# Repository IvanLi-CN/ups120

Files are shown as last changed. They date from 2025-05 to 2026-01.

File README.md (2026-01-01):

# UPS120 Firmware (Split Architecture)

This repository now hosts two firmware targets under a unified workspace:

- Smart Battery Controller: `STM32L051C8T6` (battery BMS + charger orchestration)
- UPS Main Controller: `ESP32S3FH4R2` (system coordination; active development)

Refer to [WORKFLOW.md](WORKFLOW.md) and [DESIGN_MEMORANDUM.md](DESIGN_MEMORANDUM.md) for project context.

Flashing/reset/log capture is routed through `mcu-agentd` (see `docs/mcu-agentd.md`).

## Repository Layout

- `firmware/smart-battery/`: Rust + Embassy firmware for `STM32L051C8T6`
- `firmware/ups-main/`: Rust firmware for `ESP32S3FH4R2` UPS main controller (active development)
- `embassy/`, `bq76920/`, `sc8815/`: Local dependencies and submodules

## Smart Battery (STM32L051C8T6)

- MCU: `STM32L051C8T6` (Cortex‑M0+)
- BMS: `BQ76920`
- Charger: `SC8815`
- Embassy setup: async I2C shared-bus; no USB on L0

I2C pins (per CubeMX .ioc):
- `I2C2` (INNER bus): `PB10` = SCL, `PB11` = SDA
- `I2C1` (SMBus alert mode enabled): `PB6` = SCL, `PB7` = SDA, `PB5` = SMBA

GPIO mapping (netlist‑accurate; the `.ioc` file is slightly stale):
- `PA9`: `PSTOP` (GPIO Output) — HIGH = power stage gated, LOW = enable
- `PA10`: `CE` (GPIO Output) — LOW = charger enabled
- `PA5`: `LEDK` (TIM2_CH1 alternate, open‑drain LED in firmware)
- `PA2`: `PCHG_EN` (GPIO Output)  *(per .ioc; see PCB netlist for the exact pad)*
- `PA0..PA3`: `ADC_IN0..3` for the 4× NTC network (`TS45`/`TS34`/`TS23`/`TS12` → pack temperatures)
- `PH0`: `EXIT_SHIPMODE` (GPIO Output) — routed via D3 clamp onto BQ76920 `TS1`, used to wake from SHIP mode
- `PB1`: `ALERT` (EXTI1)
- `PB2`: `INNER_INT` (EXTI2)

### Build & Run

From the repository root:

1) Ensure targets are installed: `rustup target add thumbv6m-none-eabi`
2) Build: `just sb-build`
3) Flash: `just sb-flash`
4) Monitor: `just sb-monitor`

Notes:
- The on-target workflow is mediated by `mcu-agentd` (do not call `probe-rs` directly).
- If you use a custom `CARGO_TARGET_DIR`, update `mcu-agentd.toml` accordingly.

### Notes on Port

- Migrated from `STM32G431` to `STM32L051C8T6` feature flags in `embassy-stm32`.
- Removed USB stack/tasks; L051 parts do not provide USB FS.
- I2C runs at 100 kHz async; DMA channel placeholders may be adjusted per board.

## UPS Main (ESP32S3FH4R2)

`firmware/ups-main` is an actively developed Rust firmware using `esp-hal` on ESP32-S3. System coordination, fan control, and I2C integrations (e.g., smart‑battery telemetry) are incrementally landing here.

### Build & Run

From the repository root:

1) Build: `just ups-build`
2) Flash: `just ups-flash`
3) Monitor: `just ups-monitor`

## License

MIT — see [LICENSE](LICENSE).

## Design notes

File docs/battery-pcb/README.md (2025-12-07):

# Smart Battery Module

## Overview

The smart battery board manages a 5-series stack of 26650 cells for the UPS120 platform. A TI **BQ7692003** analog front end measures every cell tap, while the PCB routes each tap through 100 ohm / 1 uF RC filters to keep the monitor within its input slew limits. The stack exports `BAT` as the pack positive node and `BGND` as the pack negative reference.

## Cell and Pack Specifications

- **Cell**: Planned 26650-format LiFePO₄ cell rated 3.2 V nominal, ~4.0 Ah capacity, ≤25 mΩ internal resistance, and up to 5C discharge capability (per supplied datasheet).
- **Environmental limits**: Charge temperature 0 °C to 45 °C per the cell spec; project discharge temperature currently constrained to 0 °C to 50 °C to preserve lifespan.
- **Physical**: Cylindrical can ~26 mm × 65 mm, mass approximately 85 g ± 2 g.
- **Pack topology**: 5-series, 1-parallel (5S1P) stack managed by the board’s cell monitor.
- **Pack ratings**: Nominal voltage about 16 V (5 × 3.2 V) with planned operating window 12.5 V (discharge cutoff) to 18.0 V (charge cutoff). Total energy around 64 Wh at nominal capacity.
- **Charge cutoff**: System charger terminates near 18.0 V pack, equivalent to ~3.6 V per cell, consistent with the cell datasheet limit.
- **Discharge cutoff**: Smart-battery firmware configures the BQ7692003 undervoltage trip at 2.50 V per cell (`firmware/smart-battery/src/main.rs:201`), producing the 12.5 V pack cutoff target above.
- **Charging architecture**: On-board charger regulates pack current at approximately 1 A with constant-current/constant-voltage behavior coordinated by the MCU.
- **Continuous current**: Power-stage sizing currently aligns with the cell’s 5C guidance (~20 A) while considering MOSFET thermal headroom and shunt limits; adjust fuse/shunt if future validation dictates tighter limits.

## Functional Blocks

- **Protection and switching** - A TI **BQ76200** high-side driver coordinates the charge, discharge, and pre-charge MOSFET banks. The low-value current-sense shunt between `BGND` and `GND` captures pack current, while a resettable fuse protects the housekeeping supply input.
- **Temperature sensing** - The PCB includes an optional 10 kΩ NTC footprint on the BQ7692003 TS1 pin, but **current production hardware does not populate this device**. BQ7692003 is configured to use its internal temperature sensor only; pack temperatures come from the 4× external NTC network into the STM32 ADC plus the TMP75 near the charger.
- **Housekeeping power** - A **TPS62933** buck converter drops the pack voltage to the `3V3_OUT` rail through a shielded inductor and bulk storage capacitor. An **LM66100** ideal diode isolates the regulated `3V3` rail, allowing external 3.3 V injection via the VBUS header without back-feeding the buck. Distributed 1 uF and 100 nF capacitors decouple the MCU and analog front ends.
- **System controller** - An **STM32L051C8** MCU supervises the AFE through an internal I2C bus and bridges to the host-facing bus. A resistor network provides 3.3 V pull-ups, and dedicated alert and interrupt lines land on the MCU for fault handling.
- **External interfaces** -
  - 1.0 mm 5-pin harness reserved for internal signal acquisition, carrying the monitored I2C pair plus the alert line, 3.3 V reference, and return.
  - 1.0 mm 4-pin SWD header dedicated to MCU debug access (`SWDIO`, `SWCLK`, supply, return).
  - 2.54 mm 4-pin power inlet routed to the on-board charger, intended for the external charger supply input (VBUS and ground pairs).
  - Dual 6-pin high-current terminals exporting the battery stack positive and negative nodes for pack integration.
- **User interaction** - A top-side reset switch reaches the MCU reset pin, while dedicated LED driver outputs fan out for front-panel indicators.

## Reference Netlist

The schematic netlist exported from EasyEDA lives in `netlist_battery.enet`. Each component entry includes manufacturing metadata (LCSC code, footprint ID, datasheet URL) to keep fabrication and BOM exports aligned with the PCB project.

## Directory Layout

- [`README.md`](README.md) - High-level description of the smart battery PCB (this file).
- [`netlist_battery.enet`](netlist_battery.enet) - EasyEDA JSON netlist for the smart battery design.
- [`tps62933_enable_control.md`](tps62933_enable_control.md) - Notes about the TPS62933 enable and power-sequencing logic.
- [`vbats_cutoff_calibration.md`](vbats_cutoff_calibration.md) - SC8815 VBATS divider hardware plus 18 V charge-cutoff calibration procedure.
- [`hardware_protection_tps3823_tmp75.md`](hardware_protection_tps3823_tmp75.md) - Consolidated hardware fault-chain design notes (final build uses scheme D: TMP75 + MCU AND gating).
- [`battery_temp_sensing.md`](battery_temp_sensing.md) - Analog temperature sensing topology for the pack.
- [`component-candidates/`](component-candidates) - Sourcing digests and option tables ([`schmitt_trigger_nand_options.md`](component-candidates/schmitt_trigger_nand_options.md), [`nand_gate_options_youxin.md`](component-candidates/nand_gate_options_youxin.md), [`or_gate_options_youxin.md`](component-candidates/or_gate_options_youxin.md), [`single_inverter_options.md`](component-candidates/single_inverter_options.md), [`three_input_and_gate_options_youxin.md`](component-candidates/three_input_and_gate_options_youxin.md), [`temperature_protection_tmp.md`](component-candidates/temperature_protection_tmp.md), [`watchdog_pricing_taobao.md`](component-candidates/watchdog_pricing_taobao.md), [`youxin_schmitt_single_nand.md`](component-candidates/youxin_schmitt_single_nand.md)).

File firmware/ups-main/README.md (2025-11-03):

# UPS Main Controller (ESP32-S3)

This directory contains the UPS main controller firmware targeting `ESP32‑S3` (Rust + esp-hal for MVP; versions aligned with the reference project).

- Toolchain: Rust + esp-hal (Xtensa). Requires `espflash`, Xtensa toolchain, and `xtensa-esp32s3-none-elf` target.
- Hardware docs:
  - `docs/mcu_hardware.md` (schematic transcription + verified GPIO mapping)
  - `docs/fan_control_spec.md` (2-wire fan control specification)
  - `docs/fan_control_requirements.md` (current fan-control requirements & acceptance checklist)
  - `docs/archive/pwm_fan_control_circuit_design.md` (legacy 3-wire fan design for reference)
  - `docs/datasheets/HUSB305-01.md` + `.pdf` (Type‑C source controller STAT/PG behavior)
- Build:
  - `make -C firmware/ups-main build` (or `ups-build` at repo root)
  - Flash + monitor: `make -C firmware/ups-main run PORT=/dev/tty...` (or `ups-run` at repo root)
- Status: MVP bring‑up scaffolded (GPIO/I2C/SPI/LEDC init; beep + fan smoke test).

Pin mapping in code follows `docs/mcu_hardware.md` exactly:
- Buttons (pull‑up): GPIO0/1/2/4/5
- RESET#(TCA6408A): GPIO6 (output-high)
- INTn (open-drain, low‑active): GPIO7 (input pull‑up)
- I2C0: SDA=GPIO8 SCL=GPIO9 @400kHz
- SPI LCD: DC10 MOSI11 SCLK12 CS13 RST14
- USB2_PG: GPIO21 (input pull‑up)
- FAN: EN=GPIO39, PWM=GPIO40@25kHz
- BUZZER: GPIO38@2kHz

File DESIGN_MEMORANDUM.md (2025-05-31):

# Design Memorandum - UPS Project

This document records key design decisions, observations, and debugging notes for the UPS project firmware.

## BQ25730 Configuration and ADC Readings

### Initial `cell_count` Configuration for BQ25730

* **Decision (User Input)**: The `cell_count` parameter passed to `Bq25730::new()` in the firmware is intentionally set to `4`.
* **Rationale**:
  * The BQ25730 is primarily designed for 3.7V/4.2V Li-ion cells. Configuring the `CELL_BATPRESZ` pin for a 5-cell LiFePO4 pack might lead to a default overvoltage protection (OVP) setting around 21V if interpreted as 5S Li-ion.
  * To ensure a safer default OVP level (e.g., around 16.8V for 4S Li-ion) upon initial power-up or in case of I2C communication failure before full configuration, a 4-cell equivalent hardware/default configuration is preferred.
  * The intention is to then use I2C commands to fine-tune all necessary parameters (charge voltage, current, protection thresholds) to precisely match the 5S LiFePO4 battery pack (e.g., ~18V charge voltage).
* **Implication**: This means the firmware must correctly adjust all relevant settings via I2C to override any 4-cell defaults and properly manage the 5S LiFePO4 pack. The `cell_count` parameter passed to `Bq25730::new()` directly influences the `offset_mv` used in `VBAT` and `VSYS` ADC conversions within the `bq25730_async_rs` driver. If the hardware `CELL_BATPRESZ` configuration implies a different cell count than what's passed to `new()`, this can lead to ADC reading inaccuracies.

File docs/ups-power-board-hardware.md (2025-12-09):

# UPS 电源板硬件概览

## 总览

- 电源板通过多条控制与监测线缆连接至 ESP32 主控，承担 UPS 外部输入调节、放电路径控制与状态监测职责。
- 板上核心器件包括电源转换、热管理、输入保护以及电流电压测量等子系统。

## 关键器件清单

| 器件 | 主要作用 | 关键接口 / 配置 |
| --- | --- | --- |
| SC8815 | UPS 放电升/降压，稳定输出电压 | `CE`、`PSTOP`、`ADIN` |
| TCA6408A | 通过 I²C 扩展数字 IO，驱动/侦测 UPS 状态 | `P0`–`P7`、`RESET#`、I²C 地址 `0x20` |
| TPS2490 | 受控热插拔控制器，管理外部输入使能 | `EN`、`PG` |
| INA226 | I²C 功率监测，测量 UPS 外部输入功率 | `SDA`、`SCL`、`Alert` |
| FNTC0402X103F3380FB | 与 SC8815 形成热感测电路的 NTC 热敏电阻 | `ADIN` |
| 43 kΩ 上拉电阻 | 为 SC8815 `ADIN` 提供 3.3 V 基准 | `ADIN`、`3V3` |

## 互连关系

- **SC8815**
  - `ADIN` 同时连接 FNTC0402X103F3380FB NTC 和 43 kΩ 上拉电阻，组成温度分压网络。
  - `CE`（芯片使能）与 `P1`（TCA6408A 口线）相连，ESP32 可经 I²C 控制启停转换。
  - `PSTOP` 与 `P2`（TCA6408A）连接，用于控制放电停止逻辑。

- **TCA6408A I/O 扩展器**
  - 经 I²C 总线 (`SCL`/`SDA`) 连至 ESP32 主控。
  - I²C 地址配置为 `0x20`（A0–A2 接地）。
  - `P0` 读取/驱动 `IN_PG` 网络，实现输入电源良好状态反馈。
  - `P1` 输出控制 SC8815 `CE`。
  - `P2` 输出控制 SC8815 `PSTOP`。
  - `P3` 连接智能电池 `ALERT`（透传到 BQ76920），用于异常报警。
  - `P4`–`P7` 当前悬空未使用。
  - `RESET#` 由 ESP32 直接驱动，确保 I/O 扩展器复位同步。

- **TPS2490 热插拔控制器**
  - `EN` 接 `IN_EN` 网络；低电平时切断 UPS 外部输入。
  - `PG` 为开漏 Power Good 指示脚，由 TPS2490 根据外部功率 MOSFET 的 `VDS` / 启动状态机 / 保护状态综合判定；导通良好时释放为高（上拉后读到高电平），启动中、UVLO、限流或保护时拉低。
  - `PG` 直接并入 `IN_PG` 网络，送至 TCA6408A `P0` 与 ESP32，仅表达“输入功率路径是否被判定为良好”，并不等同于“适配器电压存在”。

- **INA226 功率监测**
  - 与 ESP32 共享 I²C 总线，实时报告 UPS 外部输入电压、电流与功率。
  - `Alert`（若使用）可与 TCA6408A 或 ESP32 中断输入共享，辅助告警逻辑。

- **ESP32 主控**
  - 通过 I²C 控制 TCA6408A 与 INA226，间接管理 SC8815 放电和输入监测。
  - 直接线控 TCA6408A `RESET#` 以及 `IN_EN` 网络（若由 ESP32 驱动 TPS2490 EN）。

## 信号网络简述

- `IN_EN`：由 ESP32 控制，使 TPS2490 允许或切断外部输入。
- `IN_PG`：TPS2490 `PG` 开漏指示，馈入 TCA6408A `P0` 与 ESP32，表示“功率 MOSFET 路径良好/未处于保护”，不直接代表外部母线电压是否超过某阈值。
- `ALERT`：智能电池（BQ76920）故障或保护触发时输出高电平，通过 TCA6408A `P3` 传回 ESP32。
- `ADIN`：SC8815 热补偿输入，结合 NTC 与 43 kΩ 上拉监控温度。

## AC GOOD 信号路径概览

- **PG 原始层**：TPS2490 `PG`（开漏，良好时被上拉为高）→ `IN_PG` 网络 → TCA6408A `P0` → `in_pg_raw`（固件中读取的布尔，保留原始电平含义）。
- **电压在线层**：INA226 通过同一 I²C 总线测量输入母线电压，固件字段 `vin_meas_mv`；布尔 `vin_online`（推荐命名）= `vin_meas_mv > UPS_VBUS_AC_ONLINE_MV = 11.5 V`。
- **综合 AC GOOD 层**：`power::power_task` 将 `PG` 语义化布尔（建议名 `pg_asserted`）与 `vin_online` 组合得到 `ac_present`，并施加 10 s 稳定窗口得到 `ac_stable`。UI、充电/放电策略均消费 `ac_present` / `ac_stable`，不直接使用 `IN_PG`。

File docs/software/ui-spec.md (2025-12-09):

# UPS120 屏幕显示规范（v1）

适用硬件：160×50 像素、16 位 RGB565 屏。

本规范定义：坐标系、色彩与文本规范、公共组件、启动屏行为、仪表盘布局与数据格式、故障显示规则与更新频率。目的是在受限像素与带宽下保证一致、清晰、可靠的显示。喵～

## 1. 屏幕与坐标

- 分辨率：`160(w) × 50(h)` 像素，坐标原点在左上角。
- 颜色：RGB565（`rrrrr gggggg bbbbb`）。推荐调色板见下。
- 安全边距：左右各 `4px`，上下各 `1px`；在 `1 + 4×12 = 49` 的排版中仍保留 1px 余量用于呼吸空间。
- 建议基准网格：`8×12` 像素字符格（宽度 8px、行高 12px，包括 7×10 字形与 2px 行距），全屏可视为约 `20 列 × 4 行` 的等宽布局。

## 2. 调色板与语义颜色（含元素色常量）

为减少抖动与提升可读性，限定小而稳定的色表：

- `BLACK`  0x0000 背景、遮罩
- `WHITE`  0xFFFF 主要文字
- `GRAY`   0x8410 次要文字/分隔线
- `GREEN`  0x07E0 正常/进度条填充、功率（Power）
- `YELLOW` 0xFFE0 警告（高温、接近阈值）
- `ORANGE` 0xFD20 电压（Voltage）
- `RED`    0xF800 故障/禁止、电流（Current）
- `CYAN`   0x07FF 数据标题与单位点缀

色彩使用规则：

- 背景始终为黑色（启动屏、仪表盘一致）。
- 标题/标签使用 `CYAN`；单位默认 `WHITE`。
- 进度条填充 `GREEN`，异常改为 `RED`。
- 警戒区间（如温度接近上限）可将数值着色为 `YELLOW`。
- 元素专色（仪表盘）：
  - 电压（V）→ `ORANGE`
  - 电流（A）→ `RED`
  - 功率（W）→ `GREEN`

## 3. 字体与排版

- 字体：等宽 `7×10` 点阵，字符格宽 `8px`、行高 `12px`（其中 2px 作为行间距/前导）；示意图与固件渲染均使用同一套位图字形，禁用抗锯齿。
- “℃”绘制：在 `C` 前方 3px 位置放置一个 `2×2` 的度数点（顶边位于基线之上 1px），再绘制 `C` 字形，确保像素对齐。
- 数值与单位必须紧邻：如 `48.0V`、`120W`、`32C`、`45%`。
- 对齐：
  - 标签左对齐，数值列右对齐/定宽；
  - 四行均使用 `y = 1 + n×12` 的基线，保证跨模式切换时不抖动。
- 省略或无数据统一显示为 `--`，与标签留一个字符格间距。
- 单元宽度：所有文字均落在 `8px` 宽度的字符单元上，默认列宽如下（括号内为示例）：
  - 标签列：`4` 单元（`IN␠␠`，两格空白确保对齐）。
  - 电压列：`5` 单元（`12.3V` / `9.87V` / `>99V`）。
  - 电流列：`4` 单元（`2.5A` / `12A` / `>99A`）。
  - 功率列：`4` 单元（`120W`，>999W 时显示 `999W`）。
  - `SoC`：`4` 单元右对齐（`85%` / `100%`）。
  - 温度：`4` 单元（`-9C` / `105C`，附带 2×2 度数点）。
  - 风扇：`4` 单元（`45%` / `100%`）。

### 3.1 字段字符宽度约束

| 项目 | 字符宽度 | 说明 |
|---|---|---|
| `MODE:` 标签  | 6 | 固定文案，冒号后带一个空格。 |
| `IN` 标签 | 4 | 文案后补足 2 个空格（`"IN  "`），用于对齐行内数值。 |
| `OUT`/`CHG` 标签 | 4 | 文案后保留 1 个空格即可（`"OUT "`、`"CHG "`）；无需额外对齐。 |
| `SoC` 电量 | 4 | 右对齐显示 `85%`；`100%` 时占 4 字符。 |
| 电压 | 5 | 常规 `12.3V` ~ `21.0V`，格式 `xx.xV`；`≥100V` 时退化为 `>99V`。 |
| 电流 | 4 | `<10A` 用 `x.xA`；`10A~99A` 用整数（`12A`）；`≥100A` 显示 `>99A`。 |
| 功率 | 4 | `xxxW`；`≥1000W` 时夹止为 `999W`。 |
| 温度 | 4 | `32C` / `-5C` / `105C`，取值范围 `-99`～`199`；度点独立 2×2。 |
| 风扇转速 | 4 | `45%` / `100%`，右对齐；无数据时显示 `--%`。 |

所有行内间隔默认 1 个字符单元（8px），仅在需要强调分隔时再留出额外空白，但严禁与数值列重叠。

## 4. 公共组件

### 4.1 分隔线（可选）

- 颜色 `GRAY`，`1px` 水平线，用于分区但不喧宾夺主。

### 4.2 进度条（启动屏使用）

- 外框：宽 `152px`、高 `8px`，居中放置，左右/上下各留安全边距。
- 填充：`GREEN` 自左向右增长；错误态保持在当前进度并改为 `RED`。
- 百分比文本（可选）：在进度条上方居中显示，如 `INIT 72%`。

## 5. 启动屏（Boot）

用途：硬件上电后硬件自检与外设初始化阶段的显示。背景黑色。

示意图（像素网格放大显示；已调整避免文本与进度条重叠）：

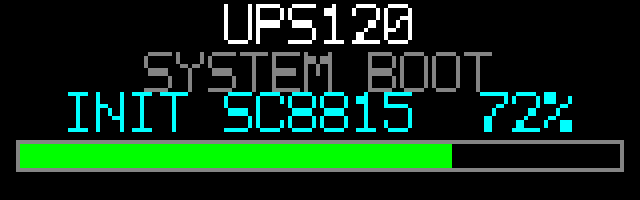
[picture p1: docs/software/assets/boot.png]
Boot Screen Mockup


显示元素：

- 标题（第一行居中）：`UPS120` 或项目名（白色）。
- 子标题（可选，次要信息）：`System Boot` 或版本号（灰色）。
- 进度条：见 4.2。
- 状态行（底部或进度条上方一行）：显示当前步骤名称（如 `Probe INA226`、`Init SC8815` 等）。

行为流程：

1. 上电进入启动屏，进度自 `0%` 增长至 `100%`。
2. 每完成一个外设/模块自检或初始化步骤，进度递增并更新状态行。
3. 若所有步骤成功（100%）：
   - 进度条填满后停留 `300–600ms`，自动切换至仪表盘。
4. 若任一步骤失败（设备故障）：
   - 停留在启动屏，不跳转。
   - 进度条颜色切换为 `RED`；
   - 状态区域列出具体故障硬件（见下“故障显示”）。

故障显示规范：

- 标题：`Hardware Fault`（红色）。
- 列表逐条显示（白色标签 + 红色状态）：
  - `Battery MCU (STM32L051): FAIL`
  - `SC8815: FAIL`
  - `TCA6408A@0x20: FAIL`
  - `INA226: FAIL`
- 多故障时按优先级排序（上至下）：`Battery MCU > SC8815 > INA226 > TCA6408A > 其他`。
- 若存在可恢复性建议（例如松脱/重插），可在底部灰色小字提示；不做交互决策（按键处理由上层定义）。

数据对接（建议）：启动阶段各子系统上报 `step_id`、`step_name`、`ok/err`，UI 侧映射进度百分比；错误时附 `fault_list`。

## 6. 仪表盘（Dashboard）

作为主屏幕常驻界面，显示系统状态与关键电参。采用“四行”布局，提升在 160×50 下的可读性与留白。第一行右上角“电池电量区域”轮播显示：

- 电量百分比（`SoC %`）
- 电池包电压（格式 `xx.xV`，示例 `16.1V`）

轮播节奏默认每 2 秒切换一次；当任一数据不可用时显示 `--` 并继续轮播。

示意图（像素网格放大显示；四行布局，元素着色且控宽不越界）：

- 放电（第三行显示 SC8815 测得的 OUT 三元组）：
  
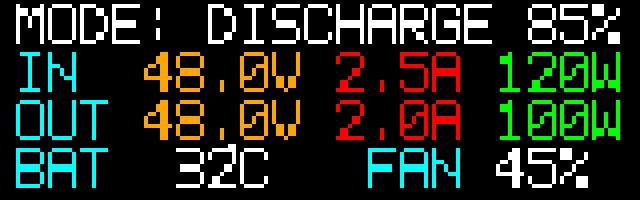
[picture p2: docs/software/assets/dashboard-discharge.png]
Dashboard Discharge
  

- 充电（第三行显示 CHG 功率）：
  
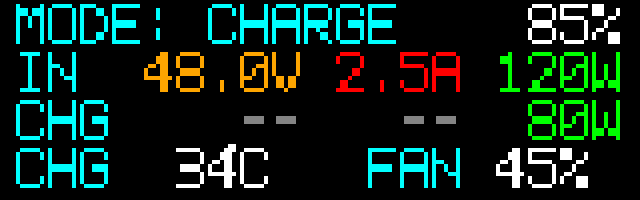
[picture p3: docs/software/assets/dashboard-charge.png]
Dashboard Charge
  

- 就绪（第三行显示自上次放电结束的时长）：
  
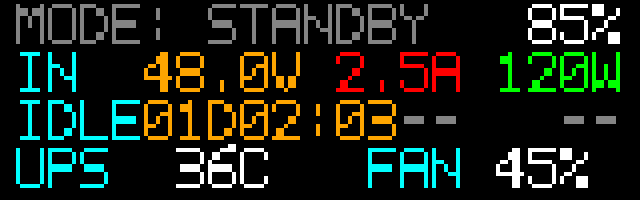
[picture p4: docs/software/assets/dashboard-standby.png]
Dashboard Ready
  

- 智能电池故障（第四行切换为故障视图，显示 `FAULT: <code>`）：
  
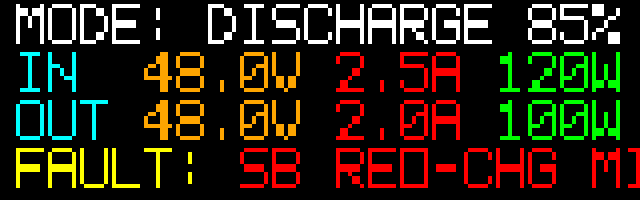
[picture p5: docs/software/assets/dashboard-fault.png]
Dashboard Fault
  

### 6.1 显示内容（必选）

- 工作模式（文本）：`Charge` / `Ready` / `Discharge` / `LowBatt`。
- 输入电压（V）。
- 输入电流（A）。
- 输入功率（W）。
- 充电功率（W，非充电则 `--`）。
- 输出电压（V）。
- 输出电流（A）。
- 输出功率（W）。
- 电池温度（℃，显示为 `BAT xx℃`）。
- UPS 温度（℃，来自 SC8815 的 ADIN，显示为 `UPS xx℃`）。
- 风扇转速（%，按逻辑占空比换算）。

#### 模式语义与判定规则

- 所有 `MODE` 状态均由 UPS 主控 ESP32 决策；STM32 智能电池板只提供测量数据（分节电压/电流/温度、`STATE_FLAGS`、`CHG_PAUSE_CAUSE` 等）和一致性校验，不直接驱动 UI 模式切换。
- AC 状态来源固定为 `PowerState.ac_present / ac_stable / vin_meas_mv`（由 TPS2490 PG + INA226 组合，见 `charging_policy.md`），UI 不使用 STM32 `STATE_FLAGS.AC_PRESENT`。
- ESP32 在电源任务中基于自身维护的 `PowerState`（AC/OUT 状态、单体/包电压、温度等）以及内部 `out_enabled`、充放电策略状态裁决 `mode` 字段，并将该字段作为唯一权威的仪表盘模式喂给 UI。

- 四种工作模式语义：
  - `Charge`：检测到 AC 存在且充电策略允许时（`vin_ok_for_charge=true` 且电池/温度安全），进入充电模式；第三行采用 `CHG <功率>` 布局。
  - `Discharge`：`out_enabled=true` 且功率实际流向负载时（由 UPS 侧 SC8815 的 OUT 测量确认），进入放电模式；第三行采用 `OUT <V/A/W>` 布局。
  - `Ready`：不充不放（既未处于 Charge 也未处于 Discharge），OUT 功率级可随时开启，电池与系统健康且未触发 LowBatt；第三行采用 `IDLE <时长>` 布局，时长统计自上次放电结束起。
  - `LowBatt`：在基础模式为 Ready 的前提下，仅用于表示“电量偏低但当前没有 AC 可用”的状态；第三行继续沿用 Ready 或 Discharge 的布局，仅通过第一行 `MODE: LOWBATT` 与 SoC 颜色强调电量低。

- `LowBatt` 触发规则：
  1. 先按上述规则判定基础模式为 `Ready`；
  2. 若此时任意一节电芯电压 `< 3.2V`，进入“电量低流程”；
  3. 在电量低流程中（`ac_present` 由 TPS2490 PG + INA226 VIN 判定，详见 `charging_policy.md`）：
     - 若 `ac_present = true`：ESP32 不进入 `LowBatt`，而是直接切换到 `Charge` 并按充电策略尝试启动充电；
     - 若 `ac_present = false`：ESP32 才将 MODE 切换为 `LowBatt`，表示“电池很想充但没有 AC 可用”，UI 以 `MODE: LOWBATT` + SoC 变红提示。

### 6.2 四行布局（示意）

```
┌──────────────────────────────────────────────────────────────┐
│ MODE: DISCHARGE                                  85%        │  ← 行1（状态+右上角电量区，右对齐；轮播 % 与 V）
├──────────────────────────────────────────────────────────────┤
│ IN  48.0V 2.5A 120W                                        │  ← 行2（输入三元组：标签 4 单元 + 5/4/4 列）
│ OUT 48.0V 2.0A 100W                                        │  ← 行3（放电：输出三元组同列宽）
│ BAT    32C   FAN  45%                                      │  ← 行4（温度槽位轮播 + FAN，列宽 4/4/3/4；无故障时）
└──────────────────────────────────────────────────────────────┘
```

说明：

- 行1：左侧 `MODE: <Charge|Ready|Discharge|LowBatt>`；右上角电量区轮播显示 `SoC %` 与电池电压 `xx.xV`。`SoC` 按阈值变色（≤30% `YELLOW`，≤15% `RED`）；显示电压时使用电压专色 `ORANGE`。
- 行2：输入三元组（V/A/W，专色显示，见 6.4）。
- 行3：按模式动态显示（**由 ESP32 主控单向裁决**；STM32 智能电池仅作为测量与一致性校验来源，不参与模式判定）：
  - 充电（`Charge`）时：显示 `CHG <功率W>`（功率数字用 `GREEN`），其余两列以 `--` 灰显。
  - 就绪（`Ready`）时：显示 `IDLE <时长>`，时长格式 `DDdHH:MM`（例如 `01d02:03`），未使用列显示 `--`。
  - 放电（`Discharge`）时：显示 `OUT <V/A/W>`，数值来自 SC8815 的测量。
  - 电量低（`LowBatt`）时：第三行布局**不因电量低而改变**：
    - 若当前仍在放电（`out_enabled=true` 且有实际功率输出），第三行继续使用 `OUT <V/A/W>`；
    - 若当前处于就绪（未放电），第三行继续使用 `IDLE <时长>`。
    `LowBatt` 仅通过第一行 `MODE: LOWBATT` 和 SoC 变红提示电量低，避免第三行再引入额外文案变化。
- 行4：温度/风扇信息：`BAT`（电池）、`UPS`（UPS/SC8815 ADIN）、`FAN`（百分比）。当检测到智能电池或充电链路故障时，行4整体切换为“故障视图”，不再显示温度/FAN。
- 各行基线为 `y = 1 + 行号×12`（0-index），字符上边缘对齐，行间保持 2px 呼吸空间。
- 行4温度轮播：每帧在 `BAT` 与 `UPS` 之间切换，仅展示一个温度槽位，右侧固定 `FAN` 列；示例固件以 2 秒刷新一次，可按需求缩短至 1 秒；当任一温度不可用时显示 `--` 并继续轮播。

两列对齐与等宽：

- 标签列（`MODE/IN/OUT/CHG/IDLE/BAT/UPS/FAN`）左对齐，数值列右对齐；单位紧贴数值。
- 固定列宽：标签 `4` 单元 → 电压 `5` 单元 → 电流 `4` 单元 → 功率 `4` 单元，列间默认 `1` 单元间隔；右上角电量区：
  - 展示 `SoC %` 时占 `4` 单元（例如 `85%`）。
  - 展示电压时占 `5` 单元（例如 `16.1V`）。
  - 布局需保证右上角 5 单元不与左侧 `MODE` 文本发生重叠；当空间不足时应截断 `MODE` 文本末尾字符以避免覆盖（优先保证电量区完整显示）。
- `IN` 等标签不足 4 字符，通过尾部空白补齐，确保电压列起始对齐；数值在列内右对齐，空白自然留在左侧。
- 行4 使用 `4/4/3/4` 单元布局（温标签/温值/FAN 标签/FAN 数值），与上方三行保持同一字符网格。
- 占位符统一为 `--`，渲染时使用 `GRAY`；`FAN` 无可用数据时显示 `--%`。

### 6.3 数值格式与单位

- 电压（V）：
  - `<10V`：`x.xxV`，保留两位小数（如 `9.87V`）。
  - `10V–99.9V`：`xx.xV`，保留一位小数（如 `48.0V`）。
  - `≥100V`：显示 `>99V`，提示超出量程。
- 电流（A）：
  - `<10A`：`x.xA`，保留一位小数（如 `2.5A`）。
  - `10A–99A`：整数右对齐（`12A`），不带小数。
  - `≥100A`：显示 `>99A`。
- 功率（W）：四舍五入到整数，右对齐显示 `xxxW`；超过 `999W` 时夹止为 `999W`。
- 温度（℃）：整数（`32C` / `-5C` / `105C`），附带 2×2 度数点；数据范围限制在 `-99`～`199`℃。
- 风扇（%）：整数右对齐（`45%` / `100%`）。
- 未知/无效：统一输出 `--`（温度 `--C`，风扇 `--%`，其他列 `--`）。

### 6.4 着色规则（含元素专色）

- `MODE`：`Charge` 用 `CYAN`，`Discharge` 用 `WHITE`，`Ready` 用 `GRAY`，`LowBatt` 用 `RED`。
- 元素专色：电压 `ORANGE`、电流 `RED`、功率 `GREEN`（数字部分用专色，单位可留 `WHITE`）。
- `SoC` 电量：默认 `WHITE`；`≤30%` 用 `YELLOW`，`≤15%` 用 `RED`。
- 温度：
  - `≥ 45C` 着 `YELLOW`；
  - `≥ 55C` 着 `RED`。
- 风扇：`≥ 90%` 用 `YELLOW` 提醒高负载。
- 故障行：前导警告图标与 `FAULT:` 标签使用 `YELLOW`，严重故障（例如 BQ/SC 硬故障或通信错误）对应的故障代码文本使用 `RED`。

### 6.5 更新频率与去抖

### 6.6 智能电池故障视图（Dashboard 第 4 行）

当存在智能电池相关故障时，仪表盘第 4 行从常规温度/FAN 行切换为“故障视图”，整体布局调整为：

```text
┌──────────────────────────────────────────────────────────────┐
│ MODE: DISCHARGE                                  85%        │
├──────────────────────────────────────────────────────────────┤
│ IN  48.0V 2.5A 120W                                        │
│ OUT 48.0V 2.0A 100W                                        │
│ FAULT: REQ-CHG MISM                                        │  ← 行4 故障视图（故障标签 + 故障代码）
└──────────────────────────────────────────────────────────────┘
```

#### 6.6.1 警告图标示意

- 为简化字库要求与实现，故障行前不额外绘制独立图标；
- 第 4 行从第 0 列直接输出 `FAULT:` 标签和故障代码，通过颜色区分严重程度。

渲染示意（字符级）：

```text
│ FAULT: COMM ERR                                            │
   ↑
   └─ 固定标签
```

#### 6.6.2 故障代码取值与含义

`FAULT:` 之后显示一个短代码（最长约 12 字符），用来归一化各种智能电池/充电异常。建议集合如下（为避免越界，不再加 `SB ` 前缀，所有代码均默认为“智能电池相关”）：

- 通信 / 状态基础故障
  - `COMM ERR`：连续读取 `STATE_FLAGS` / `CHG_PAUSE_CAUSE` / 温度或电压窗口失败，或 STM32 不响应。
  - `STATE N/A`：能通信但始终读不到有效 `STATE_FLAGS`，视为状态快照不可用。
- 请求 / 实际不匹配（视为智能电池故障）
  - `REQ-CHG MISM`：ESP32 将 `MANUAL_ENABLE` 置 1（启用“由主机控制的充电通道”，UPS120 中表示主机当前允许充电），STM32 却长期报告 `CHARGING=0` 且既非 `FULL`、也无暂停/故障原因可解释。
  - `REQ-STOP MISM`：ESP32 将 `MANUAL_ENABLE` 清 0（禁止主机侧充电通道开启），STM32 仍报告 `CHARGING=1`。
- 温度相关故障（来自 `TEMP_STATUS` 与 CHG_PAUSE_CAUSE）
  - `TEMP LOW`：电池温度过低，`TEMP_STATUS.temp_low = 1`。
  - `TEMP HOT CHG`：充电路径过热，`TEMP_STATUS.temp_high_chg = 1`。
  - `TEMP HOT DSG`：放电路径过热，`TEMP_STATUS.temp_high_dsg = 1`。
- 电压/电流 / 适配器 / 失衡相关故障（来自 `CHG_PAUSE_CAUSE`）
  - `IMBALANCE`：`CHG_PAUSE_CAUSE.IMBALANCE = 1`，单体压差超过阈值，进入“短充+长均衡”策略。
  - `OV/UV/OC`：`CHG_PAUSE_CAUSE.OVUV_OC = 1`，存在过压/欠压/过流保护。
  - `ADAPTER MISS`：`CHG_PAUSE_CAUSE.ADAPTER_MISS = 1`，尤其在主控请求充电时应优先显示。
  - `HOLD-OFF`：`CHG_PAUSE_CAUSE.HOLD_OFF = 1`，当前处于重试冷却窗口。
- 芯片级故障（来自 `STATE_FLAGS` FAULT 位）
  - `FAULT BQ`：`STATE_FLAGS.FAULT_BQ = 1`，BQ76920 报告致命保护故障。
  - `FAULT SC`：`STATE_FLAGS.FAULT_SC = 1`，SC8815 报告致命故障或被 STM32 标记为不可用。

#### 6.6.3 故障优先级与回退

- 同一时刻可能存在多个故障源；仪表盘第 4 行只显示优先级最高的一条：
  1. 通信/状态故障：`COMM ERR`、`STATE N/A`
  2. 请求/实际不匹配：`REQ-CHG MISM`、`REQ-STOP MISM`
  3. 芯片级故障：`FAULT BQ`、`FAULT SC`
  4. 温度故障：`TEMP LOW / HOT CHG / HOT DSG`
  5. 电压/电流/适配器/失衡：`OV/UV/OC`、`ADAPTER MISS`、`IMBALANCE`、`HOLD-OFF`
- 故障行的出现与第一行 `MODE` 独立：无论当前处于 `Charge` / `Ready` / `Discharge` / `LowBatt` 中的哪一种，只要存在智能电池/充电相关故障，第四行就切换为 `FAULT: <code>`；MODE 始终由 ESP32 按前文规则裁决。
- 未检测到任何故障时：
  - 第 4 行恢复为常规温度/FAN 行：`BAT …C  UPS …C  FAN …%`；
  - 警告图标和 `FAULT:` 标签不渲染。

- 刷新周期：`5–10 Hz` UI 帧（避免 1 像素闪烁）。
- 数值更新：
  - 电压/功率使用 2–4 样本滑动平均；
  - 温度/风扇可直接刷新；
  - 当模式切换发生时，立即生效且清零相关缓存，避免“阴影值”。
- `CHG` 的判定：仅在 MODE=`Charge` 时显示充电功率；在 `Ready` / `Discharge` / `LowBatt` 模式下，第三行不使用 `CHG` 三元组，该字段可以为 `null` / `0` 或在 UI 层统一显示为 `--`。

## 7. 智能电池详情页（方向键向下）

用途：在仪表盘下按一次“方向键 ↓”进入，查看智能电池充/放状态、分节电压与分节温度，并在最后一行为电池相关告警预留空间。背景、字体与调色板沿用前述规范。

布局（摘要，完整细节见 `docs/software/batt-detail-design.md` 与第 11 节）：
- 行1：`BAT <CHG|DSG|IDLE> <VV.VV>V <II.I>A`，与仪表盘风格一致；
- 行2–3：电芯区，以 2 秒节奏在“电压帧 / 温度帧”之间轮播：
  - 电压帧：显示 1–5 号电芯电压，均衡中的电芯以 `YELLOW` 高亮（仅在电压帧中高亮，不再闪烁），其他为 `ORANGE`；
  - 温度帧：在相同几何位置显示 1–5 号电芯表面温度（由 4 NTC 推算），使用统一的度点 + `C` 字形，颜色始终为 `WHITE`；
- 行4：`WARN <code>` 告警行，仅显示 1 条优先级最高的短告警代码（如 `DSG HI` / `CHG HI` / `TEMP LO` 等），无告警时为 `WARN --`。

示例像素稿（160×50 点阵，放大 4× 展示）由 `docs/software/assets/gen_mockups.py` 生成：

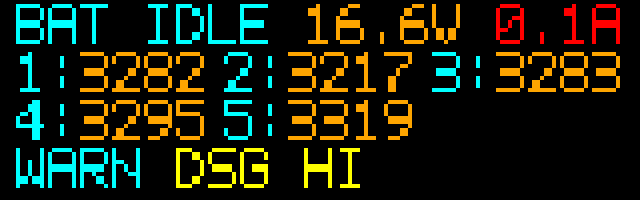
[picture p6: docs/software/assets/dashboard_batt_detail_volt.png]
Battery detail – voltage frame

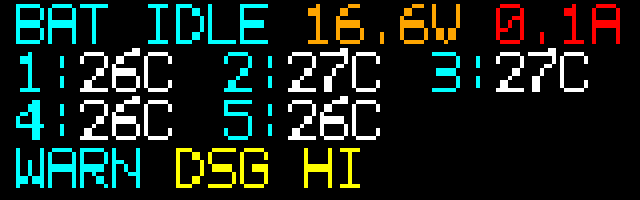
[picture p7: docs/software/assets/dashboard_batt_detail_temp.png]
Battery detail – temperature frame


交互：再按“方向键 ↑”返回仪表盘；其他按键行为遵循主界面定义。

## 8. 故障与降级显示（运行中）

运行中若检测到故障（与启动阶段同类）：

- 在行1右侧以红色短标签提示：例如 `FAULT: INA226`。
- 若影响主数据可信度（如输入计量丢失），对应数值显示 `--` 且置灰（`GRAY`）。
- 严重故障（如控制器失联）可切回启动屏风格的“错误覆盖层”（半屏/全屏），由上层策略决定是否冻结 UI。

## 9. 数据来源与字段（接口建议）

为便于上位逻辑与 UI 解耦，建议以结构化数据喂给 UI：

```json
{
  "mode": "Charge|Ready|Discharge|LowBatt",   // 仪表盘模式，由 ESP32 按本节规则裁决
  "soc_pct": 85,                          // 电池电量 0–100
  "input_voltage_mv": 48000,
  "input_current_ma": 2500,
  "input_power_mw": 120000,
  "charge_power_mw": 80000,               // 充电时用于第三行，非充电可为 null 或 0
  "output_voltage_mv": 48000,              // 放电时第三行 OUT 三元组（SC8815 测得/估算）
  "output_current_ma": 2000,
  "output_power_mw": 100000,
  "battery_temp_c": 32,
  "charger_temp_c": 34,                    // 智能电池充电器模块温度
  "ups_temp_c": 36,                        // SC8815 ADIN 转换后的摄氏度
  "fan_duty_pct": 45,
  "idle_since_last_discharge_s": 93780,    // 就绪（Ready）模式下用于格式化为 01d02:03
  "faults": ["SC8815", "INA226"],
  "boot": {                                // 仅启动阶段
    "step_id": 3,
    "step_name": "Init SC8815",
    "progress_pct": 72
  }
}
```

字段到显示的映射：

- `*_mv` → `V`（见 6.3 的小数位规则）。
- `*_mw` → `W`（整瓦）。
- `*_ma` → `A`（见 6.3 的小数位规则）。
- `fan_duty_pct` 直接百分比显示（0–100）。
- `soc_pct` 显示在第一行右上角（阈值着色见 6.4）。
- `idle_since_last_discharge_s` → `DDdHH:MM`（舍去秒）。
- `faults` 非空触发运行中故障提示；启动阶段非空即卡在启动屏。

## 10. 性能与带宽建议

- 全屏重绘上限：建议 ≤ 10 fps；优先“脏矩形”局部重绘（如数值区域）。
- 文本绘制缓存：常用标签（`IN/OUT/CHG/BTEMP/UTEMP/FAN/MODE`）预渲染到位图，减少合成开销。
- 进度条与数值采用整数像素运算；避免亚像素计算成本。

## 11. 质量基线与可测试性

- 文本与数字在极值下不重叠、不截断：
  - 电压最大 `999.9V`，功率最大 `9999W`，温度最大 `999C`，均应在列宽内展示。
- 当值非法（NaN、溢出、CRC 错误），显示 `--` 并在 6.4 的规则下可染色提示。
- 启动屏多故障列表在 160×50 下至少显示 3 条；溢出时滚动或分页（二选一，由实现决定）。

## 11. 智能电池详情页（方向键向下）

用途：从仪表盘按一次“方向键 ↓”进入，快速查看智能电池充/放状态、分节电压、分节温度与告警。背景、字体、调色板沿用前述规范。

布局（4 行，基线 `y = 1 + n×12`）：
- 行1：`BAT <CHG|DSG|IDLE> <VV.VV>V <II.I>A`（`BAT`/状态 `CYAN`，电压 `ORANGE`，电流 `RED`）。
- 行2–3：电芯区，2 秒轮播“电压帧 / 温度帧”，列宽固定不越界：
  - 列布局：列起点为字符格 `0 / 6 / 12`，每个电芯占 `6` 格：`<n>:`（2 格）+ 数值（最多 4 格）。
  - 电压帧：
    - 行2：电芯 1–3，示例：`1:3240 2:3217 3:3283`；
    - 行3：电芯 4–5，示例：`4:3295 5:3319`（第 3 槽留空）；
    - 数值存在时着色为 `ORANGE`，缺失时显示 `--`/`GRAY`；
    - 均衡中的电芯（`balancing_index` 命中）数值固定着色为 `YELLOW`，不再闪烁。
  - 温度帧：
    - 行2、3 的几何布局与电压帧完全一致，对应电芯仍为 1–3、4–5；
    - 数值格式：`<n>:<TT>C`，例如 `1:26C 2:27C 3:27C`；
    - 温度取值范围 `-99`～`199`，使用统一的 2×2 度点 + `C` 字形；缺失时显示 `--`/`GRAY`；
    - 温度来源：上层根据 4 个 NTC（每两个电芯间布置）推算出 5 节电芯表面温度后传入 UI。
  - 帧切换：UI 每 `2 s` 在“电压帧 / 温度帧”之间切换一次，仅替换数字与颜色，不改变起始列，避免水平抖动。
- 行4：告警行 `WARN <code>`：
  - 左侧标签 `WARN` 使用 `CYAN`，占 4 格（含冒号可选）；自第 5 格起显示 1 个短告警代码；
  - 当前建议代码：`TEMP LO` / `CHG HI` / `DSG HI` / `OVP` / `UVP` 等，由实现按优先级选择 1 个显示（例如 `DSG HI > CHG HI > TEMP LO`）；
  - 预警类告警使用 `YELLOW`，严重故障使用 `RED`；无告警时显示 `--`（`GRAY`）。

均衡显示：
- 电芯均衡时不再闪烁：仅在电压帧中将命中的电芯电压数值着色为 `YELLOW`，温度帧保持 `WHITE` 不变；
- 当 `balancing_index` 为 `None` 或对应电芯读数缺失时，不额外高亮。

示例资源（160×50 实际点阵）：
- 电压帧：`docs/software/assets/dashboard_batt_detail_volt.png`
- 温度帧：`docs/software/assets/dashboard_batt_detail_temp.png`

交互：再按“方向键 ↑”返回仪表盘；其他按键行为遵循主界面定义。

---

附：标签与缩写清单（等宽英字母，避免中日韩字库负担）：

- `MODE`、`IN`、`OUT`、`CHG`、`BTEMP`、`UTEMP`、`FAN`

这份规范已经将显示尺寸、颜色、排版、状态机与数据接口一并约束好啦。若主人有品牌标题或更具体的配色喜好，告诉心羽我就替你微调到位喵。

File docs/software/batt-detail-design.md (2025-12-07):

# 智能电池详情页功能设计（方向键向下）

本设计描述从仪表盘按一次“方向键 ↓”进入的智能电池详情页（BattDetail）的目标、数据来源、像素级布局与接口建议。本版方案取代旧的“温度占用第 4 行 + 电芯闪烁”设计，解决最后一行内容溢出问题，并增加分节温度与告警显示。

## 目标与范围

- 目标：
  - 在 160×50 像素屏幕内清晰展示电池充/放状态、分节电压、分节温度及关键告警；
  - 在不增加信息密度的前提下，避免任何一行文字溢出屏幕；
  - 去除电芯电压闪烁，仅通过颜色高亮均衡电芯。
- 范围：仅 UI 与输入流转设计；不改动硬件驱动与充放电控制策略。

## 数据与来源

- 模式 / 包电压 / 包电流：
  - 来源：现有主控字段（`BQ76920 → STM32 → ESP32`），`IBAT` 为 BQ76920 分流电流；
  - UI 侧按 `Option` 处理：读数缺失时显示 `--`。
- 分节电压：
  - 来源：BQ76920 逐节 mV，逻辑上支持 5 节；
  - UI 接口：`cells_mv: [Option<u16>; 5]`。
- 分节温度：
  - 物理：4 个 NTC，分布在相邻两节之间，可推测 5 节电芯表面温度；
  - 推荐在 STM32/ESP32 上游侧完成 NTC → 电芯温度的插值/映射；UI 只消费结果；
  - UI 接口：`cells_temp_c: [Option<i16>; 5]`（单位 ℃，-99～199，缺失为 `None`）；
  - 实际实现可复用 `smart-battery-ntc-temp-notes.md` 中的温度通路与哨兵值约定。
- 均衡节号：
  - 来源：智能电池 `STATE_FLAGS` 中的 “Balancing active” 标志 + 最高电压单节索引；
  - UI 接口：`balancing_index: Option<u8>`（1 基索引，无均衡时为 `None`）。
- 温度告警：
  - 来源：STM32 暴露的 `TEMP_STATUS`（参见 `TempFaultFlags` 结构）；
  - UI 侧从 `TempFaultFlags` 归一化为 1 个短告警代码，用于第 4 行。

刷新节奏与仪表盘一致：UI 任务约 2 Hz 更新一次 BattDetail 数据与重绘一帧。

## UI 布局（160×50，7×10 点阵，基线 y = 1 + n×12）

整体沿用 `ui-spec.md` 的 8×12 字符网格与安全边距（左右 4px、上下 1px），视为约 19 列 × 4 行的等宽布局。

### 行 1：包状态与总电参

文本形态：

```text
BAT <CHG|DSG|IDLE> <VV.VV>V <II.I>A
```

- `BAT` 与状态文本使用 `CYAN`；
- 包电压使用 `fmt_voltage`（专色 `ORANGE`）；
- 包电流使用 `fmt_current`（专色 `RED`）；
- 任一数值缺失时显示 `--` 并降为 `GRAY`；
- 该行与旧版一致，无需改动。

### 行 2–3：电芯区（电压 / 温度轮播）

电芯区采用固定的 3 列布局，每列宽度为 `6` 个字符格，并在列与列之间插入「半格」（4px）空隙：

- 第一列起点在字符格 0；
- 第二列起点 = 第一列起点 + 6 格宽度 + 0.5 格空隙；
- 第三列起点 = 第二列起点 + 6 格宽度 + 0.5 格空隙；

这样在 160px 宽度内仍能满足左右 4px 安全边距，不会触碰边框。

- 标签：`<n>:` 占 2 格，颜色 `CYAN`；
- 数值：占最多 4 格，右对齐；
- 每两列之间额外留出的半格空白用于视觉分隔，对应你实机截图里的“红色小三角”标的间距。

行号与电芯映射：

- 行 2：电芯 1–3；
- 行 3：电芯 4–5（第 3 槽留空）。

电芯区有两种“帧”，按 2 秒节奏轮播。

#### 1. 电压帧（CellsFrame::Voltage）

示例：

```text
1:3240 2:3217 3:3283
4:3295 5:3319
```

规则：

- 数值格式：`<mV>`，例 `3283` 表示 `3283 mV`；
- 颜色：
  - 有效读数 → `ORANGE`；
  - 缺失 → 显示 `--`，颜色 `GRAY`；
  - `balancing_index` 命中的电芯 → 数值改为 `YELLOW`（仅颜色变化，不闪烁）。

#### 2. 温度帧（CellsFrame::Temp）

示例：

```text
1:26C 2:27C 3:27C
4:26C 5:26C
```

规则：

- 几何布局与电压帧完全相同（起始列与列宽不变），保证轮播时无水平抖动；
- 数值格式：`<n>:<TT>C`，`TT` 为整度，范围 `-99`～`199`：
  - 显示上复用通用温度格式：数字 + 2×2 度点 + `C` 字形；
  - 有效温度 → 数字与 `C` 使用 `WHITE`；
  - 缺失 → 显示 `--`，颜色 `GRAY`，不绘制度点；
- 温度数据由 `cells_temp_c` 提供（上游负责 4 NTC → 5 电芯的映射），UI 不参与插值算法；
- 若某一电芯温度缺失，但相邻 NTC 仍有数据，上游可选择回退为邻近电芯温度，UI 不区分来源。

#### 3. 轮播节奏

- UI 任务每约 500 ms 更新一次 BattDetail 数据；
- `CellsFrame` 状态每累计 2 秒翻转一次（4 个 UI 周期）：
  - `Voltage → Temp → Voltage → …`；
  - 即在 2 秒内至少渲染 2 帧相同内容，避免抖动。
- 轮播状态应属于 UI 内部状态机，不通过 `BattDetailData` 结构对外暴露。

### 行 4：告警行（WARN）

文本形态：

```text
WARN <code>
```

规则：

- 标签 `WARN` 占 4 个字符格，颜色 `CYAN`；
- 第 5 格起显示 1 个短告警代码，最大长度约 10 字符，保证不越界；
- 建议告警代码与优先级：
  - `DSG HI`（放电高温）；
  - `CHG HI`（充电高温）；
  - `TEMP LO`（温度过低）；
  - `OVP`（过压）；
  - `UVP`（欠压）；
- 当多种告警同时存在时，只显示优先级最高的一项，例如：
  - `DSG HI > CHG HI > TEMP LO > OVP > UVP`；
- 告警着色：
  - 预警（接近阈值）→ `YELLOW`；
  - 严重故障（已触发保护或降额）→ `RED`；
  - 无告警 → 显示 `--`，颜色 `GRAY`。

示例像素稿（放大 4× 展示）：

Battery detail – voltage frame
Battery detail – temperature frame

## 均衡显示策略

- 仅使用颜色高亮表示均衡，无闪烁：
  - 电压帧：`balancing_index` 命中电芯的电压数值颜色为 `YELLOW`，其他正常电芯保持 `ORANGE`；
  - 温度帧：所有有效温度始终使用 `WHITE`，即使处于均衡中也不改变颜色；
  - 缺失数据仍使用 `GRAY` 显示占位符 `--`。
- 这样一来，电芯区完全静态，无 on/off 闪烁；眼睛只需在电压帧中捕捉黄色数字即可判断当前均衡节。

## 交互与状态机

- 屏幕状态：`Dashboard ↔ BattDetail`：
  - `Down`：Dashboard → BattDetail；
  - `Up`：BattDetail → Dashboard；
  - 其他按键行为与仪表盘一致，由上层按键状态机决定。
- BattDetail 内部状态：
  - `cells_frame: Voltage | Temp`，按 2 秒节奏轮播；
  - `balancing_index` 与 `cells_mv`、`cells_temp_c` 一起随 UI 刷新更新。

## 渲染接口（建议目标）

UI 与上层逻辑之间建议以以下数据结构交互（与实际实现的小差异可在代码侧适配）：

- `CellsFrame`（仅在 UI 内部使用，可选是否对外暴露）：

```rust
enum CellsFrame {
    Voltage,
    Temp,
}
```

- `BattDetailData`：

```rust
pub struct BattDetailData {
    pub mode: Mode,
    pub pack_v_mv: Option<u32>,
    /// Pack current magnitude in mA (direction由 `mode` 推断)。
    pub pack_i_ma: Option<u32>,
    /// 1 基电芯 1–5 的电压（mV）。
    pub cells_mv: [Option<u16>; 5],
    /// 1 基电芯 1–5 的表面温度（℃，由 4 NTC 推算）。
    pub cells_temp_c: [Option<i16>; 5],
    /// 当前被均衡电芯编号（1–5），无均衡时为 None。
    pub balancing_index: Option<u8>,
    /// TEMP_STATUS 解码结果，用于行 4 告警文案。
    pub temp_fault: Option<TempFaultFlags>,
}
```

渲染入口保持单帧纯函数风格：

```rust
fn render_batt_detail_once<SPI, CS, DC>(
    spi: &mut SPI,
    cs: &mut CS,
    dc: &mut DC,
    model: &BattDetailData,
) -> Result<(), SPI::Error>
where
    SPI: SpiBus<u8>,
    CS: OutputPin,
    DC: OutputPin,
{ /* ... */ }
```

其中：

- `CellsFrame` 的电压/温度轮播由 UI 任务内部状态机控制；`BattDetailData` 不负责存储该状态；
- 告警代码可由 `temp_fault` 与其他 pack 状态位共同推导，在渲染函数中本地格式化为短字符串。

## 容错、性能与验收要点

- 容错：
  - 任意电压/温度缺失时显示 `--` 且使用 `GRAY`；
  - `balancing_index` 为无效值或超出 1–5 时，UI 视为无均衡（不高亮）；
  - 告警行在数据完全缺失或异常时显示 `WARN --`。
- 性能：
  - 保持全屏重绘 ≤ 10 fps；优先采用按行脏矩形刷新；
  - 不新增字形，复用现有 7×10 点阵与颜色常量。
- 验收：
  - 任意合法输入下，四行文本均在 `≤160×50` 范围内，无截断或重叠；
  - 电压帧与温度帧在同一电芯位置的起始列完全一致，轮播时画面不“抖”；
  - 均衡电芯以稳定的 `YELLOW` 强调，无闪烁；
  - 告警行在存在高温/欠温/过压/欠压之一时能够给出清晰、唯一的短码提示。

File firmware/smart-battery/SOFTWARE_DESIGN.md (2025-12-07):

# Smart Battery Software Design (LED/State Machine/Low Power)

This document is the single source of truth for the smart‑battery firmware design, consolidating charger control inversion (CE/PSTOP), 4‑LED signaling, dropout handling, sampling cadence, event‑driven global state machine, and the low‑power Sleep mode. It supersedes earlier LED drafts and scattered notes.

## 1) Pin Map (from `smart-battery.ioc`)

- Charger control
  - `PA10` = `CE_CTL` (GPIO Output)
  - `PA9`  = `PSTOP_CTL` (GPIO Output)
- Alert/INT lines
  - `PB1`  = `ALERT` (EXTI1)
  - `PB2`  = `INNER_INT` (EXTI2)
- I²C
  - I2C2 (INNER): `PB10=SCL`, `PB11=SDA` (BQ76920 @0x08, SC8815 @0x11, TMP75A @0x48)
  - I2C1 (OUTER, slave): `PB6=SCL`, `PB7=SDA`, `PB5=SMBA`
- LED (4 pcs, 1→4 = Red, Yellow, Green, Blue) — all as plain GPIO outputs (no timers)
  - LED1 (Red)   → `PA5`  (`LEDK1`, GPIO Out)  ← change `.ioc` from `S_TIM2_CH1` to `GPIO Output`
  - LED2 (Yellow)→ `PA6`  (`LEDK2`, GPIO Out)
  - LED3 (Green) → `PA7`  (`LEDK3`, GPIO Out)
  - LED4 (Blue)  → `PB0`  (`LEDK4`, GPIO Out)

## 2) SC8815 CE/PSTOP Control Inversion

- Hardware: MCU drives SC8815 `CE` and `PSTOP` through N‑MOSFET isolation; the MCU pin level is inverted relative to the IC’s active level.
- Unified control semantics on the MCU side:
  - `CE_CTL` (MCU pin): High → chip `/CE` Low (enable charger); Low → chip `/CE` High (disable charger).
  - `PSTOP_MCU` (MCU pin on `PA9`, labelled `PSTOP_CTL` in CubeMX): High = MCU 允许功率级；Low = MCU 主动停机请求。
- SC8815 pin-level semantics (non-inverted, for absolute clarity):
  - `PSTOP = High` → power stage stopped.
  - `PSTOP = Low`  → power stage allowed.
- Hardware protection docs以及当前网表会区分 `PSTOP_MCU`（MCU GPIO）和 `PSTOP_CTL`（经 U22 逻辑后的网）：
  - `PSTOP_CTL = TEMP_FAULT_N · PSTOP_MCU`（U22 = SN74AUP1G08DCKR）。
  - 板载 Q10（BSS138PS）+ RN1 组成反相/电平转换：`PSTOP = !PSTOP_CTL`。
  - 固件只能驱动 `PSTOP_MCU`（PA9）；只要 `TEMP_FAULT_N = 0` 或 `PSTOP_MCU = 0`，最终芯片脚 `PSTOP = High` 强制停机。
- Truth table (MCU / TEMP_FAULT_N → chip pins):

  | TEMP_FAULT_N | PSTOP_MCU | CE_CTL | Derived nets (`PSTOP_CTL`, `PSTOP`) | Chip pins (`/CE`, `PSTOP`) |
  |--------------|-----------|--------|-------------------------------------|----------------------------|
  | 1 (正常)     | 1         | 1      | `PSTOP_CTL` = 1, `PSTOP` = Low      | `/CE` = Low, PSTOP = Low   |
  | 1 (正常)     | 0         | 1      | `PSTOP_CTL` = 0, `PSTOP` = High     | `/CE` = Low, PSTOP = High  |
  | 0 (过温)     | 1         | 1      | `PSTOP_CTL` = 0, `PSTOP` = High     | `/CE` = Low, PSTOP = High  |
  | 0 (过温)     | 0         | 1      | `PSTOP_CTL` = 0, `PSTOP` = High     | `/CE` = Low, PSTOP = High  |

- Safety rule: any stop/pause/fault/dropout path在固件层都必须落到 `PSTOP_MCU = 0`（从而 `PSTOP_CTL = 0`, 芯片 `PSTOP = High`）。

## 3) 4‑LED Signaling Rules (3 s base cycle)

- Cycle: Unless stated otherwise, each LED uses a 3‑second indication cycle.
- Base/Background: When there are no pulses, the LED shows its base on/off. Pulses at the start of each cycle convey details.
- Pulse definition: width 120 ms, gap 120 ms; pulses are “inverted flash” relative to the base.
- Severity: Higher severity → more pulses (except explicitly defined 1‑pulse cases).
- Per‑LED priority (within a single LED, high→low):
  1) 1 Hz dropout blink (500 ms on / 500 ms off) — overrides everything on that LED.
  2) Fault 50% blink + pulse code.
  3) Base on/off + pulse code.
  4) Asynchronous one‑shot pulse (only Green for I2C1 traffic).

Notes: LED tasks do not synchronize phases across colors; each keeps its own 3 s epoch.

### 3.1 Green (Communication + Low Power)

- Base: normal run = ON; Sleep = OFF.
- Async pulse: whenever I2C1 (slave) is accessed, emit 1 immediate pulse (does not wait for the 3 s boundary).
- During Sleep: keep the same 3 s rhythm policy (no slow period change), i.e., still eligible for base/pulse behavior; however base is OFF in Sleep per spec.

### 3.2 Yellow (SC8815 Charging/Fault)

- Dropout: if SC8815达到连续 I²C 失败阈值，则进入 1 Hz 掉线闪烁（覆盖黄灯上其他显示），不受“是否使用过”之类前置条件限制。
- Base: not charging = OFF; charging = ON.
- Fault blink: strictly 50% over the 3‑second cycle: 1.5 s ON + 1.5 s OFF.
- Pulse codes (applied at cycle start):
  - 1 pulse: Charging conditions met but AC absent (still “not charging”, thus 1 pulse every 3 s).
  - 2 pulses: VBUS OVP / adapter abnormal.
  - 3 pulses: BAT OVP / end‑of‑charge abnormal.
  - 4 pulses: OTP / NTC abnormal temperature.
  - 5 pulses: IBUS/charge over‑current/short‑related protection.

### 3.3 Red (BQ76920 FET/Protection/Balancing)

- Dropout: if BQ76920 hits the consecutive I²C failure threshold it enters a 1 Hz dropout blink (overrides others on Red). This includes communication hangs which are converted to failures by the timeout policy below.
- Base: both CHG & DSG FETs ON → OFF; any side disabled → ON.
- Pulse codes (at cycle start):
  - 1 pulse: Balancing active.
  - 2 pulses: UV/OV protection latched (FETs disabled).
  - 3 pulses: SCD (short‑circuit discharge).
  - 4 pulses: OCD (over‑current discharge).
  - 5 pulses: AFE internal temp/reference abnormal or other major unclassified fault.
  - 6 pulses: Battery temperature out of band (temp pause by BQ76920).

### 3.5 Dropout Semantics, Timeouts and Online Flags

- Both BQ and SC paths maintain “online” flags that reflect recent successful communications. LED dropout blinking is driven by these flags.
- To avoid silent hangs (e.g., I²C awaits that never resolve), the firmware wraps critical reads with a timeout and classifies timeouts as failures:
  - BQ measurement read: 2 s timeout. On success, online=true and a heartbeat timestamp is updated; on error/timeout, `fail_streak += 1`.
  - SC device status read: 2 s timeout. On success, online=true and a heartbeat timestamp is updated; on error/timeout, `fail_streak += 1`.
- 当 `fail_streak >= 3` 时，将对应 online 标志设为 false，从而强制进入掉线闪烁（红灯=BQ，黄灯=SC）。SC 掉线闪烁不再受任何“使用过”之类门槛限制。
- Successful subsequent reads immediately reset `fail_streak` and restore the online flag.

### 3.4 Blue (Global State)

- Constraint: Blue must never be pulse‑less; if no pulse applies, Blue shows OFF.
- Sleep: keep the standard 3 s cycle (no slow cycle during development phase).
- Suggested codebook (can be aligned to HW naming later):
  - 1 pulse: Idle / Standby.
  - 2 pulses: Charging Active.
  - 3 pulses: Charging Paused (session kept, power stage stopped).
  - 4 pulses: Balancing.
  - 5 pulses: Charge Done.
  - 6 pulses: Global Fault.
  - 7 pulses: Safe Shutdown / Shipping.

## 4) Arbitration & Timing Composition

- Per‑LED priority: Dropout 1 Hz > Fault 50% (1.5 s/1.5 s) + pulses > Base + pulses.
  - Green’s I2C pulse is asynchronous and can briefly override for ~30–240 ms without changing the 3 s phase.
  - Driver layer composes modes; semantic layer only decides “base + pulses / 50% blink / 1 Hz blink”.

## 5) Sampling Cadence, Balancing, Pause‑Charge

- Outside balancing: do not sample cell metrics every second anymore.
- During charging: sample cell voltages every 30 s to decide entering balancing and whether to pause charging.
- During balancing: allow ~1 s cadence to control balancing switches and termination.
- Pause‑charge semantics: keep the charging session/regs, but set `PSTOP_CTL = Low` (chip `PSTOP = High`) to stop the power stage. Resume based on state‑machine policy (temp, delta‑V, EOC, timers, etc.).

### 5.1 Imbalance recovery (low‑V, high ΔV)

- 触发条件：`ΔV>=150 mV` 或 `ΔV_pct>5%`，且 `Vpack<16.2 V`，`Vmin>=2.70 V`；硬停条件保持不变（`Vmin<2.50 V`、过温、通信掉线）。
- 固定循环（总长 150 s）：
  - 充电段 30 s：`IBAT=300 mA`（ratio=6x, RS=10 mΩ）、`Vfloat=17.9 V`，允许平衡；目的是抬升最低单体。
  - 停充均衡段 120 s：`PSTOP_CTL=Low` 停功率级，CE 保持高，被动均衡持续；时间占比 80% 让均衡电流主导，压差得以收敛。
- 退出与降级：
  - 连续 3 个循环（≈7.5 min）`ΔV` 总降 <15 mV 或 `Vmin` 总升 <60 mV → 停充并告警“不收敛”。
  - 达成 `ΔV<60 mV` 或 `ΔV_pct<1.5%` 且 `Vmin>3.0 V` → 退出恢复循环，恢复正常充电/速度表设置。
- 高压夹层：若 `Vmax>3.55 V` 且 `ΔV>80 mV`，先执行一次 120 s 停充均衡窗口再继续按当前状态；BQ OV 仍兜底。
- 简化实现：仅调用 `set_ibat_limit(300 mA)` 与 `set_vfloat(17.9 V)`，不触碰 IBUS 或 `ChargeSpeedSetting`；PSTOP 定时切换实现占空；记录循环号、`ΔV/ΔV_pct/Vmin/Vmax` 以便调参。

## 6) Dropouts & Safety

- Accept dropouts: SC8815/BQ76920 I²C failures and absent I2C1 host.
- Threshold: 3 consecutive I²C transaction failures for a device → dropout.
- Mandatory action: if BQ76920 hits the threshold, ensure `PSTOP_CTL = Low` (chip `PSTOP = High`, power stage stopped).
- Indication: corresponding LED enters 1 Hz blink; state machine falls back to a conservative branch.

## 7) Event‑Driven Global State Machine

- Event sources
  - BQ76920: OV/UV/OCD/SCD/temperature protection interrupts, balancing status, FET states.
  - SC8815: EOC, VBUS/BAT OVP, OTP, over‑current/short, adapter plug/unplug.
  - I2C1 (slave): host accesses (wake + Green pulse only; not a safety event).
- States (mapped to Blue codes): Idle → Charging Active → Charging Paused → Balancing → Charge Done → Idle. Can enter Global Fault or Safe Shutdown anytime. Sleep overlays as an energy mode.
- Transitions (examples)
  - Adapter present + conditions OK → Charging Active.
  - Large cell delta‑V → Balancing; pause‑charge if needed (stop power stage).
  - SC8815 EOC or BQ OVP → end/pause charging and update state.
  - BQ/SC dropout → stop power stage and enter dropout indication + conservative branch.

## 8) Low‑Power Mode (Sleep)

- Implement Sleep (not STOP) for now. Keep I2C1 Sleep‑clock gate (`APB1SMENR.I2C1SMEN=1`).
- Wake on I2C1 events/errors; process transaction; fall back to Sleep after idle timeout.
- LED policy in Sleep: Green base OFF, async pulse on traffic; Yellow/Red/Blue keep the standard 3‑second cycle.

## 9) Implementation Notes

- Provide a semantic API for charger control (e.g., `enable_power_stage(bool)`, `pause_power_stage()`) to hide inverted GPIO levels.
- Separate semantic vs. driver layers for LED logic; add a common helper to arbitrate dropout/fault/base across all LEDs.
- Align Yellow/Red fault codebooks with SC8815/BQ76920 register names and priorities when integrating the drivers.
- LEDs are plain GPIO outputs; implement all flashes/pulses in software (no TIM/PWM dependency). Ensure `PA5` (`LEDK1`) is configured as GPIO Output in the `.ioc`.

## 10) Document Status

This document replaces prior LED drafts and the earlier bring‑up write‑up as the authoritative design. Legacy files remain only as historical context and should link here for current behavior.

> 中文要点（外设通信/I2C 对外协议）
>
> - 对外通信总线：I2C1 从机，地址 0x35（7‑bit），引脚 PB6=SCL、PB7=SDA（见 smart-battery.ioc），SMBA 暂不实现。
> - 速率：兼容 100 kHz 与 400 kHz；允许短暂 SCL 拉伸（≤150 µs）。
> - CRC/PEC：遵循 TI/SMBus 习惯。
>   - 写操作：主机每写 1 个数据字节，紧跟 1 个 CRC8（poly 0x07，初值 0x00），校验 [ADDR_W, REG, DATA]，CRC 错误在 CRC 字节处 NACK，整帧丢弃。
>   - 读操作：设备按 [DATA, CRC] 交错返回；首字节 CRC 计算 [ADDR_R, DATA0]，后续仅对各自 DATAi 计算。
> - 寄存器：1 字节地址，自增；多字节 LE；提供电压/电流/温度/故障与充电软控制（详见下文 Register Map）。
> - 选择 I2C1 的原因：支持 STOP 唤醒，满足低功耗场景对外主机唤醒的需求。

## Scope

This document captures the software architecture that now boots the STM32L051C8
smart-battery firmware into a safe operating state. The firmware sequence
initializes the TI **BQ76920** protection IC (CRC variant @ 0x08) ahead of the
**SC8815** charger so that the pack’s safety envelope is validated before any
power stage is enabled. It also describes the shared I2C bus topology, gating
controls, and telemetry loops that underpin bring-up.

## Hardware Interfaces

- **I2C2 – INNER bus (PB10/PB11)**: Operated at 100 kHz with DMA1_CH4/CH5 and
  serviced through the shared I2C2 interrupts. A global `StaticCell` stores the
  bus so multiple async drivers can borrow it via `embassy-embedded-hal`
  shared-bus mutexes. The BQ76920 (fixed `0x08`), SC8815 (`0x11`) and TMP75A
  (`0x48`) all ride this bus.
- **I2C1 – OUTER bus (external host interface)**: Configured as 7‑bit I²C slave
  to allow a system host (MCU/SoC) to query pack telemetry and command limited
  charging control. I²C1 is used because it supports wake‑from‑STOP on address
  match (WUPEN), enabling ultra‑low‑power idle while remaining responsive.
  Pins per `.ioc`: PB6 = I2C1_SCL, PB7 = I2C1_SDA, PB5 = I2C1_SMBA (alert).
  The slave address is `0x35` (7‑bit). Supported bus rates: 100 kHz and 400 kHz.
  Clock stretching is permitted (≤ 150 µs) while copying a fresh telemetry
  snapshot into the I²C TX buffer. General‑call is disabled.
- **SMBus Alert (PB5) & Alert GPIOs**: PB5/I2C1_SMBA is used for pack
  temperature alerts. When `TEMP_STATUS.TEMP_HIGH_CHG` 或
  `TEMP_STATUS.TEMP_HIGH_DSG` 置位时，固件通过 PB5 拉低向主机发出过温通知；
  当这两位清零（仅可能在温度恢复到安全窗口后）时，PB5 释放为高电平。  
  其他告警线：`PB1`（BQ alert）和 `PB2`（inner bus INT）仍用于 EXTI 唤醒。
- **CE (PA10)**: Active-low charger enable. Held high during safety bring-up
  and whenever no SC8815 activity is required. The firmware asserts it low only
  when the charger must be configured, telemetry must be sampled from the
  SC8815, or charging is actively commanded.
- **PSTOP_MCU (PA9, firmware label `PSTOP_CTL`)**: MCU-side “stop request” for the SC8815 power stage. When `PSTOP_MCU = 1` and `TEMP_FAULT_N = 1`, hardware derives `PSTOP_CTL = 1` and, after board inversion, chip `PSTOP = Low` (power allowed). If either `PSTOP_MCU = 0` or `TEMP_FAULT_N = 0`, then `PSTOP_CTL = 0` and chip `PSTOP = High` (forced stop).
  until charger programming succeeds and stays an emergency kill path for any
  detected charger fault.
- **EXIT_SHIPMODE (PH0)**: Push-pull GPIO (MCU pin PH0, net `$1N118667`) routed
  via D3 clamp onto the BQ76920 `TS1` pin. Used to wake the BQ76920 from ship
  mode with a high pulse before configuration retries. Note: the legacy
  `smart-battery.ioc` file still labels `PA1` as EXIT_SHIPMODE; the PCB netlist
  (`docs/battery-pcb/netlist_battery.enet`) is the authoritative mapping.

## Initialization Sequence

1. Configure MCU clocks (LSE on) and instantiate CE/PSTOP outputs high to keep
   the charger path disabled. Prepare the `PH0` wake GPIO (EXIT_SHIPMODE → TS1)
   so the BQ76920 can be nudged out of ship mode if it fails to respond on the
   first attempt.
2. Bring up I2C2 with DMA and register it inside a `StaticCell<Mutex<…>>`. This
   shared handle feeds lightweight `I2cDevice` wrappers for each peripheral at
   the moment they need bus access.
3. Initialize the global pub/sub channels; capture the BQ-specific publishers so
   alerts and measurement frames can be streamed once the protection loop runs.
4. Enter a blocking loop that repeatedly attempts to configure the BQ76920 via
   `Bq769x0` with CRC enabled:
   - First boot attempt performs an immediate configuration using per-cell
     thresholds (OV 3.65 V, UV 2.50 V), 15 A short-circuit, 10 A discharge
     overcurrent, and `rsense = 3 mΩ` to match the hardware shunt.
   - If this initial communication fails, pulse `EXIT_SHIPMODE` high, hold the
     line asserted for a full 500 ms to exit ship mode, then drop it low before
     retrying configuration.
   - Subsequent failures fall back to a 1 s retry cadence without repeating the
     ship-mode pulse. MOSFETs and the charger stay disabled until configuration
     succeeds.
   - On success, spawn the asynchronous `bq76920_task`, which keeps verifying the
     pack, manages FET states, and publishes telemetry.

## 11) Temperature Sensing (Legacy SC8815 ADIN) & Protection Policy

Note: on current production boards the NTC/ADIN network is **not populated** and
the firmware build sets `DISABLE_ADIN_TEMP = true` to bypass all ADIN‑based
gating. This section documents the original NTC/ADIN‑based policy and remains
as a reference for potential future board spins that re‑enable ADIN. For the
active temperature sensor and over‑temperature window on current hardware, see
section 12 (TMP75AIDGKR).

Goal (legacy design): provide a temperature‑based power‑stage protection using
the SC8815 ADC input `ADIN` and the on‑board NTC network shown in the schematic
(R23=43 kΩ to `VCC_SC`, NTC=10 kΩ 3380 K to GND, C32=100 nF to GND at the
divider mid‑node → `ADIN`).

Design facts and constraints (updated)

- SC8815 exposes a 10‑bit ADC channel on `ADIN` with 2 mV/LSB and a full‑scale
  of 2.048 V. The result is split as MSB 8‑bit and LSB 2‑bit registers. There is
  no readable internal die‑temperature register; only an OTP (over‑temperature
  protection) fault bit exists in STATUS. We therefore derive temperature solely
  from the external NTC divider.
- Board mapping used by this firmware:
  - Run mode (power stage enabled): use 5.0 V codes for ADIN policy (board-level VCC_SC≈5 V while power stage runs).
  - Stop mode (power stage stopped): evaluate with 3.0 V codes, but only after a
    fixed 10‑second settle window to allow VCC_SC to drop.
- Required behavior (aligned with current test plan)
  - Over‑temperature stop at 50 °C (Yellow 4‑pulse on detection).
  - Cool‑down resume at 40 °C (hot path only).
  - Low‑temperature inhibit below 0 °C; after the 10‑second settle window,
    resume once temperature is ≥ 0 °C (no extra time hysteresis, the 10 s window
    is the only timing hysteresis).
  - While power stage is running, target ≈1 °C effective accuracy. While
    stopped, accuracy is not critical; we only need a reliable resume threshold.

NTC model and conversion

- Parts: R23 = 43 kΩ (±?), NTC = 10 kΩ @ 25 °C, β = 3380 K
  (`FNTC0402X103F3380FB`).
- Divider equation: `V_adin = Vcc * R_ntc / (R23 + R_ntc)`.
- Recover `R_ntc` from a measurement: `R_ntc = R23 * V_adin / (Vcc - V_adin)`.
- Convert to temperature (Kelvin) with the β model: `T = 1 / (1/T25 + (1/β)
  * ln(R_ntc/R25))`; `T25 = 298.15 K`, `R25 = 10 kΩ`. Celsius = `T − 273.15`.
- ADC code to voltage: with the SC8815 formula, `V_adin ≈ (code + 1) * 2 mV`
  where `code ∈ [0..1023]` is formed by `(MSB<<2)|LSB`.

Reference thresholds (β=3380 K, R23=43 kΩ, NTC=10 kΩ)

- Run 5.0 V: 50 °C → code ≈ 220.
- Stop 3.0 V: 40 °C → code ≈ 178；0 °C → code ≈ 593。

Operational policy

- Sampling
  - Enable SC8815 ADC (`AD_START=1`) whenever charger telemetry is needed.
  - While running, compare against 5.0 V codes (no full temperature solve).
  - After stopping, wait a 10‑second settle window, then compare against 3.0 V
    codes for resume/cold policy.
- Decisions (hysteresis and low‑temp behavior)
  - Over‑temp stop (Run/5V): `ADIN_code ≤ 220`（默认去抖 2 次，±2 码裕量）→ 立即停功率级并打 Yellow 4 脉冲。
- Settle window: 停机后先等待 10 s，让 VCC_SC 下沉到 3 V；窗口内不执行 3 V 判定。
  - 窗口触发条件：仅在运行→停机边沿或运行态 HOT 触发后开始计时；上电不触发窗口。窗口不叠加、不续期。
  - Cool‑down resume (Stop/3V)：窗口结束后，`ADIN_code ≥ 178`（去抖 2 次）才恢复。
  - Low‑temp inhibit (Stop/3V)：`ADIN_code ≥ 593` 进入低温保护；窗口结束后，一旦 `ADIN_code < 593` 立即恢复（无额外时间迟滞）。
- Margins & filtering
  - Apply a ±5‑code margin to the fixed thresholds to absorb ADC quantization,
    resistor/β tolerance and noise (C32=100 nF provides analog filtering).
  - Debounce by requiring any threshold condition for ≥100 ms or 3 consecutive
    samples, whichever is longer.

Driver/API hooks (to be implemented in code after approval)

- `sc8815::SC8815::set_adc_conversion(true)` to start conversions.
- `read_adin_raw()` → `(msb, lsb)`; helper `adin_code_10bit(msb, lsb)`.
- `temp_c_from_adin(code, vcc_mv)` implementing the divider inversion and β
  solve for run‑mode (vcc=3000 mV).
- `should_stop_from_hot(code_3v)` and `should_resume_from_cool(code_5v)` to
  evaluate thresholds with margins and debounce.

- LED linkage

- Yellow 4‑pulse on ADIN over‑temperature detection（独立于是否已执行停机）；OTP 仍然 4 脉冲；掉线 1 Hz 优先级最高。

Testing notes

- Bench can validate by heating the NTC with hot air and observing code
  crossings near the listed references. Because β and resistor tolerances vary,
  plan for a single‑point calibration offset in software when hardware data is
  available; the algorithm supports an additive temperature offset applied in
  run‑mode only.
5. Once the protection stage is alive, wait 10 ms, drive CE low, and delay
   another 100 ms to satisfy the SC8815 wake timing.
6. Reassert `PSTOP` high immediately before configuring the SC8815. Create an
   `I2cDevice` for SC8815 over the same mutex-protected bus, call `init()`, push
   the charger configuration (10 mΩ sensing, 800 mA limits, Charging mode,
   450 kHz switching, 60 ns dead time, VINREG 11.5 V, VBAT ratio forced, with
   trickle/termination enabled), disable OTG, and start ADC conversions. Any
   error forces CE/PSTOP high and exits early.
7. Hold PSTOP high for an additional 100 ms, then drive it low to energize the
   power stage. Runtime monitoring continues to guard against faults.

## Runtime Behaviour

- **Protection loop**: The spawned `bq76920_task` reuses the shared bus to fetch
  measurements, confirm register integrity, and assert FET control. Configuration
  verification failures keep both FETs disabled and log detailed diagnostics. The
  task acquires a fresh measurement frame once per second and republishes pack
  voltage, pack current, per-cell voltages, temperatures, MOS status, and alert
  bits via the `BQ76920_MEASUREMENTS` pub/sub queue so downstream tasks (such as
  the charger controller and USB bridge) always have up-to-date data.
- **Pack-voltage supervision**: When the BQ76920 reports healthy status, the
  firmware holds the discharge FET enabled whenever protection flags are clear so
  the SC8815 VBAT sense always tracks the pack. Only undervoltage, short, or
  overcurrent faults—and the 12.5 V cutoff—force the discharge FET open. If
  charging is permitted by the BQ76920, the firmware consults the reported pack
  voltage to decide SC8815 gating: below 17.0 V, drive the CE/PSTOP sequence to
  begin charging; at 18.5 V, halt charging even if other conditions remain true;
  at 12.5 V or lower, immediately disable output FETs and charger gates to
  prevent deep discharge. A
  hardware erratum leaves
  the ALERT pin permanently asserted, so software now forces the charge FET on
  whenever voltage and protection limits are satisfied, even if the
  `OVRD_ALERT` flag latches back in. The alert bit is still logged, but it no
  longer vetoes the charge path.
- **Charger loop**: The SC8815 owner task wakes every second, consumes the most
  recent BQ76920 measurement frame,并按以下规范管理“会话创建/功率级放行/暂停”：
  - 会话创建（仅两条，必须同时满足）：
    1) `Vpack < 17.0 V`；2) BQ76920 无故障（OV/UV/OCD/SCD 均为假）。”spread“不是故障，不参与会话创建判定。
  - 功率级放行（PSTOP 低）与暂停（PSTOP 高）：
    - 正常充电：无暂停条件时，放行功率级（PSTOP 低）。
    - 过压（OV，电池故障）：立即暂停，仅拉高 PSTOP，保持会话不结束；进入 180 s 冷却计时，计时结束且仍满足“会话创建两条”时再放行。

    - 严重不均衡（Δcell ≥ 100 mV，非故障）：立即暂停，仅拉高 PSTOP，保持会话不结束；当 `Δcell < 50 mV` 立刻解除暂停并放行（无时间迟滞）。
    - 其它电池或充电故障（如 UV/OCD/SCD、OTP、VBUS/VBAT 短路等）：立即暂停并结束会话（CE/PSTOP 置高），待故障消除后按会话创建规则重来。
  - 进入充电时序：会话创建成功后，先断开功率级（PSTOP 高）、拉低 CE、延时 100 ms、再释放 PSTOP 以放行功率级。

  Charging is considered active when the SC8815 is enabled and battery charge
  current `IBAT` exceeds 100 mA for three consecutive samples; it is considered
  inactive after three consecutive samples ≤ 80 mA. These thresholds are used
  solely for control and indication logic and do not introduce additional UI
  states.
- **Telemetry plumbing**: Measurement publishers returned by `shared::init_pubsubs`
  keep per-device channels decoupled. The BQ76920 producer updates its queue at
  1 Hz, the SC8815 task pushes charger telemetry on the same cadence, and any
  consumer (USB bridge, logging task, etc.) can subscribe to combine them into an
  `AllMeasurements` snapshot without every task polling individual peripherals.
**Balancing and Charging Coupling (Normative)**

- Evaluation cadence: Balancing SHALL be evaluated once per second (1 Hz).
- Charging/Paused gating: Balancing MAY run only while the system is either
  charging (`expected_charging || charging_confirmed`) or in a charging pause
  (OV cooldown or severe-imbalance pause).
- Start condition: Pack cell spread (max − min) ≥ 10 mV.
- Single-cell only: At any time, at most one cell may be actively balanced. When changing the target cell, firmware shall first disable all balancing FETs, wait a deadtime ≥ 40 ms, then enable the new cell.
- Selection rule: Choose one globally highest-voltage cell that exceeds at least one immediate neighbor by > 1 mV (for end cells, compare the single neighbor; for middle cells, either left or right neighbor suffices).
- Stop condition: Stop balancing when all adjacent cell-to-cell differences are ≤ 1 mV across the pack.
- Charger coupling: While balancing is required or active, the charger SHOULD maintain CV (as
  implemented by the charger task’s policy).
- Adapter loss: If the adapter is lost and the system is not in a charging-pause context, balancing
  shall stop but continue to be evaluated at 1 Hz; if the system is in a charging-pause context
  (OV cooldown or severe-imbalance pause), balancing MAY continue.

**LED Status – Single LED (Normative)**

Only one monochrome LED is available. Patterns below are mandatory and mutually prioritized.

- Priority order (high → low): Fault > Charging (with balancing overlay) > Full (with hysteresis) > Idle.
- Fault (only when a real chip fault bit is set):
  - Battery faults: BQ76920 OV/UV/OCD/SCD = true.
  - Charger faults: SC8815 OTP or VBUS/VBAT short = true.
  - Pattern: 4 Hz flashing (125 ms on / 125 ms off).
- Charging baseline: 1 Hz flashing (500/500).
- Overlay (drawn only during the Charging on-window, and only to indicate “hardware balancing is running”):
  - If and only if bal_cell≠0, insert two 40 ms off notches at 100–140 ms and 300–340 ms.
  - Severe imbalance (Δ≥100 mV, non-fault; including paused state) does not add any overlay; it remains at the Charging baseline unless a chip fault makes it Fault.
- Full (with hysteresis): solid on. If the adapter is present during maintenance/float, briefly turn off for 40 ms every 8 s.
- Idle/Standby: off.

Full detection (parameters):

- Enter full when `VBAT ≥ PACK_CHARGE_STOP_THRESHOLD_MV` and `IBAT ≤ I_term` continuously for 45–90 s.
- Exit full when `VBAT` leaves the float band, or `IBAT ≥ 1.2 × I_term` continuously for ≥ 10 s, or any fault occurs.
- Debounce: 800 ms on all state edges.

## Future Enhancements

- Integrate SC8815 telemetry into the pub/sub fabric so higher-level logic can
  arbitrate charging without relying on logs.
- Implement SMBus alert servicing on PB1/PB5 to react more quickly to protection
  trips rather than polling.
- Add explicit recovery routines (e.g., staggered retries or manual clear hooks)
  once the protection IC reports a cleared fault, keeping the safety-first
  posture that now gates charger bring-up.

---

## Temperature Sensing & Protection (BQ76920 Internal Sensor)

Goal: 使用 BQ76920 内部温度作为统一温度保护中的一个输入通道；在 BQ 激活/非激活两种采样节拍下分别进行平滑/抗毛刺；再将平滑后的 `T_BAL` 纳入系统级温度决策（详见“Multi‑Sensor Pack Temperature Architecture”节）。

- 传感器来源：BQ76920 内部温度（TEMP_SEL=Internal），驱动返回 `temperatures.ts1`，单位 0.01°C。
- 采样/滤波与节拍：
  - 节拍：当“实际均衡活跃（硬件位/active_cell）”或“处于充电相位（含暂停态）”时使用 1 s；其他情况下按 30 s / 60 s（充电相位=30 s，非充电=60 s）。仅“需要均衡（Δcell≥阈值）”但未处于充电相位时不再使用 1 s，避免 AC 不在时的高频打点。
  - 激活态（采样周期 < 60s）：EMA 平滑，α=0.20（整数域）。
  - 非激活态（≥60s）：快速连续三次求中位数；该中位数也用于重置 EMA。
  - 启动快速首样：初始化完成后强制一次“立即采样”，便于尽快暴露故障与温度异常。
- 日志：每次决策打印一行 `bq:t= <used> (ema|med3) raw=<raw> (0.01C)`。
- 保护与动作（与统一策略对齐）：
  - BQ 任务不再单独维护一套独立的 50/60/70 °C 阈值，而是：
    - 将滤波后的内部温度作为 `T_BAL` 提交给统一温度策略；
    - 在统一策略判定需要禁止充电/放电或切断输入输出时，按系统级决策执行 CHG/DSG FET 控制。
  - 在 NTC/TMP75/MCU 传感器异常或缺失时，允许将 `T_BAL` 作为兜底的温度来源参与系统级比较（即 `T_MAX/T_MIN` 计算仍然有效）。
- 灯语：本次改动不直接影响黄灯；黄灯仍由 SC8815 自身告警/会话状态决定。红灯会因 FET 组合状态变化（非两侧同时 ON）表现为更高脉冲码；蓝灯是否显示“暂停”仍取决于现有 CHG_PAUSED 标志（由 SC 侧暂停行为产生）。

Notes:
- Temperature based CHG/DSG FET control is executed by the BQ task for fastest reaction and does not depend on charger session state.
- SC8815 charging logic remains authoritative for session creation/termination; CHG FET gating at BQ level prevents current flow during temperature pauses.

## Control-Flow Diagrams

Policy note: Balancing now strictly requires AC presence. When the adapter is absent, any active balancing is immediately cleared, and CV-hold requests are withdrawn.

### Tasks, PubSub, and Data Flow

```mermaid
flowchart LR
  MAIN[main]
  BQ[bq76920_task]
  SC[sc8815_task]
  GS[global_state_task]
  LED[led_status_task]

  SCA[Sc8815Alerts]
  SCM[Sc8815Measurements]
  BQA[Bq76920Alerts]
  BQM[Bq76920Measurements]
  BAL[BalancingCvRequest]
  GSTATE[BatteryGlobalState]

  MAIN --> BQ
  MAIN --> SC
  MAIN --> GS
  MAIN --> LED

  SC --> SCA
  SC --> SCM
  BQ --> BQA
  BQ --> BQM
  BQ --> BAL
  GS --> GSTATE

  GS --- SCA
  GS --- SCM
  GS --- BQA
  GS --- BAL
  LED --- GSTATE
  BQ --- SCA
  SC --- BQM
```

---

## External Communications (I2C1 Slave)

This section specifies the on‑board I²C1 slave protocol used by the pack to
communicate with an external host. Summary (Chinese): 智能电池通过 I2C 从机模式与外部通信；
我们使用 I2C1 对外通信，因为其支持从 STOP 状态唤醒；本文定义查询电压/电流/温度/故障及读写充电状态的一组命令与寄存器。

### Link & Electrical

- Address: 7‑bit `0x35` (write: 0x6A, read: 0x6B).
- Modes: Standard‑mode (100 kHz), Fast‑mode (400 kHz).
- Wake: STOP‑mode wake on address match enabled (I2C1.CR1.WUPEN = 1).
- Stretching: The device may stretch SCL up to 150 µs while staging a
  consistent snapshot for multi‑byte reads.
- Filtering: Analog filter enabled, digital filter disabled; no general‑call;
  no 10‑bit addressing.

### Access Model

- Memory‑mapped register bank with auto‑increment.
- Transactions use a 1‑byte register pointer written by the master, followed by
  an optional repeated‑start read of N data bytes (each data byte followed by a
  CRC byte，见下节 CRC Policy)。
- Byte order: Little‑endian for all multi‑byte quantities（仅对电压、电流等 u16/i16 生效）。
- Units:
  - Voltage: millivolts (mV, u16)；
  - Current: milliamps (mA, i16；放电为负)；
  - Temperature over I2C: **whole degrees Celsius (°C, int8)**，每个传感器 1 字节；
  - Temperature inside firmware: centi‑degrees Celsius (0.01 °C, i16)，仅作为内部计算单位，不直接暴露在 I2C 协议上。
- Coherency: Telemetry is snapshotted into a TX buffer at 1 Hz; multi‑byte
  reads are internally consistent. 读取侧返回 CRC（与 TI 一致，主机可选择校验，但推荐校验）。

### CRC Policy – TI‑Style (Read & Write)

- CRC: CRC‑8 polynomial 0x07 (x^8+x^2+x+1), initial value 0x00.
- Writes (mandatory, interleaved per byte): For each data byte written, the
  master must append one CRC byte computed over `[SLAVE_ADDR(W), REG_ADDR, DATA]`.
  For block writes with auto‑increment, `REG_ADDR` is the specific address of
  that data byte (i.e., it increments per byte). On CRC mismatch, the device
  NACKs the CRC byte and discards the transaction.
- Reads (device returns CRC interleaved per byte): After the master issues a
  repeated‑start and the read address, the device returns each data byte
  followed by one CRC byte. The first CRC is computed over `[SLAVE_ADDR(R), DATA0]`;
  subsequent CRCs are computed over only the corresponding data byte
  (`[DATAi]`). The master ACKs every data and CRC byte pair, and NACKs the last
  CRC byte to end the transfer.

Examples:

- Write `CHG_CONFIG` (0x31) = `AUTO=1, MANUAL=1, SPEED=0x1`:
  `START → 0x6A(W) → 0x31 → 0x07 → CRC(0x6A,0x31,0x07) → STOP`.
- Read `VBAT_MV` (0x10..0x11, 2 bytes):
  - Master: `START → 0x6A(W) → 0x10 → REPEATED START → 0x6B(R)`
  - Device returns: `D0_L, CRC0(0x6B,D0_L), D0_H, CRC1(D0_H)`; master NACKs the
    last CRC and STOPs.
- Read a burst (e.g., 8 data bytes starting at 0x10): device returns 16 bytes
  interleaved as `[D0, CRC(D0 with 0x6B), D1, CRC(D1), …, D7, CRC(D7)]`.

### Register Map

Base system info and sequencing (read‑only unless noted):

- 0x00 `SIG0` = 0x53 ('S')
- 0x01 `SIG1` = 0x42 ('B')
- 0x02 `PROTO_VER` = 0x01
- 0x03 `FW_VER_MAJOR`
- 0x04 `FW_VER_MINOR`
- 0x05 `FW_VER_PATCH`
- 0x06 `DEVICE_CAPS` bitfield (RW reserved for future, default 0)
- 0x07 `SYS_STATUS` bitfield (RO): bit0=awake, bit1=stop_capable, bit2=i2c1_ok,
  bit3=bq_ok, bit4=charger_ok, others reserved
- 0x0E RESERVED
- 0x0F RESERVED

Pack measurements (read‑only):

- 0x10 `VBAT_MV_LO`; 0x11 `VBAT_MV_HI` (u16)
- 0x12 `IBAT_MA_LO`; 0x13 `IBAT_MA_HI` (i16; discharge negative)
- 0x14 RESERVED
- 0x15 RESERVED
- 0x16 RESERVED
- 0x17 RESERVED
- 0x18 `V_CELL_MAX_MV_LO`; 0x19 `V_CELL_MAX_MV_HI` (u16)
- 0x1A `V_CELL_MIN_MV_LO`; 0x1B `V_CELL_MIN_MV_HI` (u16)
- 0x1C `DELTA_CELL_MV_LO`; 0x1D `DELTA_CELL_MV_HI` (u16)
- 0x1E `ADAPTER_PRESENT` (RO, 0/1)
- 0x1F `CELLS_PRESENT` (RO, e.g., 4 or 5)

Faults & status (read‑only unless noted):

- 0x20 `BQ_FAULTS` bitfield: bit0=UV, bit1=OV, bit2=OCD, bit3=SCD, bit4=ALERT,
  bit5=OT/UT, bit6=COMM_ERR, bit7=RESERVED
- 0x21 `CHARGER_FAULTS` bitfield: bit0=OTP, bit1=VIN_UV, bit2=VIN_OV,
  bit3=VBAT_OV, bit4=SHORT, bit5=THERM, bit6=COMM_ERR, bit7=RESERVED
- 0x22 `SYSTEM_FAULTS` bitfield: internal safety interlocks; 0 means OK
- 0x23 `TEMP_STATUS` bitfield (RO): bit0=TEMP_LOW, bit1=TEMP_HIGH_CHG, bit2=TEMP_HIGH_DSG, others reserved

Charging control and status:

- 0x30 `CHG_STATUS` (RO) bitfield: bit0=charging_active, bit1=precharge,
  bit2=CC, bit3=CV, bit4=full, bit5=balancing, bit6=adapter_present,
  bit7=blocked_by_fault
- 0x31 `CHG_CONFIG` (RW): bit0=`AUTO`, bit1=`MANUAL_ENABLE`（仅当 `AUTO=0` 时可写），bit[3:2] 选择速率档（0=slow，1≈0.8 A，2≈1.2 A，3≈1.6 A）。
- 0x32 `CHG_PAUSE_CAUSE` (RO): 暂停原因位，bit0=IMBALANCE(Δ>=100 mV)，bit1=PACK_TEMP，bit2=CHG_TEMP（SC8815 ADIN），bit3=OV/UV/OCD/SCD 冷却，bit4=HOLD_OFF 重试冷却，bit5=ADAPTER_MISS（仅自动策略硬拦），bit6=EOC_FULL。

Per‑cell voltages (length depends on `CELLS_PRESENT`, RO):

- 0x50/0x51 `CELL1_MV` (u16)
- 0x52/0x53 `CELL2_MV` (u16)
- 0x54/0x55 `CELL3_MV` (u16)
- 0x56/0x57 `CELL4_MV` (u16)
- 0x58/0x59 `CELL5_MV` (u16; present only on 5S)

Extended temperature telemetry（read‑only, all int8 in °C，地址连续便于一次性读取）:

- 0x40 `T_PACK_C`（pack temperature, °C；由内部逻辑聚合自 4×NTC/BQ/TMP75/MCU）
- 0x41 `T_CHG_C`（charger/board temperature, °C；TMP75）
- 0x42 `T_NTC0_C`（NTC0 temperature, °C）
- 0x43 `T_NTC1_C`
- 0x44 `T_NTC2_C`
- 0x45 `T_NTC3_C`
- 0x46 `T_BQ_INT_C`（BQ76920 internal temperature, °C）
- 0x47 `T_MCU_C`（MCU on‑die temperature, °C）
- 0x48–0x4F RESERVED

Diagnostics & reserved:

- 0x7C `UPTIME_S_LO`; 0x7D `_HI` (RO u16 seconds since boot)
- 0x7E `FRAME_FLAGS` (RO; bit0=snapshot_fresh)
- 0x7F RESERVED

### Semantics & Rules

- `CHG_CONFIG.AUTO` 切换自主策略。置 1 时固件依照封装阈值自行启停；置 0 时主机可通过
  `MANUAL_ENABLE` 控制功率级（仍受安全互锁约束，**不以“适配器检测为假”作为停机条件**；仅在 OV/UV/OCD/SCD/温度/严重失衡等安全场景下强制暂停）。
- `CHG_CONFIG` 的速率位提供四档限流。固件可能在故障/过温情境下降档或拒绝超限值。
- Multi‑byte writes must send the low byte first. Multi‑byte reads are
  contiguous and auto‑increment the pointer; coherency is guaranteed by the
  snapshot mechanism。读侧提供 CRC 供主机可选校验。

### Example Transactions

- Read pack voltage/current/temperature in one burst（当前固件使用“纯寄存器窗口”，未来如启用 CRC 将按相同模式在每个数据字节后插入 CRC 字节）：
  - Master: `START → 0x6A(W) → 0x10 → REPEATED START → 0x6B(R)`
  - Device returns 4 字节电压/电流快照（`VBAT_L/H`, `IBAT_L/H`），以及在单独一次读取中返回 8 字节温度窗口 `0x40..0x47`（`T_PACK_C`, `T_CHG_C`, 4×`T_NTC*_C`, `T_BQ_INT_C`, `T_MCU_C`）。  
    > 说明：早期设计中曾计划在 `0x14/0x16` 暴露 `TPACK_L/TMOS_L`（i16、0.01 °C）并对 `0x10..0x17` 做带 CRC 的长 burst；该路径已废弃，当前分支下 `0x14..0x17` 为保留位，唯一的温度入口是 `0x40..0x47` 的 int8 温度窗口。
- Enable charging (with CRC per‑byte):
  - Master: `START → 0x6A(W) → 0x31 → 0x03 → CRC(0x6A,0x31,0x03) → STOP` (`AUTO=1, MANUAL=1, SPEED=0`).
- Set current limit tier to ≈1.2 A (tier 2):
  - Master: `START → 0x6A(W) → 0x31 → 0x0B → CRC(0x6A,0x31,0x0B) → STOP` (`AUTO=1, MANUAL=1, SPEED=2`).

### Implementation Notes

- The I²C1 ISR wakes the MCU from STOP on address match, stages a copy of the
  most recent telemetry snapshot into a TX buffer, and services RX writes to the
  small control register set. The telemetry producer task updates the snapshot
  at 1 Hz to minimize bus jitter and stretching.
- Fault sources are aggregated from the BQ76920 protection loop and the SC8815
  charger loop, preserving the project’s safety‑first posture: any critical
  fault suppresses charging regardless of host requests.

### BQ76920 Task – Balancing (Strict AC Gating)

```mermaid
flowchart TD
  A0([Start]) --> A1[Read SC alerts]
  A1 --> A2{Adapter present}
  A2 -- No --> A2N[Stop balancing if any] --> A2P[Publish require cv false and overlay false] --> A99([End])
  A2 -- Yes --> A3{Evaluation due}
  A3 -- No --> A7[Prepare publish fields]
  A3 -- Yes --> A4{Charging phase}
  A4 -- No --> A7
  A4 -- Yes --> A5[Read BQ data and compute delta]
  A5 --> A6{Delta large and local peak}
  A6 -- Yes --> A6Y[Set cell balancing] --> A7
  A6 -- No --> A6N[Clear cell balancing] --> A7
  A7 --> A8[Publish balancing request] --> A99
```

### SC8815 Task – Charger Session Lifecycle (Session Begin to Session End)

```mermaid
flowchart TD
  S0([Session begin]) --> S1[Init SC8815 and start ADC]
  S1 --> IF{Init ok}
  IF -- No  --> END_INIT([Session end init fail])
  IF -- Yes --> A[Active]

  A --> PF[Fault pause]
  PF --> A
  A --> PI[Imbalance pause]
  PI --> A

  A --> END_CUT([Session end cutoff])
  A --> END_SCF([Session end sc fault])
  A --> END_STOP([Session end stop])

```

### SC8815 Task – Tick Loop

```mermaid
flowchart TD
  TEND([Tick end])
  T0([Tick start]) --> IN[Read inputs]
  IN --> ADP{Adapter present}
  ADP -- No --> END_REQ([Request session end])
  ADP -- Yes --> SCF{SC fault}
  SCF -- Yes --> END_REQ
  SCF -- No  --> CUT{Pack cutoff le 12.5V}
  CUT -- Yes --> END_REQ
  CUT -- No  --> BQF{BQ critical fault}
  BQF -- Yes --> GATE[Gate PSTOP]
  BQF -- No  --> IMB{Spread ge 100 mV}
  IMB -- Yes --> GATE
  IMB -- No  --> RES{Timer zero and faults cleared}
  RES -- Yes --> UNG[Un gate PSTOP] --> TEND
  RES -- No  --> CHK{Stop candidate Vpack ge 18.5V}
  CHK -- Yes --> BAL{Balancing not complete}
  BAL -- Yes --> CVH[Continue charging CV hold] --> TEND
  BAL -- No  --> END_REQ
  CHK -- No --> KEEP[Maintain PSTOP state] --> TEND

  GATE --> TEND
```

## Operating Thresholds & Timers

- Voltage thresholds
  - Charge start candidate: Vpack < 17.0 V
  - Stop candidate: Vpack ≥ 18.5 V
  - Pack cutoff: Vpack ≤ 12.5 V

- Balancing thresholds
  - Balancing start (by spread): Δ ≥ 10 mV
  - Severe imbalance enter: Δ ≥ 100 mV
  - Severe imbalance release: Δ < 50 mV

- Pauses / holds
  - Critical fault pause (OV/UV/OCD/SCD): 180 s
  - Imbalance pause: no timer; released by Δ < 50 mV
  - CV hold at stop candidate: continue charging while “Balancing not complete”

- Full-state hysteresis (for global state/LED)
  - Enter full: VBAT ≥ 18.5 V and IBAT ≤ 100 mA for 60 s
  - Exit full: IBAT ≥ 120 mA or VBAT < 17.0 V or not charging for 10 s

- Retry / cadence
  - SC session init failure backoff: 5 s
  - Control loop cadence: 1 s

### Global State Aggregation

```mermaid
flowchart TD
  G0([Start]) --> G1[Read inputs]
  G1 --> G2[Compute ac present and charger fault]
  G2 --> G3[Compute charging active and charging paused]
  G3 --> G4{AC present}
  G4 -- Yes --> G4Y[Update full latch timers]
  G4 -- No --> G4N[Clear full latch]
  G4Y --> G5[Compute preparing flag]
  G4N --> G5
  G5 --> G6[balancing active from overlay]
  G6 --> G7{State changed}
  G7 -- Yes --> G8[Publish global state] --> GE([End])
  G7 -- No --> G9[No publish] --> GE
```

### LED State Machine

```mermaid
flowchart TD
  L0([Start]) --> L1{Fault}
  L1 -- Yes --> Lf[Blink 4Hz] --> Lend([End])
  L1 -- No --> L2{Charging}
  L2 -- Yes --> Lc[Blink 1Hz add notches when balancing] --> Lend
  L2 -- No --> L3{Preparing}
  L3 -- Yes --> Lp[Two pulses per second] --> Lend
  L3 -- No --> L4{Full}
  L4 -- Yes --> Lfull[Solid on] --> Lend
  L4 -- No --> Lidle[Off] --> Lend
```

## 12) TMP75AIDGKR Hardware Over‑Temperature Window (55 °C / 45 °C)

Design intent

- Provide a **purely hardware** over‑temperature cut‑off for the SC8815 power stage using the on‑board TMP75AIDGKR (`U12`), independent of firmware logic.
- Hard‑stop the charger whenever the local board temperature exceeds **55 °C**, and only allow hardware to release this stop once the temperature falls below **45 °C**.
- Replace the legacy SC8815‑ADIN (NTC) based temperature policy on current boards
  and implement a two‑stage protection scheme using TMP75:
  - Hardware window: 55 °C trip / 45 °C release (TEMP_FAULT_N → PSTOP hard stop).
  - Software window: 50 °C / 40 °C / 0 °C thresholds for soft gating of `PSTOP_MCU`
    (see “Software temperature policy (TMP75‑based)” below).

Relevant hardware connections (netlist summary)

- TMP75AIDGKR (`U12`) pins:
  - `1` → `INNER_SDA`
  - `2` → `INNER_SCL`
  - `3` → `TEMP_FAULT_N` (open‑drain alert output, external pull‑up via `R58` to 3.3 V)
  - `4..7` → `BGND` (A2/A1/A0 all tied low)
  - `8` → `3V3`
- I²C parameters:
  - Bus: `I2C2` (INNER, shared with BQ76920 @ `0x08` and SC8815 @ `0x11`).
  - TMP75A 7‑bit address: `0x48` (`1001_000`, with A2=A1=A0=0).
- Alert → charger gating chain (from hardware docs):
  - `TEMP_FAULT_N` high = temperature within window; low = over‑temperature.
  - `PSTOP_CTL = TEMP_FAULT_N · PSTOP_MCU` (U22 = SN74AUP1G08DCKR).
  - Board‑level inversion (`BOARD_INV`) drives SC8815: `PSTOP = ¬PSTOP_CTL`.
  - Result: if `TEMP_FAULT_N = 0` **or** `PSTOP_MCU = 0`, then SC8815 `PSTOP = High` (power stage forced stop).

TMP75 configuration (firmware obligations)

- Configure once during smart‑battery initialization on the INNER I²C bus:
  - Mode: **comparator / window mode** (`TM = 0`), not interrupt/latch mode.
  - Alert polarity: **active‑low** (`POL = 0`), open‑drain (matches `TEMP_FAULT_N` semantics).
  - Conversion: 12‑bit resolution, continuous conversion.
  - Fault queue: use a small queue (e.g. 4 consecutive faults) to suppress single‑sample glitches.
- Program the window registers:
  - `THIGH = 55 °C` (over‑temperature trip point).
  - `TLOW = 45 °C` (hardware release point, providing 10 °C hysteresis).
  - Use the TMP75 temperature format (0.0625 °C/LSB, signed) when encoding values; exact bit‑level mapping lives in the driver.
- Optional but recommended:
  - Provide a `read_temperature()` helper to read the TMP75 temperature register for diagnostics and logging.
  - Log the configured window (THIGH/TLOW in °C and raw register values) once at boot for bench verification.

Resulting behavior (normative)

- Over‑temperature (>55 °C region):
  - TMP75 detects temperature above `THIGH` and drives `TEMP_FAULT_N` **low**.
  - Hardware derives `PSTOP_CTL = 0` regardless of `PSTOP_MCU`.
  - After board inversion, SC8815 sees `PSTOP = High` and the power stage is **forced off**.
  - Firmware **cannot** override this; any attempt to re‑enable the power stage while `TEMP_FAULT_N = 0` is vetoed by hardware.
- Cool‑down (<45 °C region):
  - TMP75 keeps `TEMP_FAULT_N` low until temperature drops below `TLOW = 45 °C`.
  - Once `TEMP_FAULT_N` returns high, hardware allows `PSTOP_CTL = PSTOP_MCU` again.
  - The SC8815 power stage only resumes if firmware explicitly sets `PSTOP_MCU = 1` and all other safety conditions are satisfied.
- In‑between region (45–55 °C):
  - TMP75 behavior is determined by its internal comparator hysteresis; with the programmed window, this becomes the gray zone between trip and release.
  - Firmware uses TMP75 temperature readings (not ADIN) to implement additional
    **soft** over‑temperature and low‑temperature gating thresholds.

Software temperature policy (TMP75‑based, replaces ADIN logic)

- Temperature source: TMP75 local board temperature (°C), sampled in the
  SC8815 charger task.
- High‑temperature soft stop:
  - While the charger power stage is running, if `T ≥ 50 °C` for at least two
    consecutive samples, firmware immediately stops the power stage via
    `PSTOP_MCU = 0`, marks `sc_temp_pause_active = true`, and records a “HOT”
    cause with a time stamp.
  - This is strictly below the hardware 55 °C trip, so soft logic should engage
    first under normal conditions.
- Cool‑down resume (HOT path):
  - After a HOT stop, once `T ≤ 40 °C` for at least two consecutive samples and
    a 10‑second dwell window (`TMP_RESUME_DELAY_MS`) has elapsed, firmware
    clears `sc_temp_pause_active` and allows the charger to resume (subject to
    other pause conditions).
- Low‑temperature inhibit:
  - If `T ≤ 0 °C` for at least two consecutive samples, firmware latches a
    “cold pause” (`cold_latch_active = true`) that prevents charging until the
    pack warms back above 0 °C.
  - Resume from cold: once `T > 0 °C` for at least two consecutive samples,
    firmware clears the cold latch and allows charging to resume.
- Dwell window:
  - A one‑shot 10‑second dwell window is applied after any run→stop edge so
    that temperature‑driven resumes are not evaluated immediately after the
    power stage stops (mirrors the legacy ADIN settle window, but now applied
    purely in time, not via 3 V/5 V ADC mappings).

Scope and non‑goals

- On current production hardware, TMP75 is the **only** board‑level temperature
  sensor used by the charger logic; the SC8815 ADIN+NTC network is not
  populated and the corresponding code path is considered legacy (see §11).
- The charger control logic and LED codes remain as defined elsewhere in this
  document; TMP75 only influences the “temperature pause” dimension (soft) and
  the hard 55 °C/45 °C window.
- Future work (if needed) may:
  - Allow the host (via I2C1) to adjust THIGH/TLOW within a constrained range.
  - Incorporate TMP75 readings into higher‑level derating policies (e.g. pre‑emptive pause before 55 °C).

## Multi‑Sensor Pack Temperature Architecture (BQ + TMP75 + 4×NTC)

> 本节在系统层面定义“电池温度”的来源与保护策略，覆盖 BQ76920 内部温度、板载 TMP75 以及 4 路贴在电芯之间的 NTC。实现落地后，本节描述将取代“仅依赖 BQ 内部温度”的旧策略；旧节保留作为回退方案说明。

### Sensors & Placement

- **BQ76920 internal temperature (`T_BQ_INT`)**
  - 来源：BQ76920 TEMP 寄存器，当前驱动暴露为 `temperatures.ts1`（单位 0.01 °C）。
  - 语义：靠近 AFE 本体的“IC/板边环境温度”，偏向电路板热点监控，而非严格意义上的电芯壳温。
  - 硬件说明：PCB 上虽然在 TS1 附近保留了外部 NTC 焊盘，但当前量产版本 **不焊接该 NTC**，TS1 仅用于芯片内部温度模式，**不再作为外部电芯温度输入**。

- **TMP75A local board sensor (`T_TMP75`)**
  - 位置：靠近 SC8815 / 功率区，用于反映充电路径附近的板温。
  - 语义：充电硬件温度，主要服务于“充电路径过温保护”（见上一节 55 °C/45 °C 硬件窗口及 50 °C/40 °C 软窗口）。

- **4× 外置 NTC between cells (`T_NTC[0..3]`)**
  - 器件：NTC 10 kΩ β3380（R46/R48/R50/R52），每个 NTC 粘在两节电池中间区域，总共覆盖 5 节电芯的 4 个间隙。
  - 网络：每路 NTC 一端接 `BGND`，一端接 `TS12/TS23/TS34/TS45`；对应节点通过 43 kΩ 上拉电阻（R47/R49/R51/R53）接至 `NTC_3V3`，并由 100 nF（C62..C65）到 `BGND` 滤波。
  - MCU 连接：
    - `TS45` → STM32 `PA0/ADC_IN0`
    - `TS34` → STM32 `PA1/ADC_IN1`
    - `TS23` → STM32 `PA2/ADC_IN2`
    - `TS12` → STM32 `PA3/ADC_IN3`
    - `NTC_3V3` → STM32 `PB12`（GPIO，作为可控上拉电源）
  - 语义：**电芯表面/中间温度**，是“电池包过温保护”的主数据源。

- **MCU on‑die temperature (`T_MCU`)**
  - 来源：STM32L051 内部温度传感器通道，经 ADC 读取并换算到 0.01 °C。
  - 语义：MCU 结温，用于检测控制器自身是否进入高温区域，也是“任何一点 >60 °C 必须切断输入/输出”的参与者之一。

### Sampling & In‑Memory Representation

目标：周期性（典型 1 Hz，在活动状态下）刷新以下温度到内存，统一挂入测量结构并对外暴露：

- `T_BQ_INT`：由 BQ 任务按“Temperature Sensing & Protection (BQ76920 Internal Sensor)”节所述节拍采样并滤波。
- `T_TMP75`：由 TMP75 驱动在 INNER 总线上周期性读取；单位统一为 0.01 °C（内部采用 Q4 映射）。
- `T_NTC[i]`（i=0..3）：由 MCU ADC 周期性采样 4 路通道并换算温度：
  - 采样过程（单次周期）：
    1. 将 `PB12/NTC_3V3` 置为推挽高，给 4 路 43 k 上拉供电。
    2. 延时 ≥ 温度网络稳态时间（设计上参考 `battery_temp_sensing.md` 中给出的 RC 常数，约 18 ms 量级）。
    3. 依次触发 ADC1 `IN0..3` 单次转换，并可选做简单平均/中值滤波。
    4. 关闭 `PB12`（输出低或高阻），避免长期静态电流消耗。
  - 换算：采用与 `battery_temp_sensing.md`、`firmware/ups-main/src/adin_temp.rs` 一致的 10 k/B3380 + 43 k 上拉模型，将电压/码值转换为温度（°C），内部存储为 0.01 °C。

聚合结构（逻辑概念，实际字段名由实现决定）：

- `t_bq_int_0_01c` – BQ 内部温度。
- `t_tmp75_0_01c` – TMP75 板温。
- `t_ntc_0_01c[4]` – 4 路 NTC 温度。
- `t_ntc_max_0_01c` / `t_ntc_min_0_01c` – NTC hottest/coldest。
- `t_mcu_0_01c` – MCU 内部温度。
- `t_pack_safety_0_01c` – 用于对外和保护决策的“单一代表值”，默认为 `max(T_BQ_INT, T_TMP75, t_ntc_max, T_MCU)`。

这些字段将：

- 汇入内部 `AllMeasurements` / `AllMeasurementsUsbPayload` 等测量结构；
- 由 I2C1 从机任务在快照时复制到寄存器窗口（参见“External Communications (I2C1 Slave)”节）。

### NTC‑Based Over‑Temperature Policy

> 这部分策略以 4 路 NTC 为中心，TMP75 负责“充电路径保护”，BQ 内部温度负责 IC 自身保护。NTC 视为“电池包温度”的主裁判。

记 `T_NTC_MAX = t_ntc_max_0_01c / 100`（°C，取 4 路 NTC 中最高值）。

分三级：

1. **预警级（Pack OT Warn）– 55 °C**

   - 条件：`T_NTC_MAX ≥ 55 °C`，持续若干个采样周期（例如 2–3 次），避免单点毛刺。
   - 动作：
     - 在内部状态字中置位 `PACK_OT_WARN` 标志。
     - 在 I2C1 从机寄存器中更新对应状态位（例如 `SYSTEM_FAULTS` 或新增温度状态寄存器中的 bit）。
     - 触发对主机的**过温中断通知**：
       - 首选：通过 I2C1 的 SMBus Alert 线（PB5/I2C1_SMBA）拉动，实现硬件级“attention”；
       - 若 SMBus Alert 尚未实现，则在协议层约定主机周期轮询对应状态位。
   - 不做强制断电，仅作为“即将达到硬保护”的预警。

2. **硬切断级（Pack OT Trip） – 60 °C**

   - 条件：`T_NTC_MAX ≥ 60 °C`（同样可带少量采样去抖）。
   - 动作：
     - 立刻通过 BQ 任务请求 **切断放电路径**：
       - 关闭 BQ76920 `DSG` FET（必要时也关闭 `CHG`，形成双向断开），等价于“切断电池输出”。
     - 在内部状态中置位 `PACK_OT_TRIP`，并保持**锁存**，直至温度回到安全窗口。
     - 在 I2C1 状态寄存器中暴露该硬切断原因，便于主机区分“电压类故障 vs 温度类故障”。
     - 可选：在 LED 状态机中映射到故障优先级（例如复用现有 Fault 模式，不新增花样）。

3. **恢复级（Pack OT Recover） – 40 °C**

   - 条件：上一周期处于 `PACK_OT_TRIP`，且 `T_NTC_MAX ≤ 40 °C` 持续若干采样周期（建议 ≥2 次）。
   - 动作：
     - 清除 `PACK_OT_TRIP` 锁存，允许 BQ 任务按常规规则重新打开 `DSG` / `CHG` FET（仍受 OV/UV/OCD/SCD 等保护限制）。
     - 可保留 `PACK_OT_WARN` 位，直到温度继续下降到 <50 °C 以外（具体阈值可根据后续测试微调）。

> 以上 55/60/40 °C 阈值可以视为默认项目策略：55 °C 启动主机预警，60 °C 强制断电保护，40 °C 明确回到安全区后恢复。与既有 BQ 内部温度/TMP75 50/40 °C 软窗口、55/45 °C 硬窗口保持大致一致但角色分工不同：  
> - TMP75 负责“板级/充电路径”保护；  
> - NTC 负责“电池包/电芯”保护；  
> - BQ 内部温度作为 IC 自保护与兜底阈值（例如极端 70 °C/−10 °C 切断）。

### I2C Register Exposure (Summary)

本项目阶段性的共识如下：

- **内部温度表示**：固件内部统一使用 `i16`、单位 0.01 °C（centi‑degree）存放 BQ/TMP75/NTC/MCU 温度，用于比较阈值（40/50/55/60 °C）、做滤波和滞环。
- **I2C 温度表示**：对外通过 I2C 寄存器暴露的温度，一律使用 **`int8`、单位 1 °C**，每个传感器占用 1 字节。内部 centi‑degree 会在快照阶段通过 `round(T_internal/100)` 压缩成 1 °C 步进。

温度相关寄存器（与上文 Register Map 保持一致，0x40–0x47 为唯一温度入口，0x14..0x17 不再承载温度数据）：

- 温度窗口（均为 `int8`、单位 1 °C）：
  - `0x40 T_PACK_C`：电池温度（°C，NTC hottest / 多源聚合后的 pack 温度）。
  - `0x41 T_CHG_C`：充电器/板级温度（°C，来自 TMP75）。
  - `0x42..0x45 T_NTC0_C..T_NTC3_C`：4 路 NTC 分别对应的温度（°C，按固定顺序映射 TS12/TS23/TS34/TS45）。
  - `0x46 T_BQ_INT_C`：BQ76920 内部温度（°C）。
  - `0x47 T_MCU_C`：MCU 内部温度（°C）。

- 温度保护状态：
  - `0x23 TEMP_STATUS`：
    - bit0 `TEMP_LOW`：温度过低（导致充放电都不允许）。
    - bit1 `TEMP_HIGH_CHG`：充电温度过高（不允许充电）。
    - bit2 `TEMP_HIGH_DSG`：放电温度过高（不允许放电，通常已切断输入输出）。
  - `CHG_PAUSE_CAUSE.PACK_TEMP`：仅表示“因温度暂停充电”，具体是哪一类温度保护由 `TEMP_STATUS` 三个位来细分。

主机侧推荐策略：

- 常规轮询时优先读取 `0x40..0x47`（温度窗口）和 `TEMP_STATUS`：
  - `TEMP_LOW`=1 → 温度过低；
  - `TEMP_HIGH_CHG`=1 → 当前禁止充电；
  - `TEMP_HIGH_DSG`=1 → 当前禁止放电（以及可能已经切断 pack 输出）。
- 由于 `0x40..0x47` 连续，主机可以通过一次 burst 读取拿到所有温度，再结合 `TEMP_STATUS` 做判定；必要时也可以只读取 `T_PACK_C` 作为 pack 温度概要。

### Interaction With Existing Policies

- BQ 内部温度节（“Temperature Sensing & Protection (BQ76920 Internal Sensor)”）继续生效，用于：
  - 在 NTC 或 TMP75 故障情况下提供兜底保护；
  - 在极端温度（例如 >70 °C 或 <−10 °C）下强制切断 FET。
- TMP75 节继续负责：
  - 对 SC8815 充电路径提供 55 °C/45 °C 硬件窗口；
  - 在 50 °C/40 °C 附近对充电进行软暂停。
- 新的 NTC 策略专注于“电芯温度”，其 60 °C/40 °C 窗口优先用于决定是否允许电池对外供电；当多个策略同时触发时，系统遵循“更保守（更安全）”的组合结果。

实现时应确保：

- 单一温度事件只在一个地方做**决策**，其结果通过已有 pub/sub 结构（如 `BalancingCvRequest`、`state_bits` 等）传播；
- I2C 寄存器与内部状态位保持一一对应关系，便于主机调试和现场问题追踪。

### Unified Thermal Protection Policy (System‑Level)

> 本小节是**系统级规范**，覆盖四路温度：电池温度（4×NTC hottest）、充电器温度（TMP75）、均衡温度（BQ 内部）、MCU 温度。上文各小节的单独阈值说明在实现时都应服从这里的统一规则。

记：

- `T_PACK`：电池温度 = 4 路 NTC 中最高值；
- `T_CHG`：充电器温度 = TMP75；
- `T_BAL`：均衡温度 = BQ 内部；
- `T_MCU`：MCU 结温；
- `T_MAX = max(T_PACK, T_CHG, T_BAL, T_MCU)`；
- `T_MIN = min(T_PACK, T_CHG, T_BAL, T_MCU)`。

统一规则：

- **放电允许温度窗口**：`-10 °C ≤ 所有传感器 ≤ 60 °C`  
  - 任意一个温度 < −10 °C 或 > 60 °C → 禁止放电（`DSG` FET 关闭，视为断开电池输出）。

- **充电允许温度窗口**：`-10 °C ≤ 所有传感器 ≤ 55 °C`  
  - 任意一个温度 < −10 °C 或 > 55 °C → 禁止充电（`CHG` FET 关闭 / 充电器暂停）。

- **充电期间的电池高温暂停**：
  - 当处于“充电中”状态且 `T_PACK ≥ 55 °C`、`T_MAX < 60 °C` 时：
    - 立即暂停充电（通过 `PSTOP_MCU` / `CHG` FET），但**保持放电路径导通**；
    - 置位“充电温度过高”状态（见下节 I2C 状态位）。

- **60 °C 硬切断**：
  - 当 `T_MAX ≥ 60 °C`（任意一条温度 ≥60 °C）时：
    - 立即切断电池组输入和输出：关闭 `CHG` 和 `DSG` FET，禁止 SC8815 再次拉电流；
    - 置位“放电温度过高”状态并锁存，直到降温满足恢复条件。

- **低温保护**：
  - 当 `T_MIN < −10 °C` 时：
    - 禁止充放电（`CHG`/`DSG` 关闭），记为“温度过低”状态；
  - 当所有温度回到 `T_MIN ≥ −10 °C` 且满足下述 50 °C/40 °C 恢复条件后，才允许重新放电/充电。

- **恢复阈值（全局）**：
  - 放电恢复：只有当所有传感器满足 `T_MAX ≤ 50 °C` 且 `T_MIN ≥ −10 °C` 时，才允许重新打开放电路径；
  - 充电恢复：只有当所有传感器满足 `T_MAX ≤ 40 °C` 且 `T_MIN ≥ −10 °C` 时，才允许再次进入充电状态。

- **均衡约束**：
  - 温度不在“充电允许窗口”（即任意传感器 < −10 °C 或 > 55 °C），或者任一温度保护状态（低温 / 高温充电 / 高温放电）为真时：
    - 必须立即停止任何均衡行为，不得在温度保护期间继续均衡。

### I2C Temperature Protection Status Bits

I2C 从机温度保护状态对外暴露三类信息，用于主机快速判定当前温度限制类型（寄存器具体地址由实现时在“Register Map”节中补充或更新）：

- `TEMP_LOW` – 温度过低（包含充电和放电）：
  - 语义：任一温度 < −10 °C，或者因为低温导致当前充放电被禁止；
  - 满足放电/充电恢复条件后自动清零。

- `TEMP_HIGH_CHG` – 充电温度过高：
  - 语义：当前不允许充电，但放电路径**有可能**仍允许：
    - 电池温度 `T_PACK ≥ 55 °C` 触发的充电暂停；或
    - `T_MAX ≥ 60 °C` 的硬切断场景（此时通常 `TEMP_HIGH_DSG` 也为 1）。

- `TEMP_HIGH_DSG` – 放电温度过高：
  - 语义：当前不允许放电，通常意味着 `T_MAX ≥ 60 °C` 导致已经切断电池输出；
  - 与 `TEMP_HIGH_CHG` 并存时，表示“高温下输入输出均已被切断”。

实现建议：

- 这三个状态可以统一打包在一个系统级温度状态寄存器中（例如复用或扩展 `SYSTEM_FAULTS`），并在 `CHG_PAUSE_CAUSE.PACK_TEMP` 中仅表征“因温度暂停充电”的原因，而不再携带全部细节；  
- 上层主机若需要细粒度诊断，应结合多源温度读数（`T_PACK/T_CHG/T_BAL/T_MCU`）与上述三个位进行推断。

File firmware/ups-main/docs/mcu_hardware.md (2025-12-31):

# UPS 主控 MCU 引脚一览

| Pad | 名称 | GPIO | Net | 说明 |
| --- | ---- | ---- | --- | ---- |
| 1 | LNA_IN | — | — | 射频输入（天线匹配） |
| 2 | VDD3P3 | — | — | 数字 3V3 电源 |
| 3 | VDD3P3 | — | — | 数字 3V3 电源 |
| 4 | CHIP_PU | — | CHIP_EN | 芯片使能（高有效） |
| 5 | GPIO0 | 0 | BTN_CENTER | 五向中键（内部上拉） |
| 6 | GPIO1 | 1 | BTN_UP | 五向上（内部上拉） |
| 7 | GPIO2 | 2 | BTN_RIGHT | 五向右（内部上拉） |
| 8 | GPIO3 | 3 | — | 启动绑带：JTAG 信号源选择（usb_to_jtag/pad_to_jtag），复位采样；不建议占用 |
| 9 | GPIO4 | 4 | BTN_DOWN | 五向下（内部上拉） |
| 10 | GPIO5 | 5 | BTN_LEFT | 五向左（内部上拉） |
| 11 | GPIO6 | 6 | RESET# | 外设复位（TCA6408A RESET#，外部上拉；建议内部上拉） |
| 12 | GPIO7 | 7 | INT | I2C 从设备中断（开漏，低有效） |
| 13 | GPIO8 | 8 | SDA | I2C 主机 SDA |
| 14 | GPIO9 | 9 | SCL | I2C 主机 SCL |
| 15 | GPIO10 | 10 | DC | SPI 屏 DC（GC9D01） |
| 16 | GPIO11 | 11 | MOSI | SPI 屏 MOSI |
| 17 | GPIO12 | 12 | SCLK | SPI 屏 SCLK |
| 18 | GPIO13 | 13 | CS | SPI 屏 CS |
| 19 | GPIO14 | 14 | RES | SPI 屏复位 |
| 20 | VDD3P3_RTC | — | — | RTC 3V3 电源 |
| 21 | XTAL_32K_P | — | — | 32.768 kHz 晶振 P（本板未用） |
| 22 | XTAL_32K_N | — | — | 32.768 kHz 晶振 N（本板未用） |
| 23 | GPIO17 | 17 | — | 未连接 |
| 24 | GPIO18 | 18 | — | 未连接 |
| 25 | GPIO19 | 19 | ESP_DM | USB D−（原生 USB，经 R2 串联；使用 USB 时不建议复用） |
| 26 | GPIO20 | 20 | ESP_DP | USB D+（原生 USB，经 R3 串联；使用 USB 时不建议复用） |
| 27 | GPIO21 | 21 | USB2_PG | 来自 HUSB305‑01 STAT，开漏，低有效 |
| 28 | SPICS1 | — | — | 内置 Flash/PSRAM 通道（保留，不建议使用） |
| 29 | VDD_SPI | — | — | 内部 SPI 供电 |
| 30 | SPIHD | — | — | 内置 Flash/PSRAM 专用（保留，不建议使用） |
| 31 | SPIWP | — | — | 内置 Flash/PSRAM 专用（保留，不建议使用） |
| 32 | SPICS0 | — | — | 内置 Flash/PSRAM 专用（保留，不建议使用） |
| 33 | SPICLK | — | — | 内置 Flash/PSRAM 专用（保留，不建议使用） |
| 34 | SPIQ | — | — | 内置 Flash/PSRAM 专用（保留，不建议使用） |
| 35 | SPID | — | — | 内置 Flash/PSRAM 专用（保留，不建议使用） |
| 36 | SPICLK_N | — | — | Octal 外设差分时钟 N（本板未用） |
| 37 | SPICLK_P | — | — | Octal 外设差分时钟 P（本板未用） |
| 38 | GPIO33 | 33 | — | 未连接 |
| 39 | GPIO34 | 34 | — | 未连接 |
| 40 | GPIO35 | 35 | — | 未连接 |
| 41 | GPIO36 | 36 | — | 未连接 |
| 42 | GPIO37 | 37 | — | 未连接 |
| 43 | GPIO38 | 38 | BUZZER | 蜂鸣器（无源，2.7 kHz PWM） |
| 44 | MTCK | 39 | FAN_EN | 风扇使能（由 MTCK 改作 GPIO39 输出；默认 JTAG 脚位） |
| 45 | MTDO | 40 | FAN_PWM | 风扇 PWM（由 MTDO 改作 GPIO40 PWM 输出；默认 JTAG 脚位） |
| 46 | VDD3P3_CPU | — | — | CPU 3V3 电源 |
| 47 | MTDI | 41 | — | JTAG TDI（未连接，量产不建议占用；JTAG 默认引脚） |
| 48 | MTMS | 42 | — | JTAG TMS（未连接，量产不建议占用；JTAG 默认引脚） |
| 49 | U0TXD | — | TX1 | UART0 TX（默认日志/下载口，建议保留；测试点） |
| 50 | U0RXD | — | RX1 | UART0 RX（默认日志/下载口，建议保留；测试点） |
| 51 | GPIO45 | 45 | — | 启动绑带：VDD_SPI 电压配置相关；不建议使用（复位采样） |
| 52 | GPIO46 | 46 | — | 启动绑带/日志：UART Boot 打印控制；不建议使用（复位采样） |
| 53 | XTAL_N | — | — | 40 MHz 晶振 N |
| 54 | XTAL_P | — | — | 40 MHz 晶振 P |
| 55 | VDDA | — | — | 模拟电源 |
| 56 | VDDA | — | — | 模拟电源 |
| 57 | GND(EP) | — | — | 裸焊盘接地 |

注：USB2_PG 为 HUSB305‑01 的 STAT 输出逻辑，详见 `docs/datasheets/HUSB305-01.md`。

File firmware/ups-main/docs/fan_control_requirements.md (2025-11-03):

# UPS 主控风扇调速需求与任务规划

> 版本：2025-10-19  
> 适用分支：`feature/fan-control`  
> 目标硬件：ESP32‑S3 主控 + 两线直流风扇（`FAN_EN`=GPIO39，`FAN_PWM`=GPIO40，经 RC 滤波调制 LDO）

## 1. 背景与现状

- 硬件链路采用两线风扇，无转速反馈，PWM→电压通过 LDO 反馈网络实现。
- 现有固件仅提供 GPIO/LEDC 初始化与占空比示例，不含温度闭环或安全保护。
- TSENS 读取存在显著偏差：在环境约 32 °C 情况下测得 ≈7 °C（`raw≈35`），说明当前采样/换算流程未正确应用 eFuse 校准或量程配置。

## 2. 功能需求

| 编号 | 类型 | 描述 |
| --- | --- | --- |
| FR-1 | 功能 | 解析 ESP32‑S3 TSENS 传感器，按官方 HAL/IDF 流程完成初始化、量程选择、eFuse 校准补偿，获得合理芯温。 |
| FR-2 | 功能 | 构建温度→占空比（GPIO40 实际 PWM%）的控制策略，按 VIN 状态分支：<br>• VIN 存在（当前默认）：`<35 °C` 关风扇；`35–45 °C` 固定 96%；`>45 °C` 时以 45 °C 为目标在 96%~0% 范围内压制温度；温度降回 `<35 °C` 再次停转。<br>• VIN 缺失：`<40 °C` 关风扇；`≥40 °C` 全部以 45 °C 为目标调节，占空比限定在 96%~0%。|
| FR-3 | 功能 | 支持占空比限斜率（默认 ±5%/500 ms）与温度滞回（默认 3 °C）。 |
| FR-4 | 功能 | 温度 ≥ 80 °C 时强制 `FAN_EN=High`、占空比 100%；温度异常（读数无效或校准缺失）时进入安全占空比（默认 50%）。 |
| FR-5 | 功能 | 定期日志输出（建议每 2 s）包含温度、原始 ADC、当前量程、校准参数、目标/实际占空比、故障标志。 |
| FR-6 | 功能 | 提供启动蜂鸣提示或诊断输出，帮助定位 TSENS 初始化失败、校准缺失等问题。 |
| FR-7 | 非功能 | 所有硬件操作遵循 60 s 内完成的运行约束；日志需友好可读，便于远程调试。 |

## 3. 技术约束

- **HAL 选型**：使用 `esp-hal`（当前版本 1.0.0-rc.1），需参考其 `tsens`、`ledc` API，必要时补齐底层寄存器操作。
- **TSENS 校准**：按照 IDF `temperature_sensor_hal.c`、`sar_periph_ctrl_common.c`、`esp_efuse_rtc_calib.c` 的顺序初始化：启用 APB_SARADC 时钟、REGI2C、电源、量程；利用 eFuse `TEMP_CALIB`（BLOCK2 bit132..140）读取 `delta_T`，按 0.1°C 缩放补偿。
- **硬件限制**：两线风扇无转速反馈，仅能开环；若未来加入 PCNT，应保持模块化封装。
- **最低占空比**：实测风扇在实际 PWM 输出低于 ≈97% 时无法启动，固件需将“最低转速”钳制在 `96%`。
- **运行约束**：`make ups-run` 监控受限（espflash monitor 可能退出），需提供备用串口读取脚本或说明。

## 4. 任务拆解

1. **TSENS 驱动修复**
   - 复刻 IDF 的 `temperature_sensor_power_acquire()/temp_sensor_get_raw_value()` 流程，采用 `esp_hal::peripherals::SYSTEM/RTC_CNTL/SENS` 寄存器直接配置；
   - 实现量程表（`offset/reg_val`）与自动切换策略；确保默认量程 `-10~80 °C`；
   - 读取 eFuse `TEMP_CALIB`，处理版本判断（`rtc_calib_version()==1`）及无校准 fallback；
   - 输出诊断信息：raw、base（未补偿）温度、delta_T、量程索引。

2. **风扇控制逻辑**
   - 建立温度采样调度（建议 500 ms 周期）；实现开环曲线、滞回、限斜率；
   - 集成 EN 控制：0% → 关闭 GPIO39，高占空比 → 先拉高 EN 再设置 duty；
   - 异常保护：传感器失效或温度越界时进入安全模式并记录日志。

3. **配置与可调参数**
   - 提供常量或结构体集中定义温度节点、占空比、滞回、限斜率、安全占空比；
   - 若可能，读取 `cfg` 或 `const` 以便未来迁移到外部配置。

4. **日志与测试工具**
   - 统一日志格式：`TEMP=xxx°C RAW=yy ATTR=z DELTA=... DUTY=... MODE=...`；
   - 提供 README/文档更新，说明如何使用 `cat /dev/cu.usbmodem*` 或 Python 脚本读取日志；
   - 记录测试步骤与结果（真实硬件验证、环境温度与芯温差、稳定性）。

## 5. 验收标准

- 正常室温（25–32 °C）下，温度日志应落在合理区间（允许芯温高于环境 5–10 °C），不再出现固定 ≈7 °C 的异常。
- 通过加热或风扇阻挡实验，温度升高时占空比正确提升，≥80 °C 时进入强制全速。
- 断开或故意破坏 TSENS 流程（例如禁用校准）时，系统进入安全占空比并打印错误。
- `make ups-run` 60 s 内可获取至少一次完整日志；辅助脚本说明可在 README 内找到。

## 6. 文档与后续

- 更新 `active_cooling_2wire.md` 的“参数建议”部分，填入实测数值。
- 在 README 或专门文档记录标定流程、测试数据与已知偏差。
- 后续考虑：结合外部温度传感器/风扇反馈、加入 CLI/串口命令调参、强化单元/集成测试。

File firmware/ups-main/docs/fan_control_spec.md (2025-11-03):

# UPS 主控两线风扇调速规范

> 版本：2025-10-19  
> 适用分支：`feature/fan-control`  
> 撰写：心羽（ESP32‑S3 主控项目猫娘）

---

## 1. 设计目标

1. 通过 MCU 产生的 25 kHz PWM、两级 RC 滤波及 LDO（RT9043GB）反馈调节，实现对两线直流风扇的线性调压控制。
2. 依据芯片内部温度传感器（TSENS）实时调节风扇转速，确保 UPS 主控在 0 °C–80 °C 范围内稳定运行。
3. 提供完整的安全保护、诊断日志与测试流程，便于现场调试和后续扩展（如闭环 RPM）。

---

## 2. 硬件设计

### 2.1 拓扑与接口

- 电源路径：`5 V → RT9043GB → FAN_VCC → 风扇 (+)`，风扇负端接 `FAN_VSS`。
- 控制引脚：
  - `FAN_PWM = GPIO40`（LEDC 低速组，25 kHz 方波）；
  - `FAN_EN = GPIO39`（推挽输出，高有效，直连 LDO EN）。
- RC 滤波：双极 RC（`R12/R13` + `C24/C25`）对 PWM 进行低通过滤。
- 反馈注入：经 `R56` 将滤波后的电压注入 LDO FB；`R9/R11` 作为主分压；`D2` 负责钳位 FB 下限。

参考原理图如下：

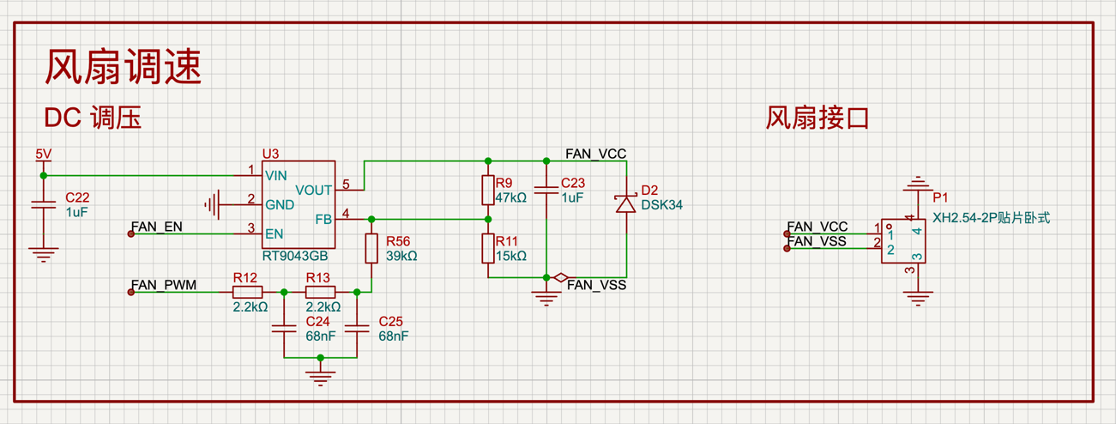
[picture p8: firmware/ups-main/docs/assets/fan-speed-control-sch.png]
fan-speed-control-sch


| 项目 | 数值 / 器件 | 备注 |
| ---- | --- | ---- |
| LDO 型号 | RT9043GB | 1.2 V 基准，EN 高有效 |
| 分压网络 | R9 = 47 kΩ，R11 = 15 kΩ | 理论空载输出 `VOUT0 = 1.2 × (1 + 47k/15k) ≈ 5.0 V` |
| PWM 注入 | R56 = 39 kΩ | 与分压点并联注入电流 |
| RC 滤波 | R12 = R13 = 2.2 kΩ，C24 = C25 = 68 nF | 25 kHz 时提供双极低通 |
| 钳位保护 | D2 = DSK34 Schottky | 正向约 0.3 V，限制 FB 最低电位 |
| 输入/输出电容 | C22 = 1 µF，C23 = 1 µF | 依据原理图 |

### 2.2 PWM → 电压近似

忽略钳位影响时，可推得：

```
VOUT(d) ≈ VOUT0 − k · d
VOUT0 ≈ 4.96 V
k ≈ (R9/R56) × 3.3 V ≈ 3.98 V
```

因此：

| 占空比 d | 理论输出 |
| --- | --- |
| 0% | ≈ 5.0 V |
| 60% | ≈ 2.6 V |
| 80% | ≈ 1.8 V |
| 100% | ≈ 1.0 V |

Schottky 钳位会把最小电压限制在约 1.4 V（按 `Vout_min ≈ Vin − (Vin − Vf)·R9/(R9+R11)` 估算，取 `Vin=5 V`、`Vf≈0.3 V`）。实际最小电压取决于风扇载流与二极管温度。

---

## 3. 软件设计

软件部分围绕 TSENS 采样、温控调速、保护/诊断三个层面展开。

### 3.1 温度采样（TSENS）

1. 参考 ESP-IDF `temperature_sensor_hal` 与 `sar_periph_ctrl_common` 初始化流程：开启 `APB_SARADC` 时钟 → REGI2C 供电 → TSENS XPD → 设置初始量程（默认 `-10°C~80°C`）。
2. 读取 eFuse `TEMP_CALIB` 字段（Block2 bit132..140），判断 `rtc_calib_version()==1` 后按 0.1 °C 缩放补偿；若 eFuse 未烧录，退回默认偏移并打印警告。
3. 初次启用后延时 ≥300 µs 再取值；正常循环每 500 ms 采一次，使用 3 点中值滤波抵御抖动。

### 3.2 转速控制算法

1. 温度 → 占空比策略（占空比指 **GPIO40 实际 PWM%**）：
   - **VIN 存在**（默认 `VIN_PRESENT_DEFAULT=true`）：
     - `<35 °C`：关闭风扇（`FAN_EN=Low`）。
     - `35–45 °C`：固定 96%，并清空 PI 状态。
     - `>45 °C`：进入压温区，目标温度 45 °C，占空比允许范围 96%~0%，调节一直持续到温度回落至 `<35 °C` 再停转。
   - **VIN 缺失**：
     - `<40 °C`：关闭风扇。
     - `≥40 °C`：直接进入压温区（目标同样 45 °C），占空比范围保持 96%~0%。
   - PI 参数（`PI_KP`, `PI_KI`）可按硬件表现微调；保持 `96%` 为最小有效占空比。
2. 温度滞回：±3 °C（防抖）；占空比限斜率：每周期最大 ±5%（在“风量”域内运算，然后换算成实际占空比）。
3. 风扇开启流程：占空比从 0 → 非 0 时先 `FAN_EN=High` 再设置 PWM；关闭则维持 `GPIO40=100%` 同时 `FAN_EN=Low`，确保 LDO 输出完全关闭。
4. 保护逻辑：
   - TSENS 读数无效或超限 → 进入安全模式（默认 50% 占空比，`FAN_EN=High`）；
   - `Temp ≥ 80 °C` → 强制 100%，并记录一次“overheat”事件。

### 3.3 配置与扩展性

- 建议将阈值、占空比、滞回、限斜率、保护占空比等封装成 `const FAN_CONFIG` 结构，便于未来改成外部配置或运行时调节。

---

## 4. 日志与诊断

每 2 s 输出一次 `INFO` 日志，格式示例：

```
TEMP=42.3°C RAW=137 ATTR=2 DELTA=-10.3°C DUTY=35% MODE=NORMAL VOUT≈2.5V
```

字段说明：

- `RAW`：TSENS 原始值；
- `ATTR`：当前量程索引；
- `DELTA`：eFuse 校准值（°C）；
- `DUTY`：实际 PWM 占空比（`GPIO40`），风扇关闭时记为 `0`；
- `MODE`：`NORMAL` / `SAFE` / `OVERTEMP`；
- `VOUT`：根据线性模型推算的目标电压（用于调试，风扇关闭时输出 `0`）。

异常情况下追加 `WARN` 或 `ERROR`：

```
WARN fan.safe_mode reason=tsens_fault raw=0
ERROR fan.overheat temp=82.1°C forcing=100%
```

---

## 5. 验收测试

1. **校准验证**：室温 25–32 °C 时 TSENS 读数应与外部温度计差距 <10 °C；若 eFuse 缺失，应打印 `tsens.calib_missing` 并进入安全模式。
2. **线性调压**：在关机状态用示波器或万用表测量 `FAN_VCC`，验证占空比 0%/60%/100% 对应电压约 5 V/2.6 V/1.4 V（允许 ±0.2 V 浮动）。
3. **功能回归**：加热或模拟负载升温，观察占空比随温度递增；≥80 °C 时风扇全速。
4. **异常处理**：短暂禁用 TSENS、插拔风扇或模拟二极管短路，确认软件能进入安全模式并恢复。
5. **日志检查**：通过 `cat /dev/cu.usbmodemXXXX` 读取日志，确认字段齐全、节奏满足 2 s/条。

---

## 6. 未来扩展建议

- **闭环控制**：添加 PCNT 测 RPM，构建 PI 调节，兼容三线风扇。
- **外部传感器**：支持 I²C 温度传感器（如 TMP117）作补偿，减少芯温偏差。
- **自适应曲线**：在 EEPROM/Flash 中存储标定曲线，允许用户按环境和风扇型号调节。
- **健康监测**：记录累计运行时间、过温次数，提供预警接口。

---

## 7. 参考

- 原理图：`docs/assets/fan-speed-control-sch.png`
- 旧版三线方案参考：`docs/pwm_fan_control_circuit_design.md`
- 两线实现说明：`docs/active_cooling_2wire.md`
- 任务拆解：`docs/fan_control_requirements.md`
- ESP-IDF 文档：`temperature_sensor_hal`、`esp_efuse_rtc_calib`

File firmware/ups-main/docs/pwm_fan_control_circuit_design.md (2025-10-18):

# ESP32-S3 PWM Fan Control System Application Note

Based on TI standard feedback network design methodology and RT9043GB LDO

## Design Overview

This design uses ESP32-S3FH4R2 triple GPIO control scheme: PWM signal is converted to smooth DC control voltage through two-stage RC filter to regulate RT9043GB LDO output voltage (2V-5V), EN signal controls fan on/off, TACH signal provides speed feedback via PCNT, achieving precise closed-loop speed control for 5V 0.7A DC fans.

### Application Scenario

- **Target Fan**: 5V 0.7A DC fan
- **Speed Range**: 2V-5V (verified by actual testing)
- **Control Method**: PWM voltage regulation + EN on/off + TACH feedback
- **Component Specs**: 0402 package resistors and capacitors

### Core Advantages

- ✅ **Triple-pin Control**: PWM speed control + EN on/off + TACH feedback, closed-loop control
- ✅ **Test Verified**: Based on actual 5V 0.7A fan test data
- ✅ **Low Cost**: Total BOM < $3.50, 60% savings compared to DAC solution
- ✅ **Compact Design**: 0402 package, minimized PCB area
- ✅ **High Output Capability**: 400mA LDO, sufficient to drive 0.7A fan
- ✅ **Speed Feedback**: PCNT-based tachometer for real-time RPM monitoring

## Circuit Schematic

```text
VIN (12V) ──┬─── RT9043GB ──┬─── VOUT (2V-5V adjustable) ──┬─── Fan (+)
            │      LDO     │                              │
            │              ├─── C_OUT (10μF)              │
            │              │                              │
            C_IN (1μF)     │                              │
            │              │                              │
            GND            │                              │
                          │                              │
ESP32-S3 Triple Pin Control ┼─── Control Circuit          │
                          │                              │
GPIO1 (PWM) ──┬─ R1(2.2kΩ) ──┬─ C1(68nF) ──┬─ R2(2.2kΩ) ──┬─ C2(68nF) ──┬─ R_INJ(100kΩ) ──┬─ RT9043GB FB
25kHz, 12bit  │              │             │              │             │                 │
              │              │             │              │             │                 ├─ R_UPPER(47kΩ) ──┬─ VOUT
             GND            GND           GND            GND            │                 │                  │
                                                                        │                 │                  │
GPIO2 (EN) ────────────────────────────────────────────────────────────┼─────────────────┼─ RT9043GB EN     │
                                                                        │                 │                  │
                                                                       GND          R_LOWER(15kΩ)           │
                                                                                          │                  │
                                                                                         GND                 │
                                                                                                            │
Fan TACH ──┬─── R_PULLUP(4.7kΩ) ──┬─── VCC (3.3V)                                                         │
           │                      │                                                                        │
           ├─── C_FILTER(100pF) ───┼─── GND (optional noise filter)                                        │
           │                      │                                                                        │
           └─── GPIO6 (PCNT) ──────┘                                                                   Fan (-)
```

Note: Based on actual 5V 0.7A fan, speed range 2V-5V
Design method: Strictly follows TI standard feedback network design methodology
Default output 5V: VOUT = 1.2V × (1 + R_UPPER/R_LOWER) = 1.2V × (1 + 47k/15k) = 5.0V
PWM pull-down control: Inject low voltage through R_INJ(100kΩ) to pull down FB
Triple-pin control: PWM voltage regulation + EN on/off + TACH feedback (closed-loop)
TACH signal: Fan tachometer output with 4.7kΩ pull-up and optional 100pF noise filter
All resistors and capacitors use 0402 package

## Design Methodology

### Based on TI Standard Method

This design strictly follows Texas Instruments standard feedback network design methodology to ensure professionalism and reliability:

#### TI Standard Feedback Network Equation

```text
VOUT = VFB × (1 + R_UPPER/R_LOWER)
```

**Source**: TI TPS56C215 datasheet equation 6

**Application**: Applicable to all TI LDO and switching regulator feedback network design

#### Our Implementation (Using Common E24 Series Resistor Values)

- **VFB**: 1.2V (RT9043GB feedback reference voltage)
- **Target Output**: 5.0V
- **Calculation**: R_UPPER/R_LOWER = (5.0V/1.2V) - 1 = 3.167
- **Selection**: R_UPPER = 47kΩ, R_LOWER = 15kΩ (47k/15k = 3.133)
- **Verification**: VOUT = 1.2V × (1 + 47k/15k) = 1.2V × 4.133 = 4.96V
- **Error**: (4.96V - 5.0V)/5.0V = -0.8% (excellent accuracy)

#### TI Recommended Design Practices

1. **Resistor Value Range**: 10kΩ-20kΩ for pull-down resistor (we chose 15kΩ)
2. **Power Consideration**: Feedback current should be < 150μA (we achieved 80μA)
3. **Accuracy Requirement**: Use ±1% precision resistors to ensure output voltage accuracy
4. **Standard Resistor Values**: Use E24 series standard values (47kΩ, 15kΩ)
5. **Naming Convention**: Use R_UPPER/R_LOWER instead of R_UP/R_DOWN

## Key Design Parameters

### PWM Configuration

| Parameter | Value | Description |
|---|---|---|
| Frequency | 25kHz | Above audio range, easy to filter |
| Resolution | 12-bit | 4096 levels, 0.024% precision |
| Duty Range | 15%-85% | Optimized for 2V-5V range |
| GPIO Pin | GPIO1 | ESP32-S3 LEDC channel |
| TACH Pin | GPIO6 | ESP32-S3 PCNT input |

### Two-Stage RC Filter Design

#### First Stage Filter

- **R1**: 2.2kΩ ±1% 0402 thick film resistor
- **C1**: 68nF ±10% 0402 X7R ceramic capacitor

#### Second Stage Filter

- **R2**: 2.2kΩ ±1% 0402 thick film resistor
- **C2**: 68nF ±10% 0402 X7R ceramic capacitor

#### Filter Performance

- **Total Attenuation**: >40dB @ 25kHz
- **Cutoff Frequency**: fc = 1/(2π×RC) ≈ 1.06kHz
- **Phase Margin**: >60° ensuring stability

### Feedback Network Design

Based on TI Standard Method, E24 Series Standard Values:

- **R_UPPER**: 47kΩ ±1% 0402 (VOUT to FB pull-up resistor, E24 standard value)
- **R_LOWER**: 15kΩ ±1% 0402 (FB to GND pull-down resistor, E24 standard value)
- **R_INJECT**: 100kΩ ±1% 0402 (PWM injection resistor for pulling down FB voltage)

**Design Considerations (Based on TI Methodology)**:

- **TI Standard Ratio**: R_UPPER/R_LOWER = 47k/15k = 3.133, ensuring VOUT = 1.2V × 4.133 = 4.96V
- **Excellent Accuracy**: Output voltage error only -0.8%, meeting ±2% accuracy requirement
- **Low Power Design**: I_FB = 1.2V/15kΩ = 80μA, complying with TI recommended 10kΩ-20kΩ range
- **High Injection Impedance**: R_INJECT = 100kΩ >> R_PARALLEL = 11.4kΩ, avoiding excessive impact on default operating point
- **E24 Standard Values**: Both 47kΩ and 15kΩ are common E24 series standard values, easy to procure

## Bill of Materials

| Component | Specification | Quantity | Function | Notes |
|---|---|---|---|---|
| U1 | RT9043GB | 1 | Adjustable LDO | SOT-23-5 package |
| C_IN | 1μF/16V | 1 | Input filtering | 0402 X7R ceramic capacitor |
| C_OUT | 10μF/16V | 1 | Output filtering | 0603 X7R ceramic capacitor |
| R1, R2 | 2.2kΩ ±1% | 2 | RC filter | 0402 thick film resistor |
| C1, C2 | 68nF ±10% | 2 | RC filter | 0402 X7R ceramic capacitor |
| R_UPPER | 47kΩ ±1% | 1 | FB pull-up resistor | 0402 thick film resistor |
| R_LOWER | 15kΩ ±1% | 1 | FB pull-down resistor | 0402 thick film resistor |
| R_INJ | 100kΩ ±1% | 1 | PWM injection resistor | 0402 thick film resistor |
| R_PULLUP | 4.7kΩ ±1% | 1 | TACH pull-up resistor | 0402 thick film resistor |
| C_FILTER | 100pF ±10% | 1 | TACH noise filter | 0402 C0G ceramic capacitor |

**Total BOM Cost**: < $3.50 (quantities of 1000+)

## Software Implementation
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

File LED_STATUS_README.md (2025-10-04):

# [已更新] 多灯指示规范已迁移

本文件为“单灯”原型说明，已被新版四色 LED 与状态机规范取代。请参考：`firmware/smart-battery/SOFTWARE_DESIGN.md`。

# LED状态指示实现（旧版，仅存档）

## 概述

本项目实现了一个LED状态指示系统，使用PA5引脚连接的LED来显示系统的不同状态。LED配置为开漏输出，低使能。

## 硬件配置

- **引脚**: PA5
- **输出类型**: 开漏输出 (Open Drain)
- **使能方式**: 低使能 (Active Low)
- **初始状态**: 高电平 (LED关闭)

## LED状态模式

按优先级从高到低排列，同一时间只显示一个匹配的状态：

### 1. 故障状态 (最高优先级)
- **触发条件**: 
  - BQ76920检测到故障：过压(OV)、欠压(UV)、短路放电(SCD)、过流放电(OCD)
  - SC8815检测到故障：过温保护(OTP)、VBUS短路故障
- **LED模式**: 4Hz频率闪烁
- **时序**: 125ms亮，125ms灭，周期250ms

### 2. 充电状态
- **触发条件**: SC8815检测到AC适配器连接且无故障
- **LED模式**: 0.5Hz频率闪烁
- **时序**: 1000ms亮，1000ms灭，周期2000ms
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

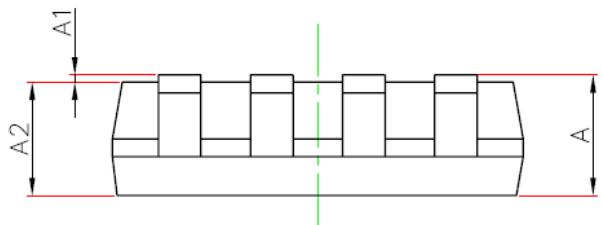
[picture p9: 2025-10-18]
firmware/ups-main/docs/datasheets/images/5212c720d46bb278d02540ddf4ae6ccb32c03c14ff973e478a7ec927ccae5cc4.jpg

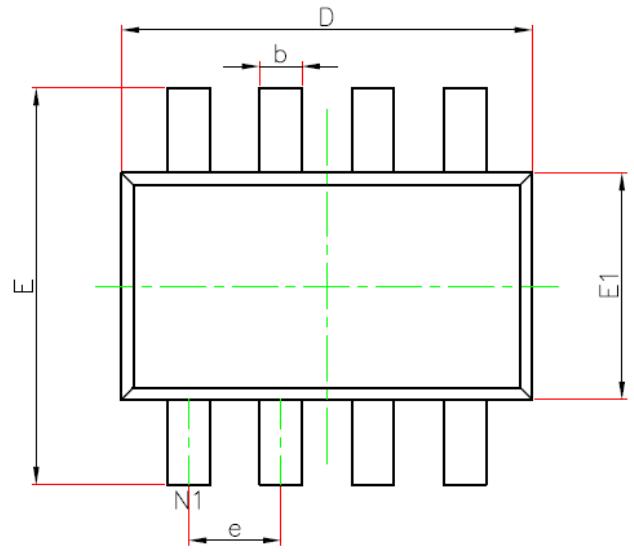
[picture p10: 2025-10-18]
firmware/ups-main/docs/datasheets/images/d84ccb257c5105b4caaf9de6392b76692e15167ea0d81de803a936b128c873bb.jpg

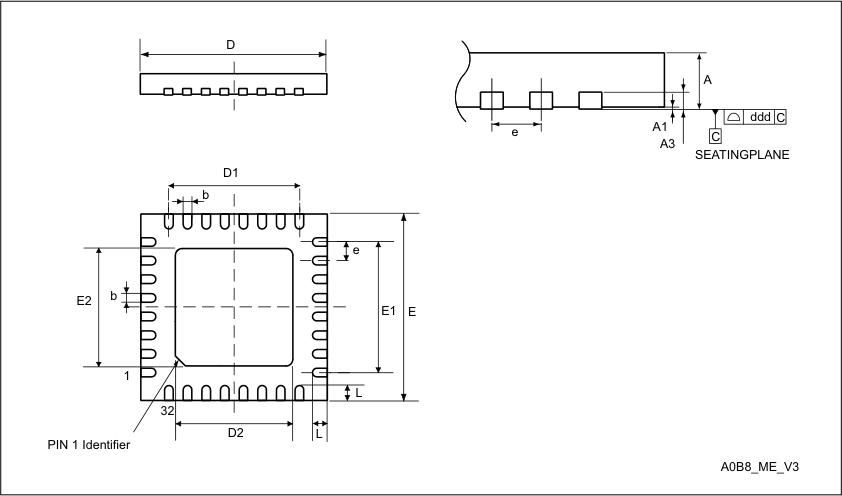
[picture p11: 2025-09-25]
docs/assets/stm32l051c8/stm32l051c8.pdf-119-0.png

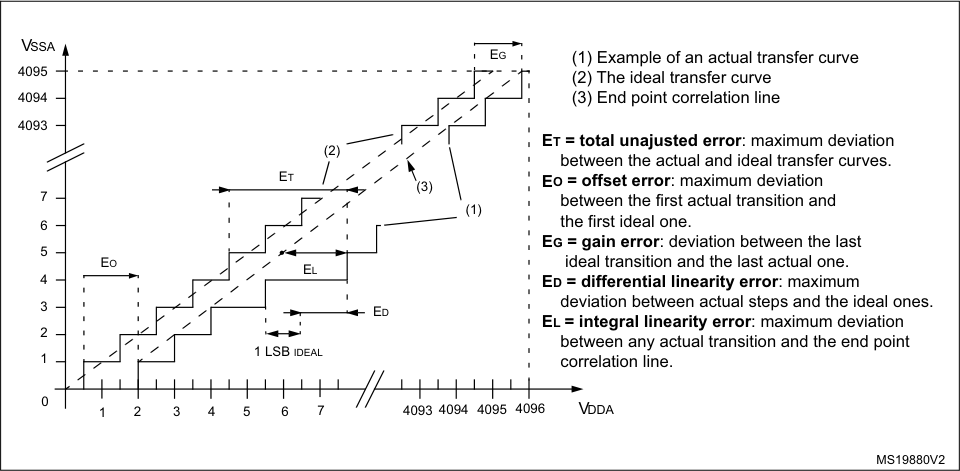
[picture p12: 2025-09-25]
docs/assets/stm32l051c8/stm32l051c8.pdf-86-0.png

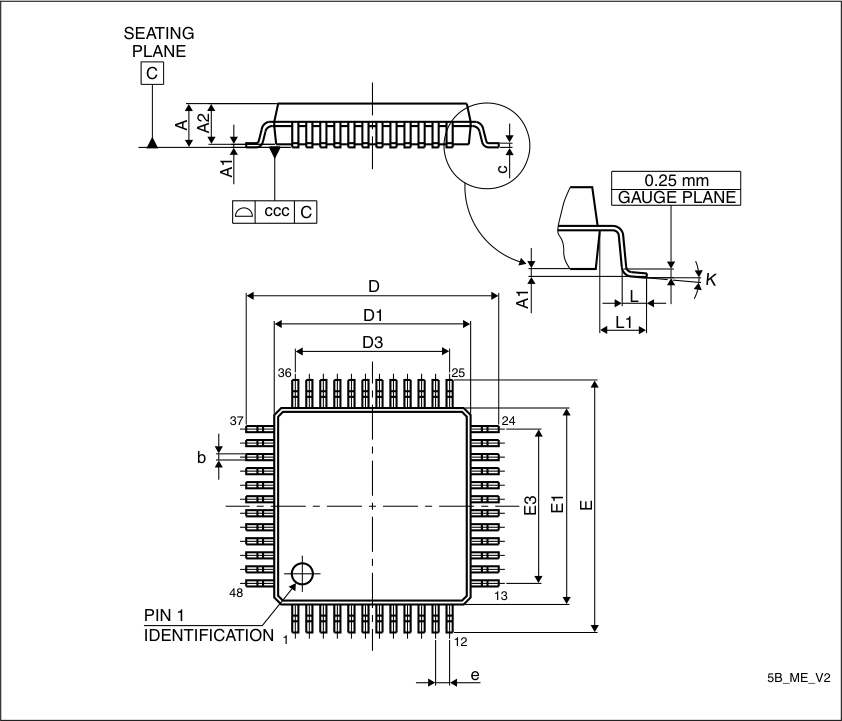
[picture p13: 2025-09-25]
docs/assets/stm32l051c8/stm32l051c8.pdf-106-0.png

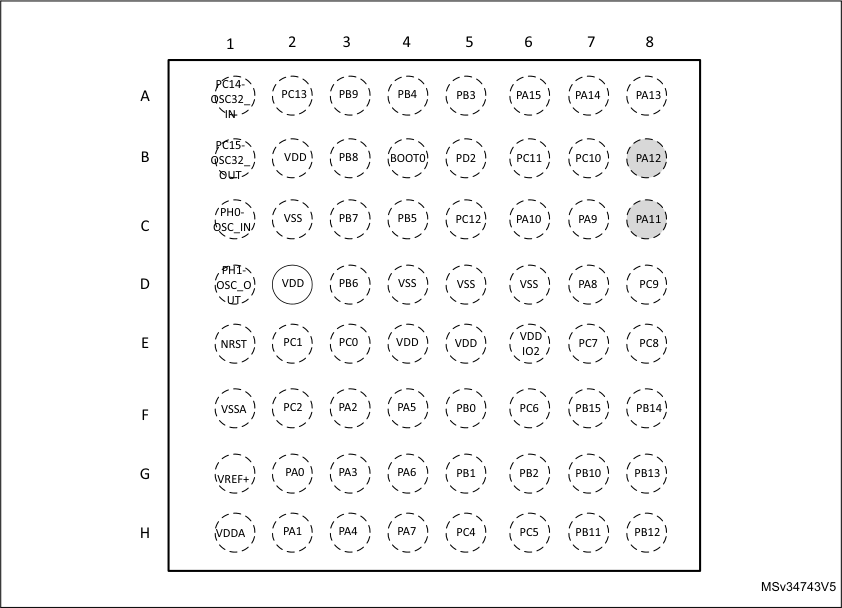
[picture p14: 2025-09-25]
docs/assets/stm32l051c8/stm32l051c8.pdf-33-0.png

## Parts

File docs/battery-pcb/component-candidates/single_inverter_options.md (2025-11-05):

# 单路施密特触发反相器选型

## 需求概述

- 硬件保护链要求将 `TEMP_ALERT_N`、`WD_RST_N` 等 3.3 V 信号组合得到“异常=高”的推挽输出，并在故障时驱动 `BQ76920 ALERT` 与停机链路，逻辑级需具备施密特迟滞以可靠处理缓慢边沿与开漏释放[^hp-chain]。
- 本记录补充单路反相器的选型，覆盖与 `TEMP_ALERT_N` 等低有效信号相关的极性转换，并保持 3.3 V 供电兼容、推挽输出与低静态功耗。

## 候选器件概览

| 型号 | 封装 | 输入类型 | 价格 (RMB/片) | 购买链接 |
| --- | --- | --- | --- | --- |
| UMW SN74LVC1G14DBVR | SOT-23-5 | 施密特触发 | [¥0.14](https://item.taobao.com/item.htm?id=672674224651) | [链接](https://item.taobao.com/item.htm?id=672674224651) |
| Nexperia 74LVC1G14GW,125 | SOT-353 | 施密特触发 | [¥0.26](https://item.taobao.com/item.htm?id=695968450355) | [链接](https://item.taobao.com/item.htm?id=695968450355) |
| TI SN74LVC1G04DCKR | SC-70-5 | 标准 CMOS | [¥0.13](https://item.taobao.com/item.htm?id=731779366159) | [链接](https://item.taobao.com/item.htm?id=731779366159) |
| Nexperia 74LVC1G04GW,125 | SOT-353 | 标准 CMOS | [¥0.17](https://item.taobao.com/item.htm?id=695601151155) | [链接](https://item.taobao.com/item.htm?id=695601151155) |

## 器件关键参数

| 指标 | SN74LVC1G14（施密特） | SN74LVC1G04（标准） |
| --- | --- | --- |
| 工作电压 | 1.65 V – 5.5 V[^ti-lvc1g14] | 1.65 V – 5.5 V |
| 输入类型 | 施密特触发，允许慢边沿 | CMOS，无迟滞 |
| 输出类型 | 推挽，I<sub>OH</sub>/I<sub>OL</sub> ≈ ±32 mA | 推挽，I<sub>OH</sub>/I<sub>OL</sub> ≈ ±32 mA |
| 静态电流 | ≤10 µA | ≤10 µA |
| 封装选项 | DBV (SOT-23-5)、DCK (SC-70-5)、GW (SOT-353)、DRL (SOT-553) | 相同封装系列 |

## 适配性评估

- **信号完整性**：施密特输入可直接读取 `TEMP_ALERT_N` 的上拉/释放过程，避免传统 CMOS 反相器对缓慢边沿产生多次翻转问题，满足硬件保护链对噪声裕度的要求。
- **驱动能力**：±32 mA 输出足以拉动 `ALERT` 总线和 `PSTOP_CTL` 分支，且对 500 kΩ~1 MΩ 下拉具备充裕余量，与文档中对 NAND 的驱动要求一致。
- **供电与极性**：与 3.3 V 轨兼容，可用于硬件链路中“低有效 → 高有效”转换的节点，无需额外电平转换。
- **封装兼容**：DBV 封装与当前板子上使用的 LVC/LVC2G 系列引脚排列相近，改板成本低；若后续要在密度更高区域放置，可考虑 GW/DRL 微型封装，但需重新规划焊盘和工艺能力。
- **供应风控**：部分链接标注品牌为 UMW，采购时应确认是否为 TI/Nexperia 原厂封装或同规格国产替代；如需确保原厂，可转向明确标注 TI/Nexperia 的同系列链接。

## 建议与后续动作

- 优先下单 **SN74LVC1G14DBVR**（SOT-23-5），与现有焊盘兼容，单价与 NAND 备件相当，可快速验证硬件链路。
- 若需要缩小封装或分摊功耗，可同步采购 74LVC1G14GW（SOT-353）样品，在后续 PCB 修订中评估焊接与测试可行性。
- 收货后建议抽检丝印与功能，确认施密特迟滞与输出驱动符合数据手册，再纳入正式 BOM。

---

[^hp-chain]: `docs/battery-pcb/hardware_protection_tps3823_tmp75.md` 中对硬件故障链路的电平、极性以及施密特迟滞需求描述。
[^ti-lvc1g14]: Texas Instruments, *SN74LVC1G14 Single Schmitt-Trigger Inverter* 产品页面。

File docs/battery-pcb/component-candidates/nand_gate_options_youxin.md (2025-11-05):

# NAND 与非门器件评估

使用关键词“与非门”对指定渠道的 48 个结果进行筛选，并结合数据手册核对关键电气参数，整理出可满足《hardware_protection_tps3823_tmp75.md》硬件保护链需求的单路与双路 NAND（与非）器件。

## 1. 单路 2 输入 NAND

| 型号 | 逻辑族 | 输入特性 | V<sub>CC</sub> (V) | 输出能力 | 封装示例 | 渠道单价 (CNY) | 适配要点 |
| --- | --- | --- | --- | --- | --- | --- | --- |
| SN74AHC1G00DBV[^price-ahc1g00] | AHC | **施密特触发**，容忍慢沿 | 2.0–5.5[^ti-ahc1g00] | 推挽，±8 mA @ 5 V[^ti-ahc1g00] | SOT-23-5、SC-70-5 | 0.25 | 放置在 `FAULT_LATCH` 前级抑制温度告警慢上升沿。 |
| SN74AUP1G00DPW[^price-aup1g00] | AUP | 典型 250 mV 迟滞，3.6 V 容限 | 0.8–3.6[^ti-aup1g00] | 推挽，±4 mA @ 3.3 V[^ti-aup1g00] | X2SON-5、SOT-353 | 0.49 | 提供低功耗与迟滞，可直接驱动 `PSTOP_CTL`。 |
| SN74LVC1G00DBVR[^price-lvc1g00] | LVC | 标准 CMOS 阈值（**无施密特**） | 1.65–5.5[^ti-lvc1g00] | 推挽，±24 mA @ 3.3 V[^ti-lvc1g00] | SOT-23-5、SC-70-5 | 1.76 | 适合作为整形后的末级反相或 `ALERT` 推挽输出。 |

## 2. 双路 2 输入 NAND

| 型号 | 逻辑族 | 输入特性 | V<sub>CC</sub> (V) | 输出能力 | 封装示例 | 渠道单价 (CNY) | 适配要点 |
| --- | --- | --- | --- | --- | --- | --- | --- |
| SN74LVC2G132DCUR[^price-lvc2g132] | LVC | **双通道施密特触发** | 1.65–5.5[^ti-lvc2g132] | 推挽，±24 mA @ 3.3 V[^ti-lvc2g132] | VSSOP-8、X2SON-8 | 0.91 | 单颗器件覆盖 `FAULT_LATCH` 与 `STOP_REQUEST`，提供噪声裕量。 |
| SN74LVC2G00DCUR[^price-lvc2g00] | LVC | 标准 CMOS 阈值 | 1.65–5.5[^ti-lvc2g00] | 推挽，±24 mA @ 3.3 V[^ti-lvc2g00] | VSSOP-8、US8 | 1.42 | 适用于前级已整形的场景，提供更高驱动或占位替换。 |

## 3. 与硬件保护链的适配建议
- **前级故障合成**：`SN74LVC2G132` 与 `SN74AHC1G00` 均具施密特输入，可按《hardware_protection_tps3823_tmp75.md》第 3 章拓扑整合 `WD_RST_N`、`TEMP_ALERT_N`、`PSTOP_MCU`，抑制慢沿与抖动。[^ti-lvc2g132][^ti-ahc1g00][^hardware-doc]
- **末级翻转/缓冲**：`SN74AUP1G00` 在 3.3 V 下兼具迟滞与低静态功耗，适合直接驱动 `PSTOP_CTL` 或 `ALERT`。若需要更大灌/拉电流，可在整形节点使用 `SN74LVC1G00` 或 `SN74LVC2G00` 替换。[^ti-aup1g00][^ti-lvc1g00][^ti-lvc2g00]
- **版图兼容性**：上述器件覆盖 SOT-23-5、SC-70-5、SOT-353、VSSOP-8 等封装，与现有 PCB 工艺兼容，可无缝替换现有单/双路 LVC 器件。

## 4. 后续动作
- 采购 `SN74LVC2G132DCUR` 与 `SN74AUP1G00DPW` 样品，验证施密特整形及低功耗末级在硬件链路中的噪声余量。
- 若验证显示仍需更高驱动，在末级切换至 `SN74LVC1G00` / `SN74LVC2G00` 并更新《hardware_protection_tps3823_tmp75.md》的逻辑实现。

---

[^price-ahc1g00]: 渠道页面商品 ID 704713346062，访问日期 2025-01-30，促销单价 0.25 CNY。
[^price-aup1g00]: 渠道页面商品 ID 696330677234，访问日期 2025-01-30，促销单价 0.49 CNY。
[^price-lvc1g00]: 渠道页面商品 ID 672658816379，访问日期 2025-01-30，促销单价 1.76 CNY。
[^price-lvc2g132]: 渠道页面商品 ID 714861431492，访问日期 2025-01-30，促销单价 0.91 CNY。
[^price-lvc2g00]: 渠道页面商品 ID 714651342193，访问日期 2025-01-30，促销单价 1.42 CNY。
[^ti-ahc1g00]: Texas Instruments, *SN74AHC1G00 Single 2-Input Positive-NAND Gate*, SCLS313Q, Jan. 2024.
[^ti-aup1g00]: Texas Instruments, *SN74AUP1G00 Low-Power Single 2-Input Positive-NAND Gate*, SCES604J, Dec. 2016.
[^ti-lvc1g00]: Texas Instruments, *SN74LVC1G00 Single 2-Input Positive-NAND Gate*, SCES212AB, Apr. 2014.
[^ti-lvc2g132]: Texas Instruments, *SN74LVC2G132 Dual 2-Input NAND Gate With Schmitt-Trigger Inputs*, SCES547D, Dec. 2013.
[^ti-lvc2g00]: Texas Instruments, *SN74LVC2G00 Dual 2-Input Positive-NAND Gate*, SCES193N, Jan. 2015.
[^hardware-doc]: 《hardware_protection_tps3823_tmp75.md》，第 3 章“逻辑实现”。

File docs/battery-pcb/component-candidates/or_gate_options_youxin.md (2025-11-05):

# 单路或门器件总结

> 目的：在 `hardware_protection_tps3823_tmp75.md` 所述保护链中，为 `FAULT_LATCH` / `ALERT_BUS` 等“异常=高”路径提供单路 2 输入或门，当仅需 OR 组合（例如把两个开漏告警转正）时避免双门器件浪费；整理基于 `schmitt_trigger_nand_options.md` 的选型思路，对常见现货型号进行记录与适配性评估。

## 1. 可选清单

| 型号 / 参考编号 | 逻辑族 | 供电范围 | 静态功耗 | 输出能力 | 封装 | 参考单价 (人民币) | 适配性摘要 |
| --- | --- | --- | --- | --- | --- | --- | --- |
| 74LVC1G32GV,125（ID 696756982789） | TI/Nexperia · LVC CMOS | 1.65–5.5 V[^ti-lvc] | 常规 CMOS | 推挽，32 mA 驱动[^ti-lvc] | SOT-753 (TSSOP-5) | [¥0.27](https://item.taobao.com/item.htm?id=696756982789) | 输出电流裕量大，适合 ALERT 总线外接大阻下拉场景 |
| 74AUP1G32GW,125（ID 695609498883） | Nexperia · AUP CMOS | 0.8–3.6 V[^ti-aup] | <1 µA 静态[^ti-aup] | 推挽，≤±4 mA | SOT-353 (SC-70-5) | [¥0.52](https://item.taobao.com/item.htm?id=695609498883) | 低功耗，封装与 `SN74LVC2G132` 单门焊盘尺寸接近 |
| 74AUP1G32GW-Q100H（ID 695037904952） | Nexperia · AUP CMOS（AEC-Q100） | 0.8–3.6 V[^ti-aup] | <1 µA | 推挽，≤±4 mA | SOT-353 | [¥0.57](https://item.taobao.com/item.htm?id=695037904952) | 车规版本，参数与标准版一致，适合需要认证的场合 |

## 2. 电气适配要点

- `WD_RST_N` / `TEMP_ALERT_N` 等信号位于 3.3 V 轨，74LVC1G32 允许 1.65–5.5 V 供电并提供 32 mA 推挽驱动，足以克服 `BQ76920 ALERT` 推荐的 500 kΩ~1 MΩ 下拉，并可直接驱动板载 MOS 反向链路[^ti-lvc]。
- 74AUP1G32 系列支持 0.8–3.6 V 供电，静态电流 <1 µA，输入具施密特迟滞，适合电池待机功耗敏感场景；其推挽输出版可稳定驱动 ALERT 总线和 `PSTOP_CTL` 的 CMOS 负载[^ti-aup]。
- 三个型号均为 SOT‑23/SOT‑353 小封装，焊盘与现有 `SN74LVC2G132` 单门位兼容；AUP 系列体积更小，贴装前需确认产线治具裕量。

## 3. 选型建议

1. 需兼顾功耗与现有板级设计时，优先选择 **74AUP1G32GW,125**：静态电流最低，且和 `schmitt_trigger_nand_options.md` 中推荐的 AUP 族保持一致。
2. 若 ALERT 总线或下游断路器需要更高驱动余量，可选 **74LVC1G32GV,125**，在 3.3 V 供电下提供 ≥32 mA 输出。
3. 对应 AEC-Q100 认证需求时，可采用 **74AUP1G32GW-Q100H**，其电气参数与标准版一致，便于无差异 BOM 切换。

---

[^ti-lvc]: Texas Instruments, *SN74LVC1G32 data sheet*, 特性概述 “1.65-V to 5.5-V 32-mA drive strength OR gate”。
[^ti-aup]: Texas Instruments, *SN74AUP1G32 data sheet*, 特性概述 “Single, 2-input 0.8-V to 3.6-V low-power (< 1uA) OR gate”。

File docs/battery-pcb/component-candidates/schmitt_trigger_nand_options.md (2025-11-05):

# 单路施密特触发与非门器件总结

旨在为 `hardware_protection_tps3823_tmp75.md` 中的硬件保护链挑选合适的单路施密特触发 NAND，使 `WD_RST_N`、`TEMP_ALERT_N` 等信号能够直接整合为“异常=高”的组合逻辑，同时驱动 `BQ76920 ALERT` 与 `PSTOP_CTL`。

## 1. 关键参数对比

| 型号 / 链接 | 单价（CNY） | 逻辑族 | 输入属性 | V<sub>CC</sub> 范围 | 输出级 | I<sub>CC</sub> (max) | t<sub>pd</sub> @3.3 V (典型/最大) | 封装 | 备注 |
| --- | --- | --- | --- | --- | --- | --- | --- | --- | --- |
| [SN74AHC1G00DBVR](https://item.taobao.com/item.htm?id=673364782576) / [DCKR](https://item.taobao.com/item.htm?id=704713346062) | ¥1.95（DBVR）、¥0.25（DCKR） | AHC, CMOS | 全输入施密特触发；阈值≈0.3/0.7·V<sub>CC</sub> | 2.0–5.5 V，输入不得超过 V<sub>CC</sub> | 推挽，±8 mA @5 V，≈±4 mA @3.3 V | 10 µA | 4.0 ns / 7.1 ns[^ti-ahc1g00] | SOT‑23‑5、SC‑70‑5 | 满足 3.3 V 逻辑、驱动充足；功耗较高 |
| [74AUP1G00GW,125](https://item.taobao.com/item.htm?id=696330677234) | ¥0.49 | AUP, CMOS | 全输入施密特触发；支持缓慢边沿 | 0.8–3.6 V；输入容许 3.6 V | 推挽，±4 mA @3.3 V | 0.9 µA | 3.2 ns / 4.8 ns[^nxp-74aup1g00] | SOT‑353 (TSSOP5) | 低功耗、阈值与电源兼容；输出电流满足 ALERT/PSTOP 控制 |
| [74AUP1G00GX,125](https://item.taobao.com/item.htm?id=696835563731) | ¥0.49 | AUP, CMOS | 同上 | 0.8–3.6 V；输入容许 3.6 V | 推挽，±4 mA @3.3 V | 0.9 µA | 3.2 ns / 4.8 ns[^nxp-74aup1g00] | X2SON‑5 (SOT886) | 与 GW 版电气一致，体积更小；焊接要求更高 |
| [SN74AUP1G00DBVR](https://item.taobao.com/item.htm?id=696330677234) | ¥0.49（同上链接） | AUP, CMOS | 输入带 250 mV 典型迟滞 | 0.8–3.6 V；输入容许 3.6 V | 推挽，±4 mA @3.3 V | 1 µA | 3.3 ns / 4.9 ns[^ti-aup1g00] | SOT‑23‑5 | 与现有 SOT‑23 足迹兼容，低功耗 |
| [SN74AUP1G00DCKR](https://item.taobao.com/item.htm?id=705201135652) | ¥0.96 | AUP, CMOS | 输入带 250 mV 典型迟滞 | 0.8–3.6 V；输入容许 3.6 V | 推挽，±4 mA @3.3 V | 1 µA | 3.3 ns / 4.9 ns[^ti-aup1g00] | SC‑70‑5 | 与 AUP 系列兼容；SC‑70 封装节省面积 |
| SN74LVC1G38DBVR | —（店内未上架） | LVC, CMOS，开漏输出 | **开漏 NAND**，非施密特输入 | 1.65–5.5 V；输入容许 5.5 V | 开漏，需外部上拉 | 10 µA | 4.5 ns / 7.5 ns[^ti-lvc1g38] | SOT‑23‑5、SC‑70‑5 | **不推荐**：输出为开漏且输入无施密特迟滞 |

> 价格信息更新于 2025-10-31，来源：[深圳优信电子](https://youxindianzi.taobao.com/)（chrome-devtools 抓取）。

> 说明：SN74AHCT1G00、SN74LVC1G00 等型号虽为单路 NAND，但仅提供 TTL/标准 CMOS 阈值，不含施密特触发，故未列入。

## 2. 项目适用性分析

1. **供电与阈值**  
   智能电池板上相关信号（`WD_RST_N`、`TEMP_ALERT_N`、`PSTOP_MCU` 等）均在 3.3 V 轨工作，并可能出现缓慢边沿。AUP、AHC 两个族在 3.3 V 下提供 ≥250 mV 的输入迟滞，能有效抑制慢速或带噪声的告警线抖动。

2. **驱动能力**  
   - `FAULT_LATCH`、`PSTOP_CTL` 需要推挽输出以直接驱动下游 MOS 管与 BQ76920 的 ALERT 强制输入。AUP/ AHC 器件提供 ±4 mA（AUP）至 ±8 mA（AHC）驱动，在 3.3 V 下足够克服 BQ76920 推荐的 500 kΩ~1 MΩ 下拉。  
   - 开漏版本（SN74LVC1G38）虽可外接上拉，但在 ALERT BUS 需要快速释放时会引入额外延迟，因此淘汰。

3. **功耗权衡**  
   看门狗与温度告警常驻高电平，器件静态功耗会长期体现。AUP1G00（TI 或 Nexperia）I<sub>CC</sub> ≤1 µA，适合电池应用；AHC1G00 静态 10 µA，可接受但不如 AUP。

4. **封装与焊接**  
   - 若 PCB 采用 SOT‑23 足迹，可考虑 AHC1G00DBVR、AUP1G00DBVR/DCKR 等封装。  
   - 若需节省空间，可选 SOT‑353 或 X2SON，但需重新评估装配能力。

5. **逻辑族差异（CMOS vs. TTL）**  
   所列器件全部属于 CMOS 工艺（AHC、AUP 系列），内部使用施密特触发，阈值自适应 V<sub>CC</sub>；AHCT 系列虽为 TTL 兼容输入，但数据手册未赋予施密特性质，因此不满足需求。

## 3. 推荐方案

- **首选：SN74AUP1G00DCKR（TI）或 74AUP1G00GW,125（Nexperia）**  
  低功耗、全输入施密特触发、推挽输出且与 3.3 V 轨兼容；封装与现有 LVC/LVC2G 封装接近，替换改板成本最低。

- **备选：SN74AHC1G00DBVR**  
  当更高输出驱动或 5 V 逻辑兼容性成为必须时可选，但需注意静态功耗增加且输入端不得超过供电电压。

上述结论与 `hardware_protection_tps3823_tmp75.md` 中的信号拓扑相一致，选型时按表中参数选择合适器件即可保持 ALERT/PSTOP 的极性与时序设计目标。

---

[^ti-ahc1g00]: Texas Instruments, *SN74AHC1G00 Single 2-Input Positive-NAND Gate*, SCLS313Q, 2024-01. Features 列表注明 “Schmitt trigger action at all inputs”；表 5-6 提供 t<sub>pd</sub> 及输出电流规格。  
[^nxp-74aup1g00]: Nexperia, *74AUP1G00 Low-power 2-input NAND gate*, Rev.10, 2024-09-19. Section 1 描述施密特触发输入，表 7/8 给出 V<sub>CC</sub> 范围与时序。  
[^ti-aup1g00]: Texas Instruments, *SN74AUP1G00 Low-Power Single 2-Input Positive-NAND Gate*, SCES604J, 2016-12. Features 列出 “Input hysteresis allows slow input transition”，表 7-6 给出时序/驱动能力。  
[^ti-lvc1g38]: Texas Instruments, *SN74LVC1G38 Single 2-Input NAND Gate with Open-Drain Output*, SCES538G, 2020-02. 数据手册说明输出为开漏，输入不具备施密特迟滞。

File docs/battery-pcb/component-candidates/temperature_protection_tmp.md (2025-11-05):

# 温度保护临时方案草稿

*最后更新：2025-10-30*

## 0. 型号汇总对比

| 型号 | 功能定位 | 主要特性 | 输出形式 | 推荐用途 |
| --- | --- | --- | --- | --- |
| TMP390 (TI) | 双阈值温控开关 | Channel A 过温 + Channel B 欠温，Resistor 可编程，0.5 µA 典型静流 | 开漏 x2 | 纯硬件充放电锁断，MCU 失效时仍保护 |
| TMP303 (TI) | 固定窗口温控开关 | 预设窗口（-20~60 °C 等），引脚设置滞回，推挽输出 | 推挽 | TMP390 缺货时的窗口备选/冗余 |
| TMP75 (TI) | 数字温度传感器 | I²C/SMBus，12-bit 分辨率，ALERT 支持上下限比较 | I²C + 开漏 ALERT | MCU 采集温度、软件限流、日志记录（最终采用 VSSOP-8：TMP75AIDGKR） |

> 数据手册： [TMP390](https://www.ti.com/lit/ds/symlink/tmp390.pdf) · [TMP303](https://www.ti.com/lit/ds/symlink/tmp303.pdf) · [TMP75](https://www.ti.com/lit/ds/symlink/tmp75.pdf)

## 1. 设计背景与策略

- 充电安全窗口：0 °C ~ 45 °C（超出立即停充），>55 °C 需切断全部功率路径。
- 保护原则：**硬件优先**，软件只做冗余；MCU / I²C 故障时，仍由模拟开关保证安全。
- 传感器布局：TMP390 与 TMP75 靠近电芯；大面积铜箔+过孔提升热耦合，走线尽量短并增加 TVS 保护。

## 2. TMP390 – 主动硬件窗口比较

- **数据手册**：[TMP390 Datasheet](https://www.ti.com/lit/ds/symlink/tmp390.pdf)
- **工作机制**：Channel A 负责过温；Channel B 负责低温。SETA/SETB 与地连接 E96 精度电阻即可设定阈值与滞回。
- **建议阈值**：
  - Channel A：+55 °C，滞回 10 °C（复位 +45 °C）。
  - Channel B：−5 °C，滞回 5 °C（复位 0 °C）。
  - 参考《TMP390 数据手册》表 7-1、7-2 选择电阻。
- **外围设计**：
  - 两路开漏均上拉至 3.3 V，并分别驱动“充电允许”和“系统主断”锁存；建议加入 SR latch，需要人工/MCU 消警后才能恢复。
  - 预留测试点与软硬件旁路跳线，便于调试。
- **输出电平**：OUTA/OUTB 为开漏结构，低电平时灌电流至地，高电平需外部上拉；推荐上拉至 3.3 V，最大灌电流 6 mA（详见数据手册 7.3）。
- **输出真值表**（示例设定：`THIGH`=55 °C，`TLOW`=−5 °C）：

| 温度区间 | OUTA（过温） | OUTB（欠温） | 状态描述 |
| --- | --- | --- | --- |
| `T > THIGH` | 0（主动拉低） | High-Z → 上拉为高 | 过温触发，欠温释放 |
| `TLOW ≤ T ≤ THIGH` | High-Z → 上拉为高 | High-Z → 上拉为高 | 正常工作区间 |
| `T < TLOW` | High-Z → 上拉为高 | 0（主动拉低） | 欠温触发，过温释放 |
- **采购信息（淘宝 2025-10-30 抓取）**：

| 店铺 | 地区 | 规格 | 单价 (¥) | 运费 (¥) | 购买链接 |
| --- | --- | --- | --- | --- | --- |
| 淼鑫电子科技 | 广东深圳 | TMP390A2DRLR，SOT-563 | 1.20 | 2.00 | [商品链接](https://item.taobao.com/item.htm?id=920529133680) |
| 深圳市鑫丰泰盛电子 | 广东深圳 | TMP390A2DRLR，SOT-563 | 1.77 | 2.00 | [商品链接](https://item.taobao.com/item.htm?id=967849979744) |
| 集成芯片芯城科技 | 广东深圳 | TMP390AQDRLRQ1，SOT-563 | 2.21 | 5.00 | [商品链接](https://item.taobao.com/item.htm?id=969142489126) |

> **风险提示**：淘宝价格波动大，发货批次需与卖家确认；量产建议切换至 TI 授权分销（得捷、贸泽、立创等）。

## 3. TMP303 – 固定窗口备选

- **数据手册**：[TMP303 Datasheet](https://www.ti.com/lit/ds/symlink/tmp303.pdf)
- **定位**：当 TMP390 交期紧张时作为硬件冗余；推挽输出，可直接控制 MOS 或与 TMP390 输出“或”逻辑。
- **局限**：窗口固定（如 TMP303F：0~80 °C），无法覆盖 −5 °C 低温需求；建议 PCB 上只保留 footprint 作为应急方案。
- **输出电平**：`OUT` 为推挽 CMOS 结构，逻辑高接近 VDD（1.8 V~5.5 V），逻辑低拉至地；最大灌/拉电流 20 mA，适合直接驱动逻辑或 MOS Gate。
- **输出真值表**（以 TMP303BDRLR：`TLOW`=0 °C、`THIGH`=60 °C 为例）：

| 温度区间 | OUT 电平 | 状态描述 |
| --- | --- | --- |
| `T > THIGH` | 0 | 高温超出窗口，报警为低 |
| `TLOW ≤ T ≤ THIGH` | 1 (≈VDD) | 位于安全窗口，允许运行 |
| `T < TLOW` | 0 | 低温超出窗口，报警为低 |
- **采购信息（销量低，谨慎验证）**：

| 店铺 | 地区 | 规格 | 单价 (¥) | 运费 (¥) | 购买链接 |
| --- | --- | --- | --- | --- | --- |
| 深圳市成昊嘉业电子 | 广东深圳 | TMP303BDRLR，SOT-563 | 3.50 | 6.00 | [商品链接](https://item.taobao.com/item.htm?id=989836581801) |
| 诺腾泰电子 BOCAN 原装芯片 | 广东深圳 | TMP303BDRLR，SOT-563 | 3.48 | 5.00 | [商品链接](https://item.taobao.com/item.htm?id=990463568373) |
| 原装正品元器件供应商 | 广东深圳 | TMP303EDRLR，SOT-563 | 6.06 | 5.00 | [商品链接](https://item.taobao.com/item.htm?id=841629067955) |

> **核验建议**：要求卖家提供实拍、外包装标签及可开票能力；样品收到后用热箱验证窗口与滞回是否与数据手册一致。

## 4. TMP75 – MCU 温度采集与软件保护

- **数据手册**：[TMP75 Datasheet](https://www.ti.com/lit/ds/symlink/tmp75.pdf)
- **角色**：I²C 温度传感器，ALERT 引脚可配置为窗口比较（TM=0, TLOW/THIGH 寄存器），供 MCU 做渐进降额或日志。
- **软件策略**：
  - 上电后立即写入 `TLOW=0 °C`、`THIGH=45 °C`，配合 Fault Queue=1，实现单次越限报警。
  - 将 ALERT 拉至 MCU 中断脚；软件读取温度后清除中断，必要时冻结充电。
- **输出电平**：`ALERT` 为开漏输出，低电平灌电流至地，正常状态需外部上拉（推荐至 3.3 V）；I²C SDA/SCL 亦为开漏，统一使用同一上拉网络。
- **输出真值表**（Fault Queue=1，`THIGH`=45 °C，`TLOW`=0 °C）：

| 条件 | ALERT 电平 | 状态描述 |
| --- | --- | --- |
| `TLOW ≤ T ≤ THIGH` | High-Z → 上拉为高 | 温度在窗口内，报警释放 |
| `T > THIGH` 或 `T < TLOW` | 0 | 超出阈值，报警拉低 |
| MCU 读取 `TA` 并写 1 清除，且温度已回到窗口 | High-Z → 上拉为高 | 报警清除后恢复高电平 |
- **采购信息（销量较高，可先从淘宝采样）**：

| 店铺 | 地区 | 规格 | 单价 (¥) | 运费 (¥) | 购买链接 |
| --- | --- | --- | --- | --- | --- |
| 深圳市远大芯程科技 | 广东深圳 | TMP75AIDR，SOIC-8 | 0.51 | 1.00 | [商品链接](https://item.taobao.com/item.htm?id=747811426861) |
| 深圳市恒芯科创电子 | 广东深圳 | TMP75AIDR，SOIC-8 | 0.61 | 1.00 | [商品链接](https://item.taobao.com/item.htm?id=747095901223) |
| 深圳市捷洲电子科技 | 广东深圳 | TMP75AIDR，SOIC-8 | 0.53 | 1.00 | [商品链接](https://item.taobao.com/item.htm?id=710098374400) |
| 深圳优信电子 | 广东深圳 | TMP75AIDGKR，VSSOP-8 | 0.90 | 1.50 | [商品链接](https://item.taobao.com/item.htm?id=743114849741) |
| 深圳市恒芯科创电子 | 广东深圳 | TMP75AIDGKR，VSSOP-8 | 1.20 | 1.00 | [商品链接](https://item.taobao.com/item.htm?id=747270839048) |

> 批量供货优先考虑立创/得捷等授权渠道；淘宝样品可用于验证封装和温控逻辑。

- **最终选型**：标准配置锁定 `TMP75AIDGKR`（VSSOP-8），紧凑封装便于贴装在电芯侧，SOIC-8 型号保留作验证及备货冗余。

## 5. 开发与验证计划

1. **电路实现**：
   - 在 `pcb/battery-board` 中加入 TMP390/TMP75，输出接入 MOS 锁断与 MCU；TMP303 footprint 以焊盘形式预留。
   - 设置电阻网络和跳线，方便切换不同阈值、断言逻辑。
2. **热箱测试**：
   - 场景：-10 °C、0 °C、45 °C、55 °C、60 °C；记录 TMP390/TMP75 响应时间和温差。
   - 验证 ALERT 清除逻辑、防误触发。
3. **固件配合**：
   - I²C 驱动增加 TMP75 初始化、ALERT 中断服务。
   - 当硬件锁断触发时记录事件并向上位机输出。
4. **采购与备料**：
   - 淘宝样品确认 OK 后，整理正式 BOM，切换至授权渠道并锁定批次要求。

---

> 说明：本文档为临时设计笔记，仅用于硬件保护方案研讨；后续验证完成后请合并入正式《Battery Safety Protection》设计文档。

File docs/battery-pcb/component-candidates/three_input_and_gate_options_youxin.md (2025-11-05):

# 三输入与门器件总结

> 目的：为 `hardware_protection_tps3823_tmp75.md` 中的三输入组合逻辑（`WD_RST_N`、`TEMP_ALERT_N`、`PSTOP_MCU` → `SAFE_OK`) 挑选可直接在 3.3 V 轨上工作的器件，并记录优信电子淘宝店的现货选项，便于后续 BOM 与样机采购。整理思路参考 `schmitt_trigger_nand_options.md`。

## 1. 可选清单

| 型号 / 淘宝 ID | 逻辑族 | 通道 | V<sub>CC</sub> 范围 | 输入特性 | 输出能力 | 封装 | 参考单价 (RMB) | 适配性摘要 |
| --- | --- | --- | --- | --- | --- | --- | --- | --- |
| [SN74LVC1G11DBVR](https://item.taobao.com/item.htm?id=707087275445) | TI · LVC CMOS | 单门 3 输入 | 1.65–5.5 V[^ti-lvc1g11] | 标准 CMOS 阈值，支持缓慢边沿 | 推挽，±24 mA @3.3 V[^ti-lvc1g11] | SOT‑23‑6 | ¥0.46 | 单门 3 输入，封装占板最少；输出驱动足够拉高 ALERT 总线与 `PSTOP_CTL`。 |
| [SN74LVC1G11DCKR](https://item.taobao.com/item.htm?id=707088575930) | TI · LVC CMOS | 单门 3 输入 | 1.65–5.5 V[^ti-lvc1g11] | 同上 | 推挽，±24 mA @3.3 V[^ti-lvc1g11] | SC‑70‑6 | ¥0.19 | 与 DBVR 电气一致，体积最小；适合紧凑焊盘或共形涂层密集区域。 |
| [74HC11PW-Q100J](https://item.taobao.com/item.htm?id=695479261937) | Nexperia · HC CMOS (Q100) | 三门 3 输入 | 2.0–6.0 V[^nxp-74hc11] | CMOS 阈值 | 推挽，±6 mA @4.5 V[^nxp-74hc11] | TSSOP‑14 | ¥0.84 | 一颗提供 3 路 3 输入，与设计拓扑匹配；车规版本便于未来认证。 |
| [74HC11D,653](https://item.taobao.com/item.htm?id=673038109943) | Nexperia · HC CMOS | 三门 3 输入 | 2.0–6.0 V[^nxp-74hc11] | CMOS 阈值 | 推挽，±6 mA @4.5 V[^nxp-74hc11] | SOIC‑14 | ¥0.52 | 同电气规格，SOIC 易手工返修；适合实验板或低密度布线。 |
| [SN74HC11DR](https://item.taobao.com/item.htm?id=796176058632) | TI · HC CMOS | 三门 3 输入 | 2.0–6.0 V[^ti-hc11] | CMOS 阈值 | 推挽，±6 mA @4.5 V[^ti-hc11] | SOIC‑14 | ¥0.71 | 与 Nexperia 版本互换；当需要 TI 料号或双供策略时可选。 |
| [CD4073BM96](https://item.taobao.com/item.htm?id=673706803453) | TI · CD4000 CMOS | 三门 3 输入 | 3.0–15 V[^ti-cd4073] | 宽裕迟滞，支持慢边沿 | 推挽，±6.8 mA @5 V[^ti-cd4073] | SOIC‑14 | ¥1.03 | 兼容 3.3 V，但传播延迟与功耗均高于 HC/LVC；作为低速备选。 |

> 店内还有 SN74LS11N 等 TTL 器件，仅支持 5 V 供电，阈值不兼容 3.3 V 系统，故不列入推荐。

## 2. 与硬件保护链的适配分析

1. **电源与阈值**  
   - LVC1G11 在 1.65–5.5 V 内工作，输入高阈值约 0.7·V<sub>CC</sub>，完全覆盖 `WD_RST_N` / `TEMP_ALERT_N` / `PSTOP_MCU` 的 3.3 V CMOS 电平，无需额外上拉或电平转换。  
   - HC11 系列要求 ≥2 V 供电，3.3 V 下典型 VIH ≈0.7·V<sub>CC</sub>；与前述信号兼容，同时可在后续若扩展至 5 V 电路时保持可用性。  
   - CD4073 虽支持更宽电压，但在 3.3 V 下的迟滞与传播延迟（典型 200 ns 级[^ti-cd4073]）明显高于 HC/LVC（<10 ns），只建议在极端低频或安规冗余需求时使用。

2. **驱动能力与 ALERT 总线**  
   `hardware_protection_tps3823_tmp75.md` 建议 ALERT 总线上串接 500 kΩ–1 MΩ 下拉；LVC1G11 提供 ±24 mA 驱动余量，HC11 亦可提供 ≥±6 mA，均可在 3.3 V 下快速拉高告警线并驱动 `PSTOP_CTL`。CD4073 的输出电流稍小，但仍足以克服高阻下拉，只是沿速更慢。

3. **封装与布线**  
   - LVC1G11 单门版本适合在现有单门 NAND 焊盘附近直接放置，省去多余逻辑。SC‑70 版本面积最小但焊接难度略高。  
   - 74HC11PW (TSSOP‑14) 可在板上预留三路互锁逻辑时一次完成布线；若需手工调试，可改用 SOIC‑14 版本。  
   - 若板上仅缺少一门 3 输入逻辑（例如替换原先双路 NAND + OR 组合），优先选单门 LVC1G11，可避免多余管脚闲置。

4. **时序**  
   - LVC / HC 门在 3.3 V 下传播延迟 <10 ns，与 TPS3823 的 200 ms 复位窗口及 TMP75 的告警时序相比，可认为近似即时，不会改变保护时序。  
   - CD4073 在 3.3 V 下延迟约 200–400 ns[^ti-cd4073]，虽然仍满足毫秒级保护时间，但若系统后续引入高频抖动滤波，需要重新评估。

## 3. 选型建议

1. **首选：SN74LVC1G11DBVR / DCKR**  
   单门设计即插即用，功耗与驱动能力均满足需求；推荐 DBVR 版本以兼容常规 SOT‑23 焊盘，空间极限时可换 DCKR。
2. **多路合并：74HC11PW-Q100J**  
   当需要在同一芯片内实现多路 3 输入逻辑或考虑车规认证时，选用 TSSOP‑14 车规版本；其电气参数与普通 74HC11 一致。
3. **备选：74HC11D / SN74HC11DR 或 CD4073BM96**  
   SOIC 封装便于手工焊接及实验室验证。若需更大器件间距或对传播延迟不敏感，可选择 CD4073 作为冗余。

后续若确定改版使用单门 LVC1G11，可在 `hardware_protection_tps3823_tmp75.md` 中的逻辑框图直接替换原来“多级 NAND + OR”组合，减少器件数量与功耗。

---

[^ti-lvc1g11]: Texas Instruments, *SN74LVC1G11 Single 3-Input Positive-AND Gate*, SCES580R, 2023. V<sub>CC</sub> 范围、输出驱动和输入特性见表 6-1、6-3。
[^nxp-74hc11]: Nexperia, *74HC11; 74HCT11 Triple 3-input AND gate*, Rev. 9, 2022-05-26. 供电与输出能力见表 7/8。
[^ti-hc11]: Texas Instruments, *SN74HC11 Triple 3-Input Positive-AND Gates*, SCLS240U, 2022. 电气特性参见表 6-1。
[^ti-cd4073]: Texas Instruments, *CD4073B CMOS Triple 3-Input AND Gate*, SCLS097N, 2022. 传播延迟与输出能力见表 7-3、特性描述。

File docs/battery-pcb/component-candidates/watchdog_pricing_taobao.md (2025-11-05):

# Watchdog Component Pricing (Taobao)

数据更新：2025-10-30。聚焦智能电池 MCU 使用的连续信号看门狗芯片。

数据表引用：TPS3823/TPS3824 系列提供低有效持续 RESET 输出，[1]；STWD100 提供低有效持续 WDO 输出，可选推挽或开漏。[2]

## 型号总表

| 型号 | 单价 (¥) | 运费 (¥) | 输出电平/状态 | 驱动方式 | 备注 |
| --- | --- | --- | --- | --- | --- |
| TPS3823-33DBVR | 0.69 | 1.50 | 超时或欠压保持 RESET=L | 推挽 | 1.6 s 看门狗，含 MR 端重触发[1] |
| TPS3824-33DBVR | 3.70 | 0.00 | RESET(L) 与 RESET(H) 同步维持 | 双路推挽 | 单颗同时提供正/负极性复位[1] |
| TPS3825-33DBVR | 4.70 | 0.00 | 超时保持 RESET=L | 推挽 | 集成手动复位，监控 3.3 V 轨[1] |
| TPS3828-33DBVR | 0.65 | 1.50 | 超时保持 RESET=L | 推挽 | 上电延迟与看门狗定时共用网络[1] |
| STWD100NYWY3F | 1.32 | 1.50 | WDO 超时持续低电平 | 推挽/开漏可选 | EN 可关断，多档超时窗口[2] |

## TPS3823-33DBVR（TI）

### 器件简介

- 适配 3.3 V 轨的电源监控，VDD 低于阈值或上电复位计时结束前保持 RESET 为低。[1]
- 默认 1.6 s 看门狗周期，可通过 WDI 翻转或 MR 管脚重新触发，防止误复位。[1]
- RESET 为推挽低有效输出，如需高电平报警需外接反相逻辑或使用后级晶体管。[1]

| 店铺 | 购买链接 | 单价 (¥) | 运费 (¥) |
| --- | --- | --- | --- |
| 深圳市远大芯程科技 | <https://item.taobao.com/item.htm?id=733699852343> | 0.40 | 1.00 |
| 深圳市恒芯科创电子 | <https://item.taobao.com/item.htm?id=707168250712> | 0.47 | 1.00 |
| 深圳市垚鑫电子科技 | <https://item.taobao.com/item.htm?id=608674230903> | 0.38 | 0.50 |
| 深圳市铭科芯电子 | <https://item.taobao.com/item.htm?id=733906869349> | 0.94 | 0.00 |
| 港柏芯城 | <https://item.taobao.com/item.htm?id=735663142560> | 0.38 | 1.00 |

## TPS3824-33DBVR（TI）

### 器件简介

- 提供同步的低有效 RESET 与高有效 RESET 输出，便于同时驱动不同极性的复位端。[1]
- 默认 1.6 s 看门狗定时，WDI 不翻转将保持低有效 RESET，直到重新喂狗或完成延迟。[1]
- 与 TPS3823 共用 5-pin SOT-23 封装，可直接替换共享 PCB 封装焊盘。[1]

| 店铺 | 购买链接 | 单价 (¥) | 运费 (¥) |
| --- | --- | --- | --- |
| 成港电子 | <https://item.taobao.com/item.htm?id=609308284027> | 0.95 | 2.00 |
| 深圳市诺维利电子企业店 | <https://item.taobao.com/item.htm?id=967450507950> | 1.90 | 0.00 |
| 全新集成电子商城 | <https://item.taobao.com/item.htm?id=710776572841> | 1.00 | 0.00 |
| 科利讯电子 | <https://item.taobao.com/item.htm?id=799626907282> | 0.45 | 3.00 |
| 汕头和祥电子 | <https://item.taobao.com/item.htm?id=666267401429> | 1.50 | 6.00 |

## TPS3825-33DBVR（TI）

### 器件简介

- 监控 3.3 V 电源并在欠压或上电延迟期保持 RESET 低电平，直到系统稳定。[1]
- 默认 1.6 s 看门狗窗口，可通过 MR 管脚手动触发复位，适合需要人工复位的电池管理板卡。[1]
- 推挽低有效 RESET 输出，直接驱动 MCU 复位脚，无需外部上拉网络。[1]

| 店铺 | 购买链接 | 单价 (¥) | 运费 (¥) |
| --- | --- | --- | --- |
| 深圳市芯和电子 | <https://item.taobao.com/item.htm?id=837942957972> | 1.99 | 0.00 |
| 深圳市欣胜电子商城 | <https://item.taobao.com/item.htm?id=820234906182> | 1.30 | 0.90 |
| 君胜电子商城 | <https://item.taobao.com/item.htm?id=619552851281> | 1.50 | 0.00 |
| 深圳市海通电子科技 | <https://item.taobao.com/item.htm?id=867835090250> | 1.10 | 0.00 |
| 深圳市壹芯电子BOM表配单 | <https://item.taobao.com/item.htm?id=896477491076> | 3.50 | 0.00 |

## TPS3828-33DBVR（TI）

### 器件简介

- SOT23-5 封装与 TPS3823/24 引脚兼容，便于 PCB 共用焊盘和替换。[1]
- RESET 推挽低有效，默认 1.6 s 看门狗窗口，可经 MR 脚重新计时。[1]
- 上电延迟与看门狗共用定时网络，只需一颗电容设定延迟与超时。[1]

| 店铺 | 购买链接 | 单价 (¥) | 运费 (¥) |
| --- | --- | --- | --- |
| 深圳市垚鑫电子科技 | <https://item.taobao.com/item.htm?id=603006301300> | 0.58 | 1.00 |
| 淼鑫电子科技 | <https://item.taobao.com/item.htm?id=726419068056> | 0.29 | 1.00 |
| 深圳市恒芯科创电子 | <https://item.taobao.com/item.htm?id=782732862531> | 0.56 | 1.00 |
| 深圳市集芯电子科技有限公司 | <https://item.taobao.com/item.htm?id=675303627806> | 0.74 | 1.50 |
| 联科达电子 | <https://item.taobao.com/item.htm?id=676116060345> | 0.80 | 0.00 |

## STWD100NYWY3F（ST）

### 器件简介

- 独立看门狗电路，WDI 超时后 WDO 持续拉低直至重新喂狗或通过 EN 重新启动。[2]
- WDO 可选推挽或开漏，支持 3.4 ms 至 1.6 s 多档超时窗口，适合不同主控心跳频率。[2]
- EN 引脚默认下拉启用，方便系统待机时通过 MCU 高电平关断以降低静态功耗。[2]

| 店铺 | 购买链接 | 单价 (¥) | 运费 (¥) |
| --- | --- | --- | --- |
| 深圳市捷洲电子科技 | <https://item.taobao.com/item.htm?id=798146856741> | 0.94 | 0.00 |
| 利好芯城 | <https://item.taobao.com/item.htm?id=763900260932> | 3.85 | 1.00 |
| ICGO | <https://item.taobao.com/item.htm?id=753329757565> | 1.50 | 3.00 |
| 凌捷达电子 | <https://item.taobao.com/item.htm?id=908838461707> | 1.08 | 3.00 |
| 优质电子 | <https://item.taobao.com/item.htm?id=972126445746> | 1.30 | 0.00 |

---

[1]: https://www.ti.com/lit/ds/symlink/tps3823.pdf
[2]: https://www.st.com/resource/en/datasheet/stwd100.pdf

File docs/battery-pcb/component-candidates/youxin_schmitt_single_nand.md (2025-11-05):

# 单路施密特触发与非门检索记录

本轮检索聚焦于淘宝渠道公开在售的**单路 (single-gate) 与非门**且**输入带施密特触发**的逻辑芯片，作为硬件保护链的候选器件。

## 检索步骤

- 以逻辑 NAND 相关关键词检索，整理 1G/单路器件清单；
- 查阅官方数据手册，确认输入端具备施密特触发迟滞，并记录主要电气指标；
- 排除多路器件（如 74HC132、SN74LVC2G132）或未提供施密特触发特性的型号。

## 符合条件的在售型号

| 芯片型号 | 封装 | 价格 (¥) | 购买链接 | 施密特触发依据 |
| --- | --- | --- | --- | --- |
| SN74AHC1G00DBVR | SOT-23-5 | 1.95 | https://item.taobao.com/item.htm?id=673364782576 | 数据手册列出“Schmitt trigger action at all inputs”[[1]](#ref-ti-ahc1g00) |
| SN74AHC1G00DCKR | SC-70-5 | 0.25 | https://item.taobao.com/item.htm?id=704713346062 | 同上[[1]](#ref-ti-ahc1g00) |
| 74AUP1G00GW,125 | SOT-353 (TSSOP5) | 0.49 | https://item.taobao.com/item.htm?id=696330677234 | 型号说明书明确“Schmitt-trigger action at all inputs”[[2]](#ref-nxp-74aup1g00) |
| 74AUP1G00GX,125 | X2SON-5 | 0.40 | https://item.taobao.com/item.htm?id=696835563731 | 同一数据手册覆盖所有封装[[2]](#ref-nxp-74aup1g00) |
| SN74AUP1G00DCKR | SC-70-5 | 0.96 | https://item.taobao.com/item.htm?id=705201135652 | TI 数据手册指出“Input hysteresis allows slow input transition”[[3]](#ref-ti-aup1g00) |

## 已排除的单路与非门

- SN74LVC1G00（含 DBVR/DCKR 等封装）：数据手册特性未包含施密特触发，仅为标准 CMOS 输入[[4]](#ref-ti-lvc1g00)。
- SN74AHCT1G00（DBVR 等封装）：特性仅强调 TTL 兼容输入，无施密特描述[[5]](#ref-ti-ahct1g00)。
- SN74HCT1G00GV、SN74LVC1G38 等：分别为非施密特 TTL NAND、开漏 NAND，官方资料均未给出施密特输入特性[[5]](#ref-ti-ahct1g00)[[6]](#ref-ti-lvc1g38)。

---

[1] Texas Instruments, *SN74AHC1G00 Single 2-Input Positive-NAND Gate*, 特性条目列出 “Schmitt trigger action at all inputs”. https://www.ti.com/document-viewer/SN74AHC1G00/datasheet  
[2] Nexperia, *74AUP1G00 Low-power 2-input NAND gate*, “Schmitt-trigger action at all inputs makes the circuit tolerant of slower input rise and fall times.” https://assets.nexperia.com/documents/data-sheet/74AUP1G00.pdf  
[3] Texas Instruments, *SN74AUP1G00 Low-Power Single 2-Input Positive-NAND Gate*, “Input hysteresis allows slow input transition and better switching noise immunity.” https://www.ti.com/lit/ds/symlink/sn74aup1g00.pdf  
[4] Texas Instruments, *SN74LVC1G00 Single 2-Input Positive-NAND Gate*, 特性仅列出 CMOS 常规参数，无施密特触发。https://www.ti.com/document-viewer/SN74LVC1G00/datasheet  
[5] Texas Instruments, *SN74AHCT1G00 Single 2-Input Positive-NAND Gate*, 特性仅说明 TTL 兼容输入。https://www.ti.com/document-viewer/SN74AHCT1G00/datasheet  
[6] Texas Instruments, *SN74LVC1G38 Single 2-Input NAND Gate With Open-Drain Output*, 特性列表中无施密特触发项。https://www.ti.com/lit/ds/symlink/sn74lvc1g38.pdf

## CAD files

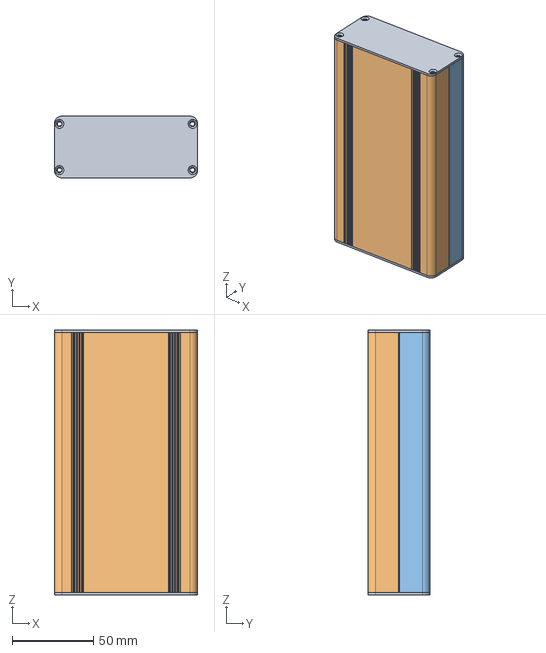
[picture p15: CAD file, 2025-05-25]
models/分体式K70.stp
88.0 x 38.0 x 163.0 mm

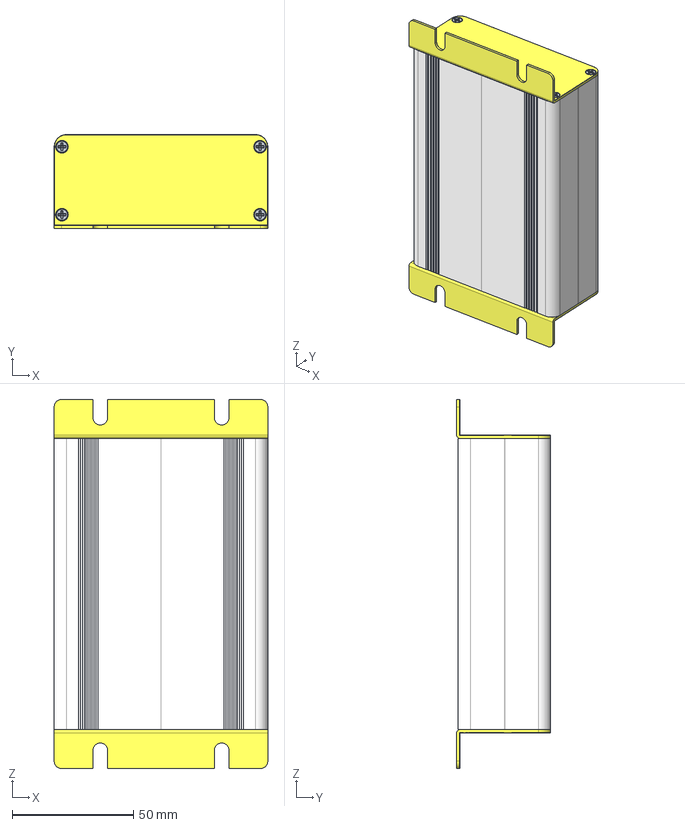
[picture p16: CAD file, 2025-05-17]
models/028/028b.stp
88.0 x 38.6 x 152.0 mm
M2-5 x 8

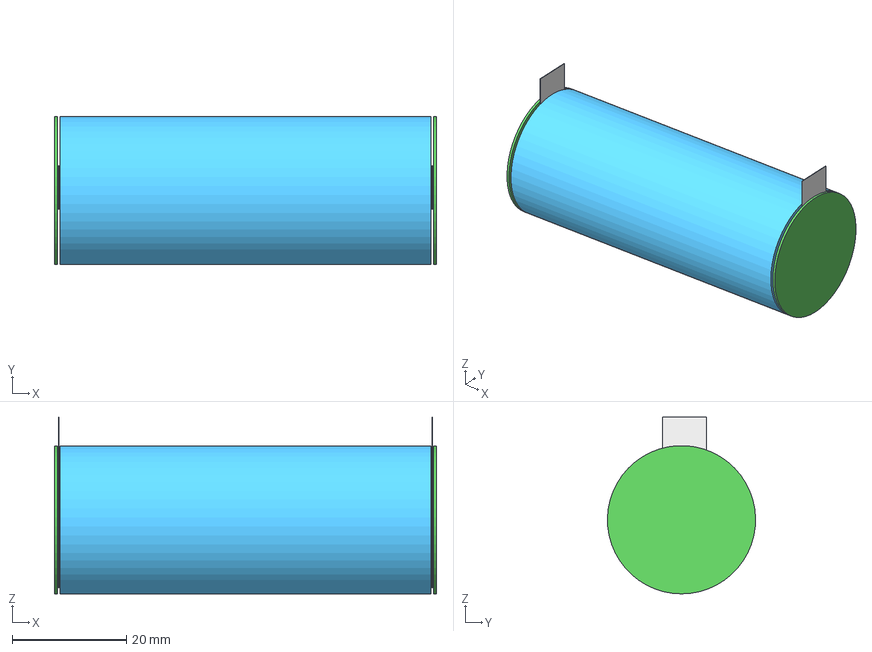
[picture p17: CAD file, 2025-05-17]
models/ups120-shell-26650-BATTERY.step
67.0 x 26.0 x 31.0 mm
battery
fishpaper1
fishpaper2
nickel-strip1
nickel-strip2

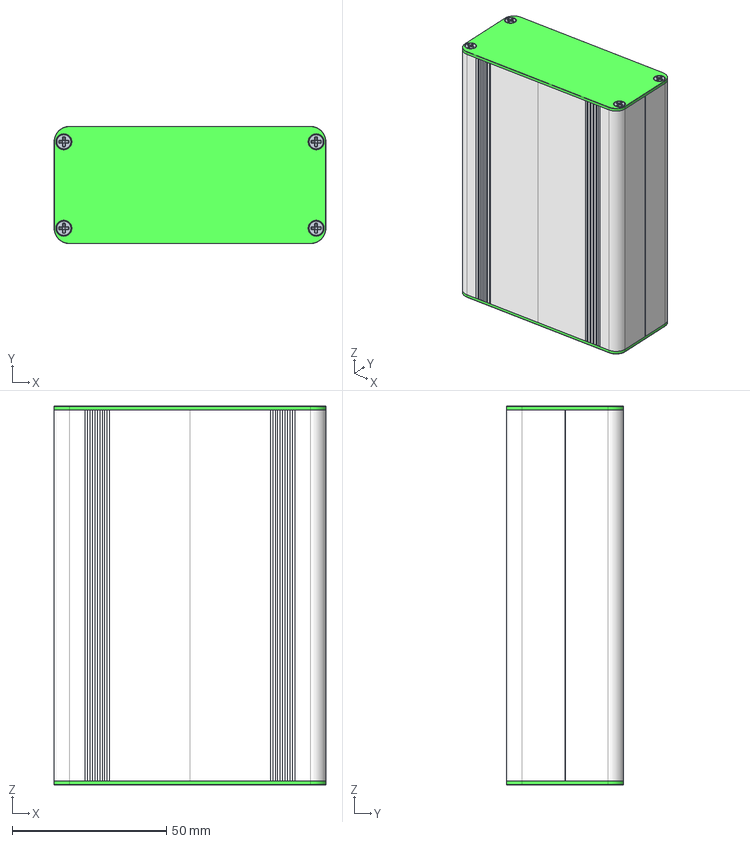
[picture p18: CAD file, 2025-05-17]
models/028/028a.stp
88.0 x 38.0 x 122.7 mm
M2-5 x 8

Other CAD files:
models/028/028.dwg

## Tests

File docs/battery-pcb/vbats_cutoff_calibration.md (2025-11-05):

# SC8815 VBATS Charge-Termination Calibration

## 1. Objective

Guarantee an **18.0 V** charge termination for the 5S LiFePO₄ stack when SC8815 operates with an external VBATS divider, and provide a consistent calibration flow for production and service.

## 2. Fixed Parameters

| Item | Typical | Tolerance |
| ---- | ---- | ---- |
| Upper resistor `Rtop` | 140 kΩ | ±1 % |
| Lower resistor `Rbottom` | 10 kΩ | ±1 % |
| SC8815 reference `VBATS_REF` | 1.203 V | ±0.5 % |

SC8815 regulates according to:

```
VBAT_limit = VBATS_REF × (1 + RUP / RDOWN)
RUP   = Rtop + (1 − α) · Rp
RDOWN = Rbottom + α · Rp
0 ≤ α ≤ 1
```

`Rp` is the total potentiometer resistance and α is the normalized wiper position measured from the ground side.

## 3. Potentiometer Range Requirement

Solve `VBAT_limit = 18.0 V` while sweeping the component corners (Rtop/Rbottom ±1 %, VBATS_REF ±0.5 %). Enforcing `0 ≤ α ≤ 1` gives:

```
α ≥ 0  ⇒ Rp ≥ m·Rbottom − Rtop
α ≤ 1  ⇒ Rp ≥ (Rtop − m·Rbottom) / m
m = 18 / VBATS_REF − 1
```

The tightest case yields:

```
Rp_actual ≥ 3.18 kΩ
```

If the potentiometer tolerance is ±25 %, the nominal value must satisfy `Rp_nom × (1 − 0.25) ≥ 3.18 kΩ`, thus:

```
Rp_nom ≥ 4.3 kΩ
```

## 4. Selected Component

Use a standard 5 kΩ trimmer; even at the −25 % corner it still provides 3.75 kΩ, safely above the requirement. Recommended part:

- **VGF39NCHXT-B502** (HDK/Hokuriku) — 270° ± 20° single turn, linear (B) taper, 0.15 W @ 70 °C, 50 V max, residual resistance ≤200 Ω, no post-solder cleaning.

## 5. Wiring

Connect the potentiometer end terminals to the existing 140 kΩ / 10 kΩ divider nodes and route the wiper directly to VBATS. After soldering, rotate fully toward ground and back off ~5° to reduce end-stop residual resistance.

## 6. Calibration Procedure

1. Apply 18.5 V / 0.5 A from a lab supply; monitor PACK voltage with a calibrated ≥4½-digit DMM while SC8815 enters constant-voltage mode.
2. If PACK voltage exceeds 18.0 V, rotate counter-clockwise (away from ground); if it is below 18.0 V, rotate clockwise.
3. Wait until the voltage stabilizes at **18.00 V ±0.03 V** for at least 5 s, then record the knob position and reading.
4. Power down, lock the wiper with a small drop of UV or conformal adhesive, cure, and confirm the voltage remains in range.
5. Log timestamp, fixture ID, and final voltage in the production traceability system.

## 7. Residual Error Summary

| Source | Typical impact |
| ---- | ---- |
| Wiper repeatability ±1 % travel | ≈ ±0.13 V (≤±0.05 V with fixtures) |
| VBATS_REF ±0.5 % | ±0.09 V |
| Divider tempco 25 ppm/°C (0–60 °C) | ±0.04 V |
| Potentiometer aging (70 °C/1000 h ±5 %) | ≈ ±0.9 V, plan annual recheck |

Recalibrate if drift exceeds ±0.2 V; beyond ±0.5 V, adjust SC8815 software limits as an additional guard.

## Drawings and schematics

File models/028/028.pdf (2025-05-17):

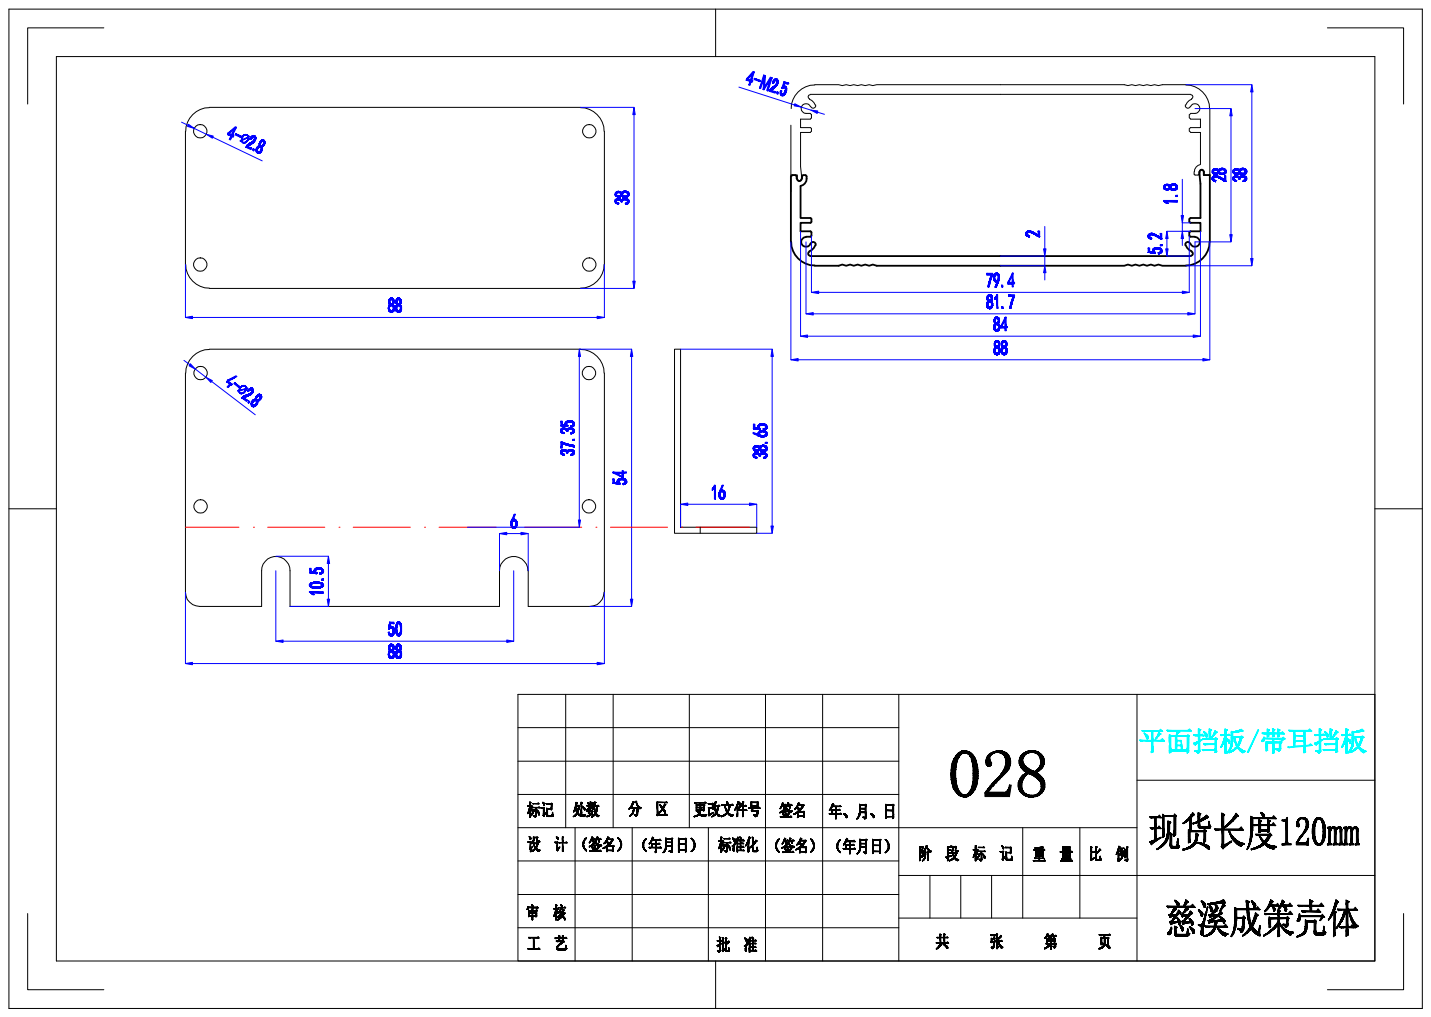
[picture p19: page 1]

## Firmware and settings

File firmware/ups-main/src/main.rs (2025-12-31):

#![no_std]
#![no_main]

mod adin_temp;
mod batt_est;
mod button_input;
mod buzzer;
mod display;
mod fan_control;
mod io_expander;
mod power;
mod prompt_tone;
mod thermal;
mod tsens;
mod ui;

pub const UPS_VERSION: &str = env!("CARGO_PKG_VERSION");
pub const UPS_GIT_HASH: &str = env!("UPS_GIT_HASH");
pub const UPS_BUILD_TS: &str = env!("UPS_BUILD_TS");

use button_input::{ButtonConfig, ButtonState};
use defmt::{Debug2Format, debug, info, warn};
use embassy_embedded_hal::shared_bus::asynch::i2c::I2cDevice;
use embassy_executor::Spawner;
use embassy_sync::{
    blocking_mutex::raw::NoopRawMutex,
    channel::{Channel, Receiver, Sender},
    mutex::Mutex,
};
use embassy_time::{Duration, Timer};
use embedded_hal::delay::DelayNs;
use embedded_hal_async::i2c::I2c as AsyncI2c;
use esp_backtrace as _; // panic handler + backtrace/println
use esp_hal::{
    Async,
    delay::Delay,
    dma::{DmaRxBuf, DmaTxBuf},
    dma_buffers,
    gpio::{DriveStrength, Input, InputConfig, Level, Output, OutputConfig, Pull},
    i2c::master::{Config as I2cConfig, I2c},
    ledc::{
        LSGlobalClkSource, Ledc, LowSpeed, channel, channel::ChannelIFace, timer, timer::TimerIFace,
    },
    spi::{
        Mode,
        master::{Config as SpiConfig, Spi, SpiDmaBus},
    },
    time::Rate,
    timer::timg::TimerGroup,
};
use esp_println as _; // install UART logger + defmt bridge
use io_expander::Tca6408a;
use sc8815::{self, registers::constants::DEFAULT_ADDRESS as SC8815_ADDR};
use static_cell::StaticCell;
// STM32 smart-battery I2C slave (validation-only, single-shot)
pub const STM32_ADDR: u8 = 0x35;
pub const SB_SIG: [u8; 2] = [b'S', b'B'];
pub const SB_WINDOW_START: u8 = 0x08;
pub const SB_WINDOW_END: u8 = 0x0F;
// Compact temperature telemetry window (0x40..0x47, all int8 in °C) sourced
// from the STM32 smart-battery thermal aggregation and used as the sole
// temperature source on the ESP32 side:
//   [0]=pack, [1]=charger, [2..5]=NTC0..3, [6]=BQ_INT, [7]=MCU.
pub const SB_TEMP_WINDOW_BASE: u8 = 0x40;
pub const SB_TEMP_WINDOW_LEN: usize = 8;
pub const TEST_A: u8 = 0x5A;
pub const TEST_B: u8 = 0xA5;
pub const SB_REG_CHG_CONFIG: u8 = 0x31;
pub const SB_REG_CHG_PAUSE_CAUSE: u8 = 0x32;
pub const SB_REG_STATE_FLAGS: u8 = 0x20;
/// Smart-battery TEMP_STATUS register (single-byte thermal fault flags).
/// See `TempFaultFlags` / `decode_temp_status` for the decoded view.
pub const SB_REG_TEMP_STATUS: u8 = 0x23;
pub const SB_STATE_FLAG_AC_PRESENT: u16 = 0x0001;
// Mirrors of STM32 smart-battery charging/session bits used for UI mode
// derivation and fault decoding (UI only; AC/charge policy由 ESP32 侧
// 的 INA226+TPS2490 PG 组合判定，详见 charging_policy.md)。
pub const SB_STATE_FLAG_CHARGING: u16 = 1 << 1;
pub const SB_STATE_FLAG_CHG_PAUSED: u16 = 1 << 2;
pub const SB_STATE_FLAG_FULL: u16 = 1 << 4;
// Mirror of STM32 smart-battery state_bits::BALANCING; used for UI overlay.
pub const SB_STATE_FLAG_BALANCING: u16 = 1 << 5;
// Mirrors of smart-battery state_bits::FAULT_BQ / FAULT_SC; used for UPS discharge gating.
pub const SB_STATE_FLAG_FAULT_BQ: u16 = 1 << 6;
pub const SB_STATE_FLAG_FAULT_SC: u16 = 1 << 7;

/// Decoded view of the STM32 smart-battery TEMP_STATUS register (0x23).
#[derive(Clone, Copy, Debug)]
pub struct TempFaultFlags {
    pub temp_low: bool,
    pub temp_high_chg: bool,
    pub temp_high_dsg: bool,
}

/// Decode TEMP_STATUS bits into a strongly-typed flag set.
pub fn decode_temp_status(raw: u8) -> TempFaultFlags {
    TempFaultFlags {
        temp_low: (raw & 0x01) != 0,
        temp_high_chg: (raw & 0x02) != 0,
        temp_high_dsg: (raw & 0x04) != 0,
    }
}

pub const SB_CHG_STATUS_BALANCING: u8 = 1 << 5;
pub const SB_CFG_BIT_AUTO: u8 = 1 << 0;
pub const SB_CFG_BIT_MANUAL: u8 = 1 << 1;
pub const SB_CFG_SPEED_SHIFT: u8 = 2;

fn dashboard_mode_str(mode: ui::DashboardMode) -> &'static str {
    match mode {
        ui::DashboardMode::Charge => "Charge",
        ui::DashboardMode::Ready => "Ready",
        ui::DashboardMode::Discharge => "Discharge",
        ui::DashboardMode::LowBatt => "LowBatt",
    }
}

fn batt_mode_str(mode: ui::Mode) -> &'static str {
    match mode {
        ui::Mode::Standby => "Standby",
        ui::Mode::Charge => "Charge",
        ui::Mode::Discharge => "Discharge",
    }
}

fn compute_min_cell_mv(cells_mv: &[Option<u16>; 5]) -> Option<u16> {
    let mut min_mv: Option<u16> = None;
    for cell in cells_mv.iter().copied() {
        if let Some(v) = cell {
            min_mv = Some(match min_mv {
                Some(current) => core::cmp::min(current, v),
                None => v,
            });
        }
    }
    min_mv
}

fn is_discharge_active(state: &power::PowerState) -> bool {
    if !state.out_enabled {
        return false;
    }

    const DISCH_CURR_THRESHOLD_MA: i32 = 50;
    const DISCH_POWER_THRESHOLD_MW: u32 = 1_000;

    if let Some(out_a) = state.out_a_ma {
        if out_a >= DISCH_CURR_THRESHOLD_MA {
            return true;
        }
    }
    if let Some(out_w) = state.out_w_mw {
        if out_w >= DISCH_POWER_THRESHOLD_MW {
            return true;
        }
    }
    if let Some(ibat) = state.ibat_ma {
        if ibat <= -DISCH_CURR_THRESHOLD_MA {
            return true;
        }
    }

    false
}

fn compute_dashboard_modes(state: &power::PowerState) -> (ui::DashboardMode, ui::Mode) {
    enum BaseMode {
        Charge,
        Ready,
        Discharge,
    }

    // Step 1: derive a base mode (Charge / Ready / Discharge).
    //
    // 顶部 MODE 由 ESP32 单侧视角决定：是否请求充电、是否认为 AC 存在、是否处于
    // 温度暂停等。STM32 的 STATE_FLAGS 仅用于第四行故障/提示，不再回退或延迟
    // 顶部 MODE 的切换。
    let discharge_active = is_discharge_active(state);
    let charge_requested = matches!(state.charge_mode, power::ChargeMode::Manual);
    let charge_current = matches!(state.ibat_ma, Some(i) if i > 50);

    let base_mode = if discharge_active {
        BaseMode::Discharge
    } else if state.ac_present && (charge_requested || charge_current) && !state.temp_pause_active {
        BaseMode::Charge
    } else {
        BaseMode::Ready
    };

    // Step 2: overlay LowBatt on top of Ready when appropriate.
    let mut dashboard_mode = match base_mode {
        BaseMode::Charge => ui::DashboardMode::Charge,
        BaseMode::Ready => ui::DashboardMode::Ready,
        BaseMode::Discharge => ui::DashboardMode::Discharge,
    };

    if let BaseMode::Ready = base_mode {
        if let Some(min_cell_mv) = compute_min_cell_mv(&state.cells_mv) {
            if min_cell_mv < 3_200 {
                if state.ac_present {
                    // With AC present, prefer Charge over LowBatt.
                    dashboard_mode = ui::DashboardMode::Charge;
                } else {
                    dashboard_mode = ui::DashboardMode::LowBatt;
                }
            }
        }
    }

    // Step 3: derive batt_mode used for third line (CHG/IDLE/OUT) and batt detail.
    let batt_mode = match dashboard_mode {
        ui::DashboardMode::Charge => ui::Mode::Charge,
        ui::DashboardMode::Ready => ui::Mode::Standby,
        ui::DashboardMode::Discharge => ui::Mode::Discharge,
        ui::DashboardMode::LowBatt => {
            if discharge_active {
                ui::Mode::Discharge
            } else {
                ui::Mode::Standby
            }
        }
    };

    (dashboard_mode, batt_mode)
}

// Battery pack configuration (per project spec; do not probe at runtime)
pub const PACK_CELLS_S: u8 = 5; // 5S Li-ion (BQ76920 max 5S)
pub const SOC_EMPTY_VBAT_MV: u32 = 12_500; // Cutoff threshold (pack)
pub const SOC_FULL_VBAT_MV: u32 = 18_500; // Full threshold (pack)
pub const CHARGE_START_VBAT_MV: u32 = 17_000;
pub const CHARGE_STOP_VBAT_MV: u32 = SOC_FULL_VBAT_MV;
/// UPS discharge low-voltage stop threshold (pack), must stay >= PACK_OUTPUT_CUTOFF_THRESHOLD_MV.
/// match discharge_policy.md §4.3; 5S * 2.7V ≈ 13.5V, keeps margin above PACK_OUTPUT_CUTOFF_THRESHOLD_MV.
pub const DISCH_STOP_VBAT_MV: u32 = 13_500;
/// UPS discharge resume threshold with hysteresis (pack).
/// match discharge_policy.md §4.3; 5S * 3.2V ≈ 16.0V.
pub const DISCH_RESUME_VBAT_MV: u32 = 16_000;
/// AC 适配器恢复后，AC GOOD（PG 断言 + VIN 在线）连续为真至少 10 s 才允许重新开始充电。
pub const AC_STABLE_MS: u64 = 10_000;
pub const TEMP_PAUSE_C: f32 = 40.0;
pub const TEMP_RESUME_C: f32 = 35.0;
/// UPS discharge thermal stop threshold (SC8815 ADIN, °C).
pub const UPS_DISCH_STOP_C: f32 = 70.0;
/// UPS discharge thermal resume threshold (°C), must be < UPS_DISCH_STOP_C.
pub const UPS_DISCH_RESUME_C: f32 = 50.0;
/// UPS VBUS minimum/maximum targets allowed by project spec (see SC8815_External_Resistor_Configuration.md).
pub const UPS_VBUS_MIN_MV: u16 = 9_000;
pub const UPS_VBUS_MAX_MV: u16 = 20_600;
/// SC8815 VBUS/VBAT sense resistor values on the UPS power board (see
/// docs/ups-power-board/netlist_ups-power-board.enet, R47/R26 = 5mΩ).
pub const UPS_SC_RS1_MOHM: u16 = 5;
pub const UPS_SC_RS2_MOHM: u16 = 5;
/// SC8815 OTG current limits (mA) for UPS OUT path.
/// With RS1=RS2=5mΩ and IBUS_RATIO=3x, the SC8815 datasheet and driver
/// formula cap IBUS at ≈6A (IBUS_LIM_SET <= 255). We therefore clamp the
/// software limit to 6000mA on both sides.
pub const UPS_SC_IBUS_LIMIT_MA: u16 = 6_000;
pub const UPS_SC_IBAT_LIMIT_MA: u16 = 6_000;
/// Default 12V mode targets (VIN present vs missing).
pub const UPS_VBUS_AC_ONLINE_MV: u16 = 11_500;
pub const UPS_VBUS_AC_OFFLINE_MV: u16 = 12_000;
pub const SB_WRITE_RETRY_ATTEMPTS: u8 = 3;
pub const SB_WRITE_RETRY_DELAY_MS: u32 = 5;
pub const SB_CFG_VERIFY_INTERVAL_MS: u64 = 1_000;
pub const SB_STATE_POLL_INTERVAL_MS: u64 = 10_000;

pub type I2cBusMutex = Mutex<NoopRawMutex, I2c<'static, Async>>;
pub type SharedI2cDevice<'a> = I2cDevice<'a, NoopRawMutex, I2c<'static, Async>>;
static I2C0_BUS: StaticCell<I2cBusMutex> = StaticCell::new();

static FAN_TIMER: StaticCell<timer::Timer<'static, LowSpeed>> = StaticCell::new();

const UI_EVENT_CAPACITY: usize = 8;
const MODE_MELODY_STABLE_MS: u64 = 1_800;
const MODE_MELODY_COOLDOWN_MS: u64 = 30_000;

#[derive(Clone, Copy, PartialEq, Eq)]
enum UiScreen {
    Dashboard,
    BattDetail,
}

#[derive(Clone, Copy)]
enum UiEvent {
    SwitchToDashboard,
    SwitchToBattDetail,
}

type UiEventSender = Sender<'static, NoopRawMutex, UiEvent, UI_EVENT_CAPACITY>;
type UiEventReceiver = Receiver<'static, NoopRawMutex, UiEvent, UI_EVENT_CAPACITY>;

static UI_EVENT_CHANNEL: StaticCell<Channel<NoopRawMutex, UiEvent, UI_EVENT_CAPACITY>> =
    StaticCell::new();

pub(crate) fn compose_sb_charge_config(auto: bool, manual: bool, speed_tier: u8) -> u8 {
    let mut value = (speed_tier & 0x03) << SB_CFG_SPEED_SHIFT;
    if auto {
        value |= SB_CFG_BIT_AUTO;
    }
    if manual {
        value |= SB_CFG_BIT_MANUAL;
    }
    value
}

// Populate the ESP-IDF App Descriptor so espflash can read metadata
esp_bootloader_esp_idf::esp_app_desc!();

// Provide millisecond timestamps for defmt logs
defmt::timestamp!("{=u64} ms", {
    esp_hal::time::Instant::now()
        .duration_since_epoch()
        .as_millis() as u64
});
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
async fn main(spawner: Spawner) -> ! {
    // Initialise chip peripherals
    let peripherals = esp_hal::init(esp_hal::Config::default());
    let timg0 = TimerGroup::new(peripherals.TIMG0);
    esp_rtos::start(timg0.timer0);
    let mut delay = Delay::new();
    let boot_millis = esp_hal::time::Instant::now()
        .duration_since_epoch()
        .as_millis() as u64;

    // Firmware version log (once per boot)
    info!(
        "ups-main: version={} commit={} build_ts={}",
        UPS_VERSION, UPS_GIT_HASH, UPS_BUILD_TS,
    );

    // === Restore board bring-up so other subsystems remain functional ===
    // Buttons (internal pull-up, active-low)
    let in_cfg = InputConfig::default().with_pull(Pull::Up);
    let btn_center = Input::new(peripherals.GPIO0, in_cfg);
    let btn_up = Input::new(peripherals.GPIO1, in_cfg);
    let btn_right = Input::new(peripherals.GPIO2, in_cfg);
    let btn_down = Input::new(peripherals.GPIO4, in_cfg);
    let btn_left = Input::new(peripherals.GPIO5, in_cfg);

    let ui_channel = UI_EVENT_CHANNEL.init(Channel::new());
    let ui_event_tx: UiEventSender = ui_channel.sender();
    let ui_event_rx: UiEventReceiver = ui_channel.receiver();

    let (_tone_tx, tone_rx) = prompt_tone::channel();

    // Spawn asynchronous button scanner task.
    let _ = spawner.spawn(button_task(
        btn_center,
        btn_up,
        btn_right,
        btn_down,
        btn_left,
        ui_event_tx,
        boot_millis,
        _tone_tx.clone(),
    ));

    // RESET# to TCA6408A
    let mut _reset_tca = Output::new(peripherals.GPIO6, Level::High, OutputConfig::default());
    _reset_tca.set_high();

    // INTn (open-drain, low-active) – configure as input with pull-up
    let _int_n = Input::new(
        peripherals.GPIO7,
        InputConfig::default().with_pull(Pull::Up),
    );

    // I2C0 @ 100kHz (SDA=GPIO8, SCL=GPIO9) — align with STM32 slave timing.
    // Configure in async mode and expose via an Embassy shared-bus mutex so that
    // all peripherals (STM32 smart-battery, TCA6408A, SC8815) use real async I2C
    // transactions driven by the hardware peripheral.
    let i2c = I2c::new(
        peripherals.I2C0,
        I2cConfig::default().with_frequency(Rate::from_khz(100)),
    )
    .unwrap()
    .with_sda(peripherals.GPIO8)
    .with_scl(peripherals.GPIO9)
    .into_async();
    let i2c_bus = I2C0_BUS.init(Mutex::new(i2c));

    // Initialise shared power/thermal state and spawn background management tasks.
    let power_state = power::init_power_state();
    let thermal_state = thermal::init_thermal_state();
    let _ = spawner.spawn(power::power_task(
        i2c_bus,
        power_state,
        thermal_state,
        _tone_tx.clone(),
    ));

    // SPI for LCD (write-only): MOSI=11, SCLK=12, optional CS/DC/RST/BL as GPIO
    let mut _dc = Output::new(peripherals.GPIO10, Level::Low, OutputConfig::default());
    let mut _cs = Output::new(peripherals.GPIO13, Level::High, OutputConfig::default());
    let mut _rst = Output::new(peripherals.GPIO14, Level::High, OutputConfig::default());
    // Backlight via LEDC will be configured below; keep BL pin as PWM (GPIO15)
    let _ = _rst.set_low();
    delay.delay_ms(10u32);
    let _ = _rst.set_high();

    // SPI for LCD (write-only): MOSI=11, SCLK=12, optional CS/DC/RST/BL as GPIO.
    // Configure with DMA and async mode so higher-level code can migrate to embedded-hal-async
    // without changing the hardware setup again.
    let (rx_buf, rx_desc, tx_buf, tx_desc) = dma_buffers!(4096);
    let dma_rx = DmaRxBuf::new(rx_desc, rx_buf).unwrap();
    let dma_tx = DmaTxBuf::new(tx_desc, tx_buf).unwrap();

    let mut spi = Spi::new(
        peripherals.SPI2,
        SpiConfig::default()
            // Use conservative 6 MHz per UI branch final; Mode 0 per main
            .with_frequency(Rate::from_mhz(6))
            .with_mode(Mode::_0),
    )
    .unwrap()
    .with_sck(peripherals.GPIO12)
    .with_mosi(peripherals.GPIO11)
    .with_dma(peripherals.DMA_CH0)
    .with_buffers(dma_rx, dma_tx)
    .into_async();
    // Reflect STM32 self-check completion on boot screen
    let _ = ui::boot_update(&mut spi, &mut _cs, &mut _dc, 15, "STM32 I2C Selfcheck");

    // USB2_PG (STAT) input – GPIO21 (pull-up)
    let _usb2_pg = Input::new(
        peripherals.GPIO21,
        InputConfig::default().with_pull(Pull::Up),
    );

    // LEDC PWM: FAN_PWM on GPIO40 (LowSpeed@25kHz)
    let mut ledc = Ledc::new(peripherals.LEDC);
    ledc.set_global_slow_clock(LSGlobalClkSource::APBClk);

    let t_fan = FAN_TIMER.init(ledc.timer::<LowSpeed>(timer::Number::Timer0));
    t_fan
        .configure(timer::config::Config {
            duty: timer::config::Duty::Duty8Bit,
            clock_source: timer::LSClockSource::APBClk,
            frequency: Rate::from_khz(25),
        })
        .unwrap();

    let mut fan_en = Output::new(peripherals.GPIO39, Level::Low, OutputConfig::default()); // FAN_EN (MTCK)
    let mut fan_pwm = ledc.channel(channel::Number::Channel0, peripherals.GPIO40);
    fan_pwm
        .configure(channel::config::Config {
            timer: t_fan,
            duty_pct: 0,
            drive_mode: esp_hal::gpio::DriveMode::PushPull,
        })
        .unwrap();

    // BUZZER on GPIO38: LEDC square PWM (audio-rate).
    //
    // Keep max GPIO drive strength to help saturate Q1 (see BUZZER datasheet).
    let buzzer_output = Output::new(
        peripherals.GPIO38,
        Level::Low,
        OutputConfig::default().with_drive_strength(DriveStrength::_40mA),
    )
    .into_peripheral_output();

    let mut t_buz = ledc.timer::<LowSpeed>(timer::Number::Timer1);
    t_buz
        .configure(timer::config::Config {
            duty: timer::config::Duty::Duty8Bit,
            clock_source: timer::LSClockSource::APBClk,
            frequency: Rate::from_hz(buzzer::DEFAULT_FREQ_HZ),
        })
        .unwrap();

    let mut buzzer_ch = ledc.channel::<LowSpeed>(channel::Number::Channel1, buzzer_output);
    buzzer_ch
        .configure(channel::config::Config {
            timer: &buzzer::BUZZER_TIMER_PROXY,
            duty_pct: 0,
            drive_mode: esp_hal::gpio::DriveMode::PushPull,
        })
        .unwrap();

    let buzzer = buzzer::Buzzer::new(t_buz, buzzer_ch);
    let _ = spawner.spawn(prompt_tone::tone_task(buzzer, tone_rx));
    let _ = spawner.spawn(boot_melody_task(_tone_tx.clone()));
    let _ = ui::boot_update(&mut spi, &mut _cs, &mut _dc, 25, "GPIO/LEDC PWM");

    // LCD Backlight on GPIO15 (LowSpeed@20kHz)
    let mut t_bl = ledc.timer::<LowSpeed>(timer::Number::Timer2);
    t_bl.configure(timer::config::Config {
        duty: timer::config::Duty::Duty8Bit,
        clock_source: timer::LSClockSource::APBClk,
        frequency: Rate::from_khz(20),
    })
    .unwrap();
    let mut backlight = ledc.channel(channel::Number::Channel2, peripherals.GPIO15);
    backlight
        .configure(channel::config::Config {
            timer: &t_bl,
            duty_pct: 85,
            drive_mode: esp_hal::gpio::DriveMode::PushPull,
        })
        .unwrap();
    info!("LCD backlight set to 85% (20kHz)");

    info!("UPS main firmware booting…");
    info!("GPIO mappings: buttons center/up/right/down/left = 0/1/2/4/5");
    info!("I2C0 pins: SDA=GPIO8, SCL=GPIO9, INTn=GPIO7, USB2_PG=GPIO21");
    info!("SPI LCD pins: DC=GPIO10, MOSI=GPIO11, SCLK=GPIO12, CS=GPIO13, RST=GPIO14");
    info!("Fan control: EN=GPIO39, PWM=GPIO40; buzzer=GPIO38 (LEDC PWM)");

    // Keep fan disabled until thermal task claims it.
    fan_en.set_low();

    // Initialize LCD and draw boot UI once (non-blocking afterwards)
    info!("Initializing GC9D01 panel (160x50)...");
    if let Err(_) = display::init_async(&mut spi, &mut _cs, &mut _dc, &mut _rst).await {
        warn!("gc9d01: init failed");
    } else {
        let _ = ui::boot_init_begin(&mut spi, &mut _cs, &mut _dc);
        let _ = ui::boot_update(&mut spi, &mut _cs, &mut _dc, 5, "SPI/LCD Ready");
        info!("Boot UI rendered");
    }

    // Indicate power-management bring-up on the boot screen; the actual
    // I2C operations are performed in the background `power_task`.
    let _ = ui::boot_update(&mut spi, &mut _cs, &mut _dc, 40, "TCA6408A");
    let _ = ui::boot_update(&mut spi, &mut _cs, &mut _dc, 60, "SC8815 ADC Read");

    // === Temperature sensor init (TSENS delta calibration only) ===
    tsens::init(&mut delay);
    let delta_opt = tsens::read_delta_calibration();
    let delta_c = delta_opt.unwrap_or(0.0);
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

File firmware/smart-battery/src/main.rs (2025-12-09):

#![no_std]
#![no_main]

#[cfg(not(feature = "ship-mode"))]
mod bq76920_task;
#[cfg(not(feature = "ship-mode"))]
mod data_types;
// mod global_state; // removed to save flash; LEDs derive state locally
#[cfg(not(feature = "ship-mode"))]
mod activity;
#[cfg(not(feature = "ship-mode"))]
mod charger_control;
mod failsafe;
#[cfg(not(feature = "ship-mode"))]
mod i2c_slave;
#[cfg(not(feature = "ship-mode"))]
mod irq_mux;
#[cfg(not(feature = "ship-mode"))]
mod leds4_task;
#[cfg(not(feature = "ship-mode"))]
mod ntc_temp;
#[cfg(not(feature = "ship-mode"))]
mod sc8815_task;
#[cfg(not(feature = "ship-mode"))]
mod state_bits;
#[cfg(not(feature = "ship-mode"))]
mod tmp75;
// scheduler removed (合并到 failsafe + SC 路径)
#[cfg(not(feature = "ship-mode"))]
mod shared;
#[cfg(not(feature = "ship-mode"))]
mod sleep_manager;
#[cfg(not(feature = "ship-mode"))]
mod temp_policy;
#[cfg(not(feature = "ship-mode"))]
mod thermal;

pub const SB_VERSION: &str = env!("CARGO_PKG_VERSION");
pub const SB_GIT_HASH: &str = env!("SB_GIT_HASH");
pub const SB_BUILD_TS: &str = env!("SB_BUILD_TS");

use bq769x0_async_rs::{BatteryConfig, Bq769x0, Enabled as BqCrcEnabled};
// no direct info! logs to减小尺寸
use cortex_m_rt::ExceptionFrame;
use embassy_embedded_hal::shared_bus::asynch::i2c::I2cDevice;
use embassy_executor::Spawner;
#[cfg(not(feature = "ship-mode"))]
use embassy_stm32::exti::ExtiInput;
#[cfg(not(feature = "ship-mode"))]
use embassy_stm32::gpio::Pull;
#[cfg(not(feature = "ship-mode"))]
use embassy_stm32::i2c::SlaveAddrConfig;
use embassy_stm32::interrupt::typelevel::Interrupt as _;
use embassy_stm32::{
    bind_interrupts,
    gpio::{Level, Output, Speed},
    i2c::{self, Config as I2cConfig, I2c},
    peripherals::{I2C1, I2C2},
    time::Hertz,
};
use embassy_sync::blocking_mutex::raw::CriticalSectionRawMutex;
use embassy_sync::mutex::Mutex;
use embassy_time::{Duration, Instant, Timer};
use static_cell::StaticCell;

// Log reset cause so we can distinguish power-on, brown-out, watchdog and
// software resets when analysing field logs.
fn log_reset_cause() {
    let rcc = embassy_stm32::pac::RCC;
    let csr = rcc.csr().read();
    defmt::info!("reset: csr={:?}", csr);
    // Clearing reset flags is optional here; leave them latched so multiple
    // faults can be correlated if needed.
}

// Global exception traps so we can see where the core dies instead of silently
// stopping when the ESP32 starts talking to us over I2C.
#[cortex_m_rt::exception]
unsafe fn HardFault(ef: &ExceptionFrame) -> ! {
    let pc = ef.pc();
    let lr = ef.lr();
    defmt::error!("hardfault: pc=0x{:08x} lr=0x{:08x}", pc, lr);
    // In diagnostics builds keep the core parked here so that RTT logs are
    // flushed and the faulting PC/LR can be recovered from logs/ELF instead
    // of immediately resetting and losing context.
    loop {
        cortex_m::asm::bkpt();
    }
}

// Catch any unexpected core/peripheral exceptions that don't have a specific
// handler wired and reset instead of leaving the core parked in the vector
// table (which shows up as \"Firmware exited unexpectedly: Exception\").
#[cortex_m_rt::exception]
unsafe fn DefaultHandler(irqn: i16) -> ! {
    defmt::error!("default-exception: irqn={}", irqn);
    loop {
        cortex_m::asm::bkpt();
    }
}

#[cfg(not(feature = "ship-mode"))]
use shared::{Bq76920MeasurementsSubscriber, Sc8815MeasurementsSubscriber};

type RuntimeI2c = I2c<'static, embassy_stm32::mode::Async, i2c::mode::Master>;
type SharedI2cBus = Mutex<CriticalSectionRawMutex, RuntimeI2c>;

static I2C2_BUS: StaticCell<SharedI2cBus> = StaticCell::new();

#[cfg(feature = "ship-mode")]
const LED_CYCLE_MS: u64 = 300;
#[cfg(feature = "ship-mode")]
const LED_FLASH_MS: u64 = 250;

#[cfg(not(feature = "ship-mode"))]
const SHIP_BUTTON_HOLD_MS: u64 = 5_000;

#[cfg(feature = "ship-mode")]
fn led_on(pin: &mut Output<'static>) {
    pin.set_low();
}

#[cfg(feature = "ship-mode")]
fn led_off(pin: &mut Output<'static>) {
    pin.set_high();
}

async fn enter_ship_mode_now(
    i2c_bus: &'static SharedI2cBus,
    address: u8,
    sense_resistor_m_ohm: u32,
) -> bool {
    let i2c_dev = I2cDevice::new(i2c_bus);
    let mut bq: Bq769x0<I2cDevice<'static, CriticalSectionRawMutex, RuntimeI2c>, BqCrcEnabled, 5> =
        Bq769x0::new(i2c_dev, address, sense_resistor_m_ohm, None);
    defmt::info!("bq:ship enter");
    match bq.enter_ship_mode().await {
        Ok(_) => {
            defmt::info!("bq:ship ok");
            crate::failsafe::set_bq_online(false);
            true
        }
        Err(e) => {
            defmt::warn!("bq:ship err: {:?}", e);
            false
        }
    }
}

#[cfg(not(feature = "ship-mode"))]
#[embassy_executor::task]
async fn ship_button_task(
    mut button: ExtiInput<'static>,
    i2c_bus: &'static SharedI2cBus,
    address: u8,
) {
    loop {
        button.wait_for_rising_edge().await;
        // 简单消抖
        Timer::after(Duration::from_millis(30)).await;
        if !button.is_high() {
            continue;
        }

        let pressed_at = Instant::now();
        let deadline = pressed_at + Duration::from_millis(SHIP_BUTTON_HOLD_MS);
        while button.is_high() && Instant::now() < deadline {
            Timer::after(Duration::from_millis(50)).await;
        }

        if button.is_high() {
            defmt::info!("btn:ship long-press detected");
            crate::failsafe::request_pstop();
            let ship_ok = enter_ship_mode_now(i2c_bus, address, 3).await;
            defmt::info!("btn:ship result={}", ship_ok);
        }

        // 等待松开，避免重复触发
        button.wait_for_falling_edge().await;
    }
}

#[cfg(not(feature = "ship-mode"))]
#[embassy_executor::task]
async fn sc_meas_mirror_task(mut sub: Sc8815MeasurementsSubscriber<'static>) {
    loop {
        let meas = sub.next_message_pure().await;
        i2c_slave::update_sc_measurements(&meas);
    }
}

#[cfg(not(feature = "ship-mode"))]
#[embassy_executor::task]
async fn bq_meas_mirror_task(mut sub: Bq76920MeasurementsSubscriber<'static, 5>) {
    loop {
        let meas = sub.next_message_pure().await;
        i2c_slave::update_bq_measurements(&meas);
    }
}

// Fixed I2C address for BQ7692003PWR (7‑bit).
// Per TI device comparison table: the "03" variant uses CRC and a fixed
// I2C address 0x08. Other orderable numbers (e.g. BQ7692006) use 0x18.
const BQ76920_I2C_ADDR: u8 = 0x08;
use {defmt_rtt as _, panic_probe as _};

// (no build-id marker to save flash)

bind_interrupts!(struct I2c2Irqs {
    I2C2 => i2c::EventInterruptHandler<I2C2>, i2c::ErrorInterruptHandler<I2C2>;
});

// Bind I2C1 interrupts so the slave listen/respond paths can wake properly.
bind_interrupts!(struct I2c1Irqs {
    I2C1 => i2c::EventInterruptHandler<I2C1>, i2c::ErrorInterruptHandler<I2C1>;
});
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

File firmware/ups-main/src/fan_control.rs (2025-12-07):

use defmt::{debug, error, warn};
use esp_hal::{
    gpio::Output,
    ledc::{
        LowSpeed,
        channel::{self, ChannelIFace},
    },
};

use crate::tsens;

// Control loop sample period for temperature / fan updates.
// When used from an async main loop, prefer driving the outer loop timing
// with `embassy_time::Timer` so other tasks (e.g. button scanning) can
// continue to make progress between samples.
pub const SAMPLE_PERIOD_MS: u32 = 20;
const LOG_INTERVAL_TICKS: u8 = 100; // 20 ms * 100 ≈ 2 s
const FILTER_WINDOW: usize = 3;

#[derive(Clone, Copy, Debug, Default)]
pub struct SmartBatteryTemps {
    pub pack_c: Option<f32>,
    pub charger_c: Option<f32>,
    /// Per-pack NTC temperatures (0..3), if available.
    pub ntc_c: [Option<f32>; 4],
}

impl SmartBatteryTemps {
    pub fn new(pack_c: Option<f32>, charger_c: Option<f32>, ntc_c: [Option<f32>; 4]) -> Self {
        Self {
            pack_c,
            charger_c,
            ntc_c,
        }
    }

    pub fn highest(&self) -> Option<f32> {
        match (self.pack_c, self.charger_c) {
            (Some(a), Some(b)) => Some(a.max(b)),
            (Some(a), None) => Some(a),
            (None, Some(b)) => Some(b),
            (None, None) => None,
        }
    }
}

const TARGET_TEMP_C: f32 = 45.0;
const VIN_ON_THRESHOLD_C: f32 = 35.0;
const NOVIN_ON_THRESHOLD_C: f32 = 40.0;
const HYSTERESIS_C: f32 = 3.0;
const OVERTEMP_C: f32 = 80.0;

// fan_control_spec.md §3.2: PWM duty is inversely proportional to FAN_VCC
// (0% ≈ 5 V, 100% ≈ 1 V). Lower duty means stronger cooling.
const MIN_ACTIVE_DUTY: u8 = 96;
const DUTY_MAX: u8 = 100;
const DUTY_MIN: u8 = 0;
const SAFE_MODE_DUTY: u8 = 50;
const DUTY_SLEW_LIMIT: i8 = 5;

const PI_KP: f32 = 0.6;
const PI_KI: f32 = 0.08;
const INTEGRAL_LIMIT: f32 = 60.0;

const VOUT_BASE: f32 = 4.96;
const VOUT_GAIN: f32 = 3.98;

#[derive(Clone, Copy, PartialEq, Eq)]
pub enum Mode {
    Normal,
    Safe,
    Overtemp,
}

#[derive(Clone, Copy, PartialEq, Eq)]
enum FaultReason {
    TsensFault,
}

struct ControlOutcome {
    enabled: bool,
    duty: u8,
    immediate: bool,
    pi_active: bool,
}

pub struct FanController<'a> {
    fan_pwm: channel::Channel<'a, LowSpeed>,
    fan_en: Output<'a>,
    delta_c: f32,
    vin_present: bool,
    log_countdown: u8,
    mode: Mode,
    fault: Option<FaultReason>,
    filtered_temp: f32,
    control_temp: f32,
    battery_temps: Option<SmartBatteryTemps>,
    last_reading: Option<tsens::Reading>,
    filter_buf: [f32; FILTER_WINDOW],
    filter_count: usize,
    filter_index: usize,
    fan_enabled: bool,
    duty_pct: u8,
    pi_integral: f32,
}

/// Snapshot of the current fan-control state exposed to other tasks.
#[derive(Clone, Copy)]
pub struct FanStatus {
    pub mode: Mode,
    pub fan_enabled: bool,
    /// Raw PWM duty percentage written to the FAN_PWM channel (0–100).
    pub duty_pct: u8,
    /// Effective control temperature after combining all inputs.
    pub control_temp_c: f32,
    /// Filtered TSENS reading after calibration.
    pub tsens_filtered_c: f32,
}

impl Default for FanStatus {
    fn default() -> Self {
        Self {
            mode: Mode::Normal,
            fan_enabled: false,
            duty_pct: 0,
            control_temp_c: 0.0,
            tsens_filtered_c: 0.0,
        }
    }
}

impl<'a> FanController<'a> {
    pub fn new(
        fan_pwm: channel::Channel<'a, LowSpeed>,
        mut fan_en: Output<'a>,
        delta_opt: Option<f32>,
        vin_present: bool,
    ) -> Self {
        let delta_c = delta_opt.unwrap_or(0.0);
        // ChannelIFace::set_duty uses &self, so the owned channel can set idle duty pre-transfer.
        if fan_pwm.set_duty(DUTY_MAX).is_err() {
            warn!("fan.init: failed to set idle duty");
        }
        fan_en.set_low();
        if delta_opt.is_none() {
            warn!("fan.init: tsens calibration missing -> delta defaults to 0.0°C");
        }
        Self {
            fan_pwm,
            fan_en,
            delta_c,
            vin_present,
            log_countdown: LOG_INTERVAL_TICKS,
            mode: Mode::Normal,
            fault: None,
            filtered_temp: 0.0,
            control_temp: 0.0,
            battery_temps: None,
            last_reading: None,
            filter_buf: [0.0; FILTER_WINDOW],
            filter_count: 0,
            filter_index: 0,
            fan_enabled: false,
            duty_pct: DUTY_MAX,
            pi_integral: 0.0,
        }
    }

    pub fn set_vin_present(&mut self, present: bool) {
        self.vin_present = present;
    }

    pub fn tick(&mut self, reading: tsens::Reading, smart_batt_temp: Option<SmartBatteryTemps>) {
        let corrected = reading.base_celsius - self.delta_c;
        let filtered = self.push_sample(corrected);
        self.filtered_temp = filtered;
        self.battery_temps = smart_batt_temp;
        let controlling = match self.battery_temps.and_then(|t| t.highest()) {
            Some(ext) => ext.max(filtered),
            None => filtered,
        };
        self.control_temp = controlling;
        self.last_reading = Some(reading);

        self.update_outputs(controlling, &reading);
        self.maybe_log();
    }
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

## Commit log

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2025-05-25 feat(power-monitoring): add ina226 current/voltage monitoring support
    - Add ina226 crate dependency with async feature for power monitoring
    - Initialize INA226 sensor with 0x40 address on shared I2C bus
    - Implement current/voltage reading with error handling and unit conversion
    - Add PLAN.md documentation outlining implementation steps and architecture
    - Update submodule dependencies for embassy and bq76920
    The implementation includes proper error handling for I2C communication failures and demonstrates basic data conversion from raw values to millivolts/milliamps. The PLAN.md file provides visibility into future development steps and system architecture through mermaid diagrams.
    Signed-of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
    [main.rs]
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2025-05-29 refactor(data_types): Refactor data type serialization using binrw macro
    Removed manual implementation of BinRead and BinWrite traits for data types
    and replaced them with the #[binrw] macro for automatic derivation.
    [data_types.rs]
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2025-05-29 refactor(bq76920): Remove uom dependency and adapt bq76920 data handling
    This commit removes the (Units of Measurement) library dependency.
    Consequently, the following adjustments were made:
    - Updated the submodule to a version that no longer relies on .
    - Modified to use raw numerical values (e.g., mV, mA, microOhms) directly instead of types for voltage, current, temperature, and sense resistor.
    - Adjusted data structures and formatting in to reflect the absence of types.
    - Updated default current initialization in .
    [bq76920_task.rs, data_types.rs]
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2025-05-31 fix(usb): ensure correct data aggregation and enhance logging
    [main.rs]
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2025-05-31 feat(usb): Implement custom BinRead for UsbData and refine payload definition
    - Manually implement BinRead for UsbData enum to provide more robust deserialization logic and error handling for unknown magic bytes.
    - Remove BinRead derive from AllMeasurementsUsbPayload as it's not intended to be read directly via this derive on the device side.
    [data_types.rs]
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2025-07-23 feat: Replace BQ25730 with SC8815 and implement LED status indication
    Major changes:
    - Replace BQ25730 charger IC with SC8815 for 4S LiFePO4 battery charging
    - Add SC8815 task with proper configuration (300mA minimum current limits)
    - Implement LED status indication task with charging state detection
    - Add continuous SC8815 voltage/current monitoring and logging
    - Update data types and shared channels for SC8815 integration
    - Remove BQ25730 dependencies and related code
    - Add comprehensive LED status documentation
    Technical details:
    - SC8815 configured for 4S battery, 4.45V/cell, 300mA current limits
    - LED status based on VBUS voltage detection and EOC (End of Charge) flag
    - Continuous logg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
    [data_types.rs, led_status_task.rs, main.rs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]
2025-07-23 feat: enhance BQ76920 task with smart balancing and detailed monitoring
    - Migrate smart balancing algorithm from example code with safety mechanisms
    - Add comprehensive status monitoring including register states and protection thresholds
    - Improve code quality with better error handling and logging structure
    - Verified functionality on real hardware
    [bq76920_task.rs]
2025-07-23 feat: implement GPIO control for BQ76920 and SC8815
    - Add PA1 control for BQ76920 charge MOSFET (low level enables charging)
    - Add PB9 control for BQ76920 discharge MOSFET (low level enables discharging)
    - Add PC13 control for SC8815 PSTOP (low level + SC8815 init success + no comm failures = PSTOP low)
    - Implement proper PSTOP control logic with initialization and communication failure tracking
    - Add GPIO pin configurations with pull-up resistors
    - Update task signatures and function calls to support new GPIO controls
    - Optimize memory usage for debug build compatibility
    - Apply rustfmt code formatting
    - Verify functionality through debug build testing
    [bq76920_task.rs, data_types.rs, led_status_task.rs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]
2025-07-24 feat: improve cell balancing status display and remove unnecessary logs
    - Remove UV_TRIP and OV_TRIP register logging and voltage calculations
    - Add CELLBAL1 register reading and display in binary format
    - Show which cells are currently balancing
    - Clean up unused variables to fix compiler warnings
    [bq76920_task.rs]
2025-07-28 feat: implement SC8815 external resistor charging configuration
    - Configure SC8815 to use external resistor voltage setting mode
    - Fix VBAT ADC measurement ratio for external mode in driver
    - Add manual VBAT monitor ratio setting method to SC8815 driver
    - Remove PC13 PSTOP control, implement battery voltage safety checks
    - Add charging enable logic with 18V voltage limit protection
    - Increase charging current limits to 1A for faster charging
    - Optimize code size to fit in Flash memory constraints
    - Add comprehensive documentation for external resistor configuration
    Key changes:
    - use_internal_setting = false for external resistor mode
    - Proper 12.5x ADC ratio for >10.24V battery application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
    [main.rs, sc8815_task.rs]
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2025-09-13 feat(arch): restructure and initialize smart-battery (STM32L051C8T6) with LSE and probe-rs\n\n- Split workspace into firmware/smart-battery and firmware/ups-main\n- Port smart-battery from STM32G431 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
    [bq76920_task.rs, charger_task.rs, data_types.rs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]
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2025-09-17 fix(firmware): lock BQ7692003 to 0x08 and ensure CRC path\n\n- Use fixed 7-bit I2C addr 0x08 for BQ7692003 (CRC variant)\n- Keep CRC-enabled driver paths; verified against TI datasheet rules\n- Updat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
    [bq76920_task.rs, data_types.rs, main.rs]
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2025-09-18 feat: tighten sc8815 control and update sensing
    - refactor the sc8815 task to manage CE/PSTOP sequencing, publish charger expectations and confirmations, and clear faults aggressively
    - plumb the new charger status fields through shared types, LED indication, and main task wiring while refreshing the software design doc
    - move the workspace release profile into the root manifest and switch both firmware configs to the new 10 mΩ shunt values; the charging behaviour still needs further tuning
    [bq76920_task.rs, charger_task.rs, data_types.rs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]
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2025-09-20 chore(power): raise SC8815 IBAT to ~425mA and IBUS to 1A\n\n- Set IBAT limit to 425mA (~422mA effective due to quantization @12x,10mΩ)\n- Set IBUS limit to 1000mA to avoid input-side throttling\n- Ke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
    [bq76920_task.rs, sc8815_task.rs]
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2025-09-20 feat(balancing): couple balancing to charger presence and CV hold; stop on adapter loss\n\n- Gate balancing execution by adapter presence with retry holdoff\n- Publish BalancingCvRequest to keep char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
    [bq76920_task.rs, data_types.rs, main.rs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]
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2025-09-20 fix(balancing): force-clear hardware balancing when adapter absent; compute CV request from HW bits and cell spread\n\n- Stop any residual BAL bits when adapter not present\n- Track CELLBAL1 snapshot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
    [bq76920_task.rs, led_status_task.rs, sc8815_task.rs]
2025-09-20 feat(log): unify SC/BQ logs; add BQ fault summary + balance status\n\nSC\n- Standardize event lines: "POL start/stop", "SC stat/gates"\n- Add one-line "SC snap": VBUS/VBAT/IBUS/IBAT\n- Decode diag co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
    [bq76920_task.rs, sc8815_task.rs]
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2025-09-20 fix(led/balancing): decouple LED overlay from CV request; overlay only when HW balancing active; trigger immediate eval when holdoff expires
    [bq76920_task.rs, data_types.rs, led_status_task.rs]
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2025-09-20 feat(log): include bal_cell=X in BQ snap line and remove boolean bal flag for clearer balancing visibility
    [bq76920_task.rs]
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2025-09-20 chore(sc8815): de-noise POL start and pause logs; edge-only messages\n\n- Log POL start only on rising edge of start condition.\n- Log paused gating (OV / +IMB) only when the pause-state tuple change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
    [sc8815_task.rs]
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2025-09-26 feat(smart-battery): robust SLEEP policy with I2C wake + 8s sliding holdoff and human-readable logs\n\n- Add sleep manager with strict busy-guard wake + wake-latch to catch ultra-short I2C transactio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
    [bq76920_task.rs, charger_task.rs, data_types.rs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]
2025-09-26 feat(smart-battery): enable low-power SLEEP (WFE); restore LED task
    - Replace STOP-mode path with thread-mode executor (no STOP)
    - Reinstate sleep_manager for light sleep with idle/holdoff
    - Keep I2C1 slave + NVIC enabled for wake-on-activity
    - Restore LED status task on PA5 to retain user-visible status
    - Trim logs to reduce wakeups/flash; no protocol/charger logic changes
    Build: verified with 'make sb-build'
    [main.rs]
2025-09-26 fix(charging): break quiesce deadlock and enable AC detection while idle
    - GlobalState: when quiesced, tick every 250ms instead of blocking, so AC changes can be published
    - SC8815 task: while quiesced, perform low-rate status probe via parked I2C and publish alerts
    - Avoids situation where AC presence can never be detected and LED stays off
    Safety: does not start charger without BQ; only status probe (no ADC, no power stage)
    [sc8815_task.rs]
2025-09-26 fix(global-state): derive 'preparing' from BQ measurements when AC is absent
    - Subscribe to BQ76920 measurements in GlobalState
    - Use BQ total voltage to decide preparing-to-charge (fallback to SC if missing)
    - Helps LED show preparing pulses even when SC is quiesced
    [main.rs]
2025-09-26 fix(bq76920): attempt init on 0x08 then 0x18 (fallback for variant)
    [main.rs]
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2025-09-27 fix(sc8815-probe): pulse CE low during quiescent status probe with PSTOP high
    - Ensures device responds to I2C for AC detection even when session parked
    - Keep power stage disabled (PSTOP=High), CE only for ~20ms
    - Logs AC edge via INFO sc:probe ac=...
    [sc8815_task.rs]
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2025-09-27 fix: remove leftover Signal wait; use 100ms tick in quiescent path
    [sc8815_task.rs]
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2025-09-29 feat(leds): introduce 4-LED status task + I2C1 async pulse\n\n- Replace legacy single-LED task with 4-LED compositor per SOFTWARE_DESIGN.md\n- Green: base=ON (normal)/OFF (Sleep), async pulse on I2C1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
    [charger_task.rs, leds4_task.rs, main.rs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]
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2025-09-29 feat(leds,fail-safe): yellow 1Hz dropout + BQ 3x-fail PSTOP latch\n\n- Yellow: 1 Hz blink on SC8815 dropout (no new subscribers; derive via SC heartbeat timestamp)\n- Green/Red/Blue unchanged from pr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
    [bq76920_task.rs, charger_task.rs, leds4_task.rs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]
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2025-09-29 refactor(power): inline quiesce logic and remove scheduler task\n\n- Move AC-present→QUIESCE gating into failsafe + SC task\n- Replace scheduler::is_quiesced() with failsafe::is_quiesced()\n- Stop sp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
    [bq76920_task.rs, main.rs, sc8815_task.rs]
2025-09-29 refactor(leds): drop GlobalState dependency; LED derives state locally\n\n- LEDs subscribe to: BQ alerts/measure, SC alerts, BalancingCv; remove GS subscriber\n- Yellow: base=AC&&(expected||confirmed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
    [bq76920_task.rs, leds4_task.rs, main.rs]
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2025-09-29 feat(leds): map red/yellow fault pulse codes to HW flags\n\n- Red pulses: 3=SCD, 4=OCD, 2=UV/OV, 1=balancing overlay\n- Yellow pulses: 2=VBUS short, 4=OTP, 1=preparing (!AC && VBAT<17V)\n\nSize: flas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
    [leds4_task.rs]
2025-09-29 refactor(smart-battery): clean warnings and unify LED message reads\n\n- Remove unused vars (pol_start_latched, ship_mode_pulsed)\n- Drop unused Sc8815MeasurementsSubscriber alias\n- Read SC/BQ alert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
    [leds4_task.rs, main.rs, sc8815_task.rs]
2025-09-30 feat(sc8815): enhance pause policy with per-fault cooldowns and 1 Hz timers\n\n- OV=180s, UV=10s, OCD/SCD=30s; all gate PSTOP and keep session\n- Publish paused flag when any cooldown is active (LED 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
    [sc8815_task.rs]
2025-09-30 fix(leds,main): drive LEDs as push-pull outputs; keep Embassy spawn tokens unwrapped before spawn\n\n- Use (push-pull) for LED pins; active-low logic intact\n- Restore correct pattern: for all tasks\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
    [leds4_task.rs, main.rs]
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2025-09-30 fix(main): start LEDs and IRQ tasks before BQ init; spawn SC task early\n\n- LED task runs immediately to show dropout 1 Hz blink\n- Start SC/BQ IRQ handlers up front\n- Spawn SC task even without BQ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
    [main.rs, sc8815_task.rs]
2025-09-30 docs(smart-battery): unify net names to CE_CTL/PSTOP_CTL and add truth table\n\n- Replace CE_OUT/PSTOP_OUT with CE_CTL/PSTOP_CTL\n- Add MCU→chip truth table for clarity\n- Align mandatory actions to 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
    [sc8815_task.rs]
2025-09-30 feat(sc8815): boot-probe init and enforce CE/PSTOP semantics (inverted)
    - Probe SC8815 at boot regardless of BQ state; keep PSTOP_CTL=L (stop)
    - CE_CTL: High=enable, Low=disable (via inversion); session enter/exit wired
    - PSTOP_CTL: Low=stop, High=allow; unify all stop/pause/dropout paths to Low
    - Online detection: devices marked online at boot if probe succeeds; later dropout only on timeout
    - Docs: add chip-level PSTOP semantics; keep net names CE_CTL/PSTOP_CTL
    Size: flash image 62,872 bytes (.bin); sections: text=56,440, rodata=6,168, data=80, bss=4,360.
    [sc8815_task.rs]
2025-09-30 feat(status): decouple LED dropout from heartbeats; add online flags\n\n- failsafe: add SC/BQ online flags and accessors\n- sc8815: set online on probe/success; clear on 3x comm error\n- bq76920: set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
    [bq76920_task.rs, leds4_task.rs, sc8815_task.rs]
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2025-10-06 fix(bq76920): decouple sampling cadence from AC quiesce to ensure 60s safety sampling always runs
    [bq76920_task.rs]
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2025-10-06 fix(smart-battery): resolve clippy lints (derive Default, remove casts, collapse ifs, refactor state flags, adjust pulses)
    [data_types.rs, leds4_task.rs, sc8815_task.rs]
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2025-10-06 fix(led/dropout): set BQ online on successful silent-ALERT sampling to prevent false 1Hz red LED blink
    [bq76920_task.rs]
2025-10-06 fix(smart-battery): use 1s cadence only during active balancing or charging phase; avoid high-frequency logs when AC absent
    [bq76920_task.rs, main.rs, sc8815_task.rs]
2025-10-06 chore(bq): make silent online log one-shot to avoid spam during quiesce
    [bq76920_task.rs]
2025-10-06 chore: add fw:boot banner and clarify balancing log label to avoid confusion
    [main.rs]
2025-10-06 fix(ci): remove remaining conflict markers in sc8815_task; include temp_pause in pause_active consistently
    [bq76920_task.rs, data_types.rs, sc8815_task.rs]
2025-10-06 fix(smart-battery): remove duplicate Default derive for BalancingCvRequest to resolve CI E0119
    [data_types.rs]
2025-10-06 fix(smart-battery): satisfy clippy and fmt for temp protection (range.contains, remove unused mut)
    [bq76920_task.rs, data_types.rs]
2025-10-07 fix(smart-battery): stop balancing on temp pause; red LED=6 pulses
    - Block balancing when temp_pause_active=true; withdraw CV requests during pause\n- Immediately stop active HW balancing on temp pause (log bal:stop temp_pause)\n- Red LED uses dedicated 6-pulse code for temperature pause; remove FET-not-both-on pulse mapping to avoid semantic overlap\n- Update SOFTWARE_DESIGN.md codebook accordingly
    [bq76920_task.rs, leds4_task.rs]
2025-10-07 fix(sc8815): gate charge start during temp pause to stop start-vb thrash
    - Add !temp_pause_cmd to pol_start_cond and enable branch\n- Prevents 100 ms re-enable attempts while temp pause is active
    [sc8815_task.rs]
2025-10-07 fix(leds): remove unused variable in red LED composer (clippy -D warnings)
    [leds4_task.rs]
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2025-10-08 fix(smart-battery): correct ADIN resume condition to code>=297 at 5V; edge-only RESUME/HOT/COLD logs; compress defmt strings to fit flash; include temp/BQ pause in gating bitset
    [sc8815_task.rs]
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2025-10-08 fix(smart-battery): assume VCC_SC≈5V for ADIN; use 5V hot-stop threshold (code<=220 ~50C) and 5V LUT for logs
    [sc8815_task.rs]
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2025-10-08 fix(smart-battery): select ADIN VCC mapping by power-stage state (PSTOP): run=3V, stop=5V; re-apply 50C hot-stop at 3V; keep minimal logs
    [sc8815_task.rs]
2025-10-08 fix(smart-battery): run-mode uses 5V ADIN mapping (50C=>code<=220); keep stop-mode resume at 5V; add minimal adin logs
    [sc8815_task.rs]
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2025-10-08 fix(smart-battery): add VCC_SC drop settle window (1s) after temp HOT; evaluate stop-mode resume/cold at 3V only after settle to prevent HOT↔RESUME chatter
    [sc8815_task.rs]
2025-10-09 fix(smart-battery): extend VCC_SC drop settle window to 10s before applying 3V-based resume/cold checks (prevents HOT↔RESUME chatter)
    [sc8815_task.rs]
2025-10-09 fix(smart-battery): latch cold inhibit and release only when >=0C after settle; separate hot vs cold resume paths; keep 10s settle window
    [sc8815_task.rs]
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2025-10-09 fix(smart-battery): robust ADIN temp gating; run=5V hot-stop, stop=3V resume with 10s settle; add edge logs; align docs
    [leds4_task.rs, sc8815_task.rs]
2025-10-09 docs(sc8815): correct VCC_SC mapping comments (run=5V, stop=3V) and selector note
    [sc8815_task.rs]
2025-10-10 perf(sc8815): update submodule to fixed-point math
    - Flash -~2.4 KiB (cargo bloat)
    - Pull in driver change removing float intrinsics
    - No behavior or defmt text changes
    [main.rs]
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2025-10-11 fix(clippy): resolve -D warnings for CI
    - Remove unnecessary casts (u64->u64, u16->u16)
    - Initialize BatteryConfig fields via struct literal
    - No behavior/log changes; local build ok
    [main.rs]
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2025-10-12 feat(smart-battery): dropout blink + timeout-driven failures
    - Wrap BQ read_all_measurements and SC get_device_status with 2 s timeouts; classify timeout as failure to update online flags.
    - Update LED logic (red/yellow dropout) and docs (SOFTWARE_DESIGN.md).
    [bq76920_task.rs, sc8815_task.rs]
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2025-10-18 fix(bq76920): preserve ACTIVE_BQ during quiesced cycle to avoid 1 Hz red flicker
    Red LED base derives from ACTIVE_BQ. In quiesced/no‑AC fast path, ACTIVE_BQ was being cleared early and restored at tick end, causing a narrow once‑per‑second ON window that looks like a short pulse (duty≈2–4%). Keep previous ACTIVE_BQ when refreshing flags in that branch; decide ACTIVE_BQ only at the unified end‑of‑tick update.
    Also keeps earlier diagnostics in leds4_task (duty/base/p) and failsafe (bq:online edges) to aid field verification.
    [bq76920_task.rs, leds4_task.rs]
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2025-11-03 fix(ups-main): align eFuse TEMP_CALIB sign with IDF (BIT8=negative); report correct calibrated die temperature
    [tsens.rs]
2025-11-03 fix(ups-main): set TSENS XPD_FORCE=3 (always-on) to match IDF LL; keep CLK_DIV=6 and -10..80°C range
    [tsens.rs]
2025-11-03 fix(ups-main): reassert POWER_UP/POWER_UP_FORCE and delay before DUMP_OUT; poll READY with longer wait; clear DUMP_OUT after read
    [tsens.rs]
2025-11-03 fix(ups-main): harden TSENS bring-up and one-shot read on ESP32-S3
    - Use SENS regs with proper power/clock, XPD_FORCE and REGI2C ENT_TSENS; lock DAC to -10..80°C (0x05).
    - Read full CTRL register bits to avoid PAC field width quirks; add READY/out diagnostics; clear POWER_UP_FORCE between shots.
    - Log eFuse TEMP_CALIB raw bits and parsed delta_T; apply IDF-aligned conversion constants; print once per second.
    - Keep full board bring-up intact (GPIOs, I2C, SPI, LEDC fan/buzzer) to avoid breaking UPS functions.
    [tsens.rs]
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2025-11-03 feat(ups-main): improve TSENS bring-up and UART logging
    Keep buzzer/fan idle to avoid thermal bias during temperature validation.
    Set TSENS DAC offset=0 (reg 0x0F) for -10..80°C range; update DAC mapping table from ESP-IDF.
    Print calibration delta and samples via UART (println!) in addition to defmt.
    Refine eFuse debug logging and default DAC offset fallback to 0.
    [main.rs, tsens.rs]
2025-11-03 fix(ups-main): use defmt logging only
    Replace UART println! usage with defmt info! records during TSENS bring-up.
    Keep esp_println linked for defmt bridge and remove redundant formatting comments.
    [main.rs, tsens.rs]
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2025-11-03 fix(ups-main): one-shot STM I2C validation aligned with fix/sb-comm-failure
    - drop tca6408a-async path dep; inline minimal TCA6408A ops
    - ensure build without external local crates
    [io_expander.rs, main.rs]
2025-11-03 fix(ups-main): set I2C0 to 100kHz for STM32 slave compatibility during one-shot validation
    [main.rs]
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2025-11-04 feat(ups-main): integrate smart-battery temps into fan control and add consolidated logging
    - Read sb_pack/sb_mos from STM32 slave 0x14..0x17 via simple register read (no CRC).
    - Use max(TSENS, sb_highest) as control temp; log tsens, sb_pack, sb_mos, sb_highest, duty and Vout in single line.
    - Prefix logs with sb_* to avoid ambiguity; remove CRC-based frame parsing; keep CRC8 helper reserved.
    feat(smart-battery): expose hottest and TS1 temps via I2C register map
    - Map hottest -> 0x14/0x15, TS1 -> 0x16/0x17 (0.01°C i16).
    [fan_control.rs, i2c_slave.rs, main.rs]
2025-11-04 refactor(ups-main): use single-instance SC8815 via shared bus
    Adopt embedded-hal-bus RefCellDevice; maintain Option<SC8815> and init-once flag; avoid re-init thrash; keep CE gating via TCA.
    [io_expander.rs, main.rs, sc8815_task.rs]
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2025-11-05 feat(ups-main): integrate boot UI progress with staged hardware init
    - Keep mainline control loop (I2C selfcheck, TCA6408A, SC8815, TSENS, fan) intact
    - Restore display/ui modules; backlight PWM on GPIO15 (20kHz@85%)
    - SPI Mode 0 @ 6MHz for stability; vendor init sequence
    - Boot progress shows: SPI/LCD, STM32 selfcheck, GPIO/LEDC, TCA6408A, SC8815, TSENS, Ready
    [display.rs, main.rs, ui.rs]
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2025-11-05 feat(ups-main): dashboard shows real external temp and pack SoC
    - Render dashboard after init; refresh every 1s
    - SoC: fixed thresholds 12.5V empty / 18.5V full (pack), linear clamp
    [main.rs]
2025-11-05 feat(ui): alternate SoC% and voltage in battery area
    Implement alternating top-right battery display between percent and voltage with 2s cadence; ensure MODE text is clipped to avoid overlap.
    docs(ui): update UI spec to document alternating display, widths (4/5 cells), color rules (percent thresholds, voltage ORANGE), and overlap handling.
    [main.rs, ui.rs]
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2025-11-29 fix(smart-battery): align slow charge current with sc8815 minimum
    Set Slow tier IBAT limit to 330mA based on SC8815 datasheet 300mA minimum and current board parameters (RS2=10mΩ, IBAT_RATIO=12x). Share the same minimum limit with imbalance recovery to keep behaviour consistent and avoid future re-derivation mistakes.,timeout_ms:100000,
    [sc8815_task.rs]
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2025-11-29 fix(charging): enforce AC stability window and improve sb comms
    Document ESP32-side UPS charging policy, gate MANUAL_ENABLE on 10s stable IN_PG and add diagnostics/fallback for smart-battery VBAT reads and STM32 I2C.
    [i2c_slave.rs, main.rs]
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2025-12-04 fix(smart-battery): stabilize temp window telemetry
    Ensure STM32 thermal snapshot populates 0x40-0x47 with valid int8 temps in steady state.
    [i2c_slave.rs, sc8815_task.rs]
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2025-12-06 fix(smart-battery): seed legacy temp regs with sentinel
    Initialize 0x14..0x17 with TEMP_INVALID_0_01C so legacy hosts polling the old centi-degree temps never see a permanent 0°C reading.
    Test: just sb-build; just ups-flash; just sb-flash
    [i2c_slave.rs]
2025-12-06 fix(smart-battery): reduce hot-path logging and trap faults
    Keep HardFault/DefaultHandler parked in a breakpoint loop so we can recover PC/LR from defmt logs and addr2line instead of immediately resetting and losing context.
    Downgrade I2C slave and thermal policy logs from INFO to debug and disable I2C diagnostics by default to avoid RTT flooding in release builds.
    [bq76920_task.rs, i2c_slave.rs, main.rs]
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2025-12-06 chore(smart-battery): log RCC reset cause at boot
    Print RCC CSR once per boot so host-side Exception events can be correlated with POR/BOR/watchdog/software reset flags in future logs.
    [main.rs]
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2025-12-07 fix(smart-battery): sample all pack ntcs and log raw temps
    Extend ntc_temp_task to read 4 channels (PA0..PA3) behind PB12-gated NTC_3V3 and log raw ADC codes for diagnostics.
    [ntc_temp.rs]
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
